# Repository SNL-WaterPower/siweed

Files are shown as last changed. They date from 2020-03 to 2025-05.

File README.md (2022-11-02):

<!-- TABLE OF CONTENTS -->
## Table of Contents

* [About the Project](#about-the-project)
* [Getting Started](#getting-started)
  * [Prerequisites](#prerequisites)
  * [Installation](#installation)
  *	[Running the GUI](#running-the-gui)
* [System Layout](#System-layout)
* [System Specifications](#System-Specifications)
* [Roadmap](#roadmap)

<!-- ABOUT THE PROJECT -->
## About The Project

The Sandia Interactive Wave Energy Education Display (SIWEED) is a small portable wave tank to be used for outreach and engagement on wave energy converters (WECs) and, in particular, WEC control.
Check out these videos to get a better idea of what SIWEED's all about:

 - [SIWEED video](https://youtu.be/PcOHZWLTsHc)
 - [SIWEED live demonstration](https://digitalops.sandia.gov/Mediasite/Play/bbe17add12244893bdbcaecbce89f8881d)

If you're interested in building your own SIWEED, check out the [Getting Started](#getting-started) section of this README.
(We're working on a paper for [*HardwareX*](https://www.hardware-x.com/) that will hopefully provide an even better guide along with some data analysis from using the system.)
If you're an educator or student in need of teaching materials/activities, checkout out the [Educational Materials document](https://github.com/SNL-WaterPower/siweed/blob/master/educational_material.md).

<!-- GETTING STARTED -->
## Getting Started

### Prerequisites
- SIWEED requires 
	- [Arduino IDE 1.8.13](https://www.arduino.cc/en/main/software) or higher for programming Arduinos
		- Libraries are included in the repo. Many are modified, so you need to use the versions in the repo.
		- Arduino SAM boards package
	- [Processing IDE 3.5.4](https://processing.org/download/) for programming the GUI
		- Libraries are included in the repo. Many are modified, so you need to use the versions in the repo.
	- [OSSI Interface](https://www.oceansensorsystems.com/products.htm) for configuring Wave Probes, if equipped.

### Installation

1. Download the latest version of [Arduino IDE](https://www.arduino.cc/en/main/software) 
2. Download version 3.5.4 of [Processing IDE](https://processing.org/download/)
2.5. If using wave probes, download latest version of [OSSI Interface](https://www.oceansensorsystems.com/products.htm)
3. Download the [Master SIWEED Repository](https://github.com/SNL-WaterPower/siweed/tree/master)
4. Change the Sketchbook Location for the Arduino IDE to \siweed\Arduino
```
Open Arduino IDE
Change the location of your sketchbook folder to ~\siweed\Arduino at File > Preferences > Sketchbook location to 
Ex: C:\Users\user\Documents\GitHub\siweed\Arduino
```
5. Change Arduino IDE board to "Arduino Due Programming Port"
```
This can be found at Tools > Board > Arduino ARM(32 - bits) Boards > Arduino Due Programming Port

If you do not see the Arduino ARM(32 - bits) Boards, you need to install the SAM boards package by going to tools > board > boards manager, searching SAM, 
and installing the SAM package.
```
6. Upload the sketches to the Arduinos
```
With the Arduinos connected, select a port in tools > port, be sure to choose a port with an arduino plugged in. Go to file > sketchbook, and open WaveMaker_Controller.
Upload the sketch. 

Switch the port to the other arduino, and open WEC_Controller. Upload the sketch. That is all for the arduinos, you can close the IDE if you wish.
```
7. Open the Processing IDE Change Sketchbook Location to \siweed\Processing
```
Open Processing IDE
Change the location of your sketchbook folder to ~\siweed\Processing at File > Preferences > Sketchbook location to 
Ex: C:\Users\user\Documents\GitHub\siweed\Processing
```
<!-- Running the GUI -->
### Running the GUI
1. Open processing.exe 
2. File > Open > siweedGUI.pde (Ex: C:\Users\user\Documents\GitHub\siweed\Processing\siWeedGUI\siweedGUI.pde)
3. (optional)Edit modifiers. These are booleans at the top of the code that will do things like enable basic mode, debugging, or data logging.
4. If using wave probes: edit the port names in the modifiers to match the ports of your probes. The port names can be found in the device manager, or using the OSSI Interface program. Also within the OSSI Interface program, the tempurature output of any probes needs to be turned off, and the baud rate should be set to 30hz.
5. Click "Run"
6. The GUI will open, allow some time for it to load.

<!-- System layout -->
## System layout
SIWEED uses a PC to control two Arduino Dues: (1) to run the wavemaker and (2) to run the WEC.
A detailed illustration of the system layout is shown in the diagram below.

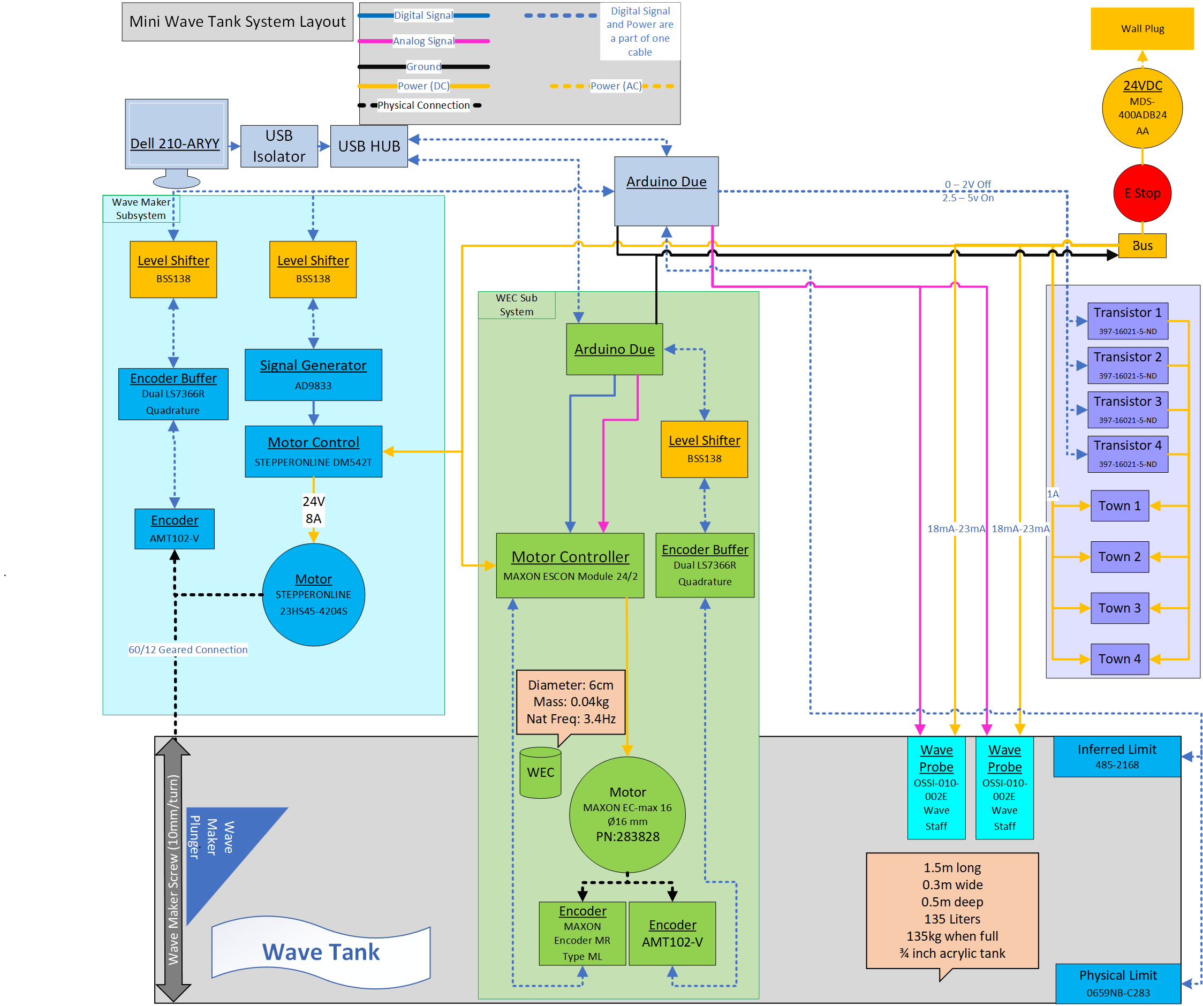
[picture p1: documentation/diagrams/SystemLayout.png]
system layout

<!-- System Specifications -->
## System specifications
 - Tank
 	- 3/4 inch acrylic tank
 	- Inner dimension: 1.5m x 0.3m x 0.5m (filled to ~0.3m deep)
 	- Mass of water: 135 kg (~300lbs)
 	- Mass of dry tank: ?
 	- Volume: 135 L (~36 gal)
 - WEC: 
 	- Diameter: 12 cm
   	- Mass: 0.04 kg list item		!!needs updating
   	- Natural frequency: ~3.4 Hz list item	!!needs updating
 - System update rates:
 	- Processing (GUI): 30 Hz
 	- Arduinos:
 		- Wave maker
 			- General: 100 Hz
 			- Serial communication: 30 Hz
 		- WEC
 			- General: 100 Hz
 			- Serial communication: 30 Hz
	-Wave Probes: 30Hz

<!-- ROADMAP -->
## Roadmap

See the [open issues](https://github.com/SNL-WaterPower/siweed/issues) for a list of proposed features (and known issues).

## Copyright and license
Copyright 2021 National Technology & Engineering Solutions of Sandia, LLC (NTESS).
Under the terms of Contract DE-NA0003525 with NTESS, the U.S. Government retains certain rights in this software.
The software is distributed under a [GNU General Public License](COPYING).

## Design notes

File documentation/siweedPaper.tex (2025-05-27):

%  LaTeX support: latex@mdpi.com 
%  For support, please attach all files needed for compiling as well as the log file, and specify your operating system, LaTeX version, and LaTeX editor.

%=================================================================
\documentclass[hardware,article,submit,pdftex,moreauthors]{Definitions/mdpi} 

%--------------------
% Class Options:
%--------------------
%----------
% journal
%----------
% Choose between the following MDPI journals:
% acoustics, actuators, addictions, admsci, adolescents, aerobiology, aerospace, agriculture, agriengineering, agrochemicals, agronomy, ai, air, algorithms, allergies, alloys, analytica, analytics, anatomia, animals, antibiotics, antibodies, antioxidants, applbiosci, appliedchem, appliedmath, applmech, applmicrobiol, applnano, applsci, aquacj, architecture, arm, arthropoda, arts, asc, asi, astronomy, atmosphere, atoms, audiolres, automation, axioms, bacteria, batteries, bdcc, behavsci, beverages, biochem,
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

% Contact information of the corresponding author
\corres{Correspondence: rcoe@sandia.gov}

% Current address and/or shared authorship
% \firstnote{Current address: Affiliation.}  % Current address should not be the same as any items in the Affiliation section.
% \secondnote{These authors contributed equally to this work.}
% The commands \thirdnote{} till \eighthnote{} are available for further notes

%\simplesumm{} % Simple summary

%\conference{} % An extended version of a conference paper

% Abstract (Do not insert blank lines, i.e.,~\\) 
\abstract{
Wave energy converters are a nascent energy generation technology that harnesses the power in ocean waves.
To assist in communicating both fundamental and complex concepts of wave energy, a small-scale portable wave tank and wave energy converter have been developed.
The system has been designed using commercial off-the-shelf components, and all design hardware and software are openly available for replication.
This project builds on prior research conducted at Sandia National Laboratories, particularly in the areas of WEC device design and control systems.
By showcasing the principles of causal feedback control and innovative device design, SIWEED not only serves as a practical demonstration tool but also enhances the educational experience for users.
This paper presents the detailed system design of this tool.
Furthermore, via testing and analysis, we demonstrate the basic functionality of the system.
}

% Keywords
\keyword{wave energy; educational; outreach} 

% The fields PACS, MSC, and JEL may be left empty or commented out if not applicable
%\PACS{J0101}
%\MSC{}
%\JEL{}

%%%%%%%%%%%%%%%%%%%%%%%%%%%%%%%%%%%%%%%%%%
% Only for the journal Diversity
%\LSID{\url{http://}}

%%%%%%%%%%%%%%%%%%%%%%%%%%%%%%%%%%%%%%%%%%
% Only for the journal Applied Sciences
%\featuredapplication{Authors are encouraged to provide a concise description of the specific application or a potential application of the work. This section is not mandatory.}
%%%%%%%%%%%%%%%%%%%%%%%%%%%%%%%%%%%%%%%%%%

%%%%%%%%%%%%%%%%%%%%%%%%%%%%%%%%%%%%%%%%%%
% Only for the journal Data
%\dataset{DOI number or link to the deposited data set if the data set is published separately. If the data set shall be published as a supplement to this paper, this field will be filled by the journal editors. In this case, please submit the data set as a supplement.}
%\datasetlicense{License under which the data set is made available (CC0, CC-BY, CC-BY-SA, CC-BY-NC, etc.)}

%%%%%%%%%%%%%%%%%%%%%%%%%%%%%%%%%%%%%%%%%%
% Only for the journal Toxins
%\keycontribution{The breakthroughs or highlights of the manuscript. Authors can write one or two sentences to describe the most important part of the paper.}

%%%%%%%%%%%%%%%%%%%%%%%%%%%%%%%%%%%%%%%%%%
% Only for the journal Encyclopedia
%\encyclopediadef{For entry manuscripts only: please provide a brief overview of the entry title instead of an abstract.}

%%%%%%%%%%%%%%%%%%%%%%%%%%%%%%%%%%%%%%%%%%
% Only for the journal Advances in Respiratory Medicine and Smart Cities
%\addhighlights{yes}
%\renewcommand{\addhighlights}{%

%\noindent This is an obligatory section in “Advances in Respiratory Medicine'' and ``Smart Cities”, whose goal is to increase the discoverability and readability of the article via search engines and other scholars. Highlights should not be a copy of the abstract, but a simple text allowing the reader to quickly and simplified find out what the article is about and what can be cited from it. Each of these parts should be devoted up to 2~bullet points.\vspace{3pt}\\
%\textbf{What are the main findings?}
% \begin{itemize}[labelsep=2.5mm,topsep=-3pt]
% \item First bullet.
% \item Second bullet.
% \end{itemize}\vspace{3pt}
%\textbf{What is the implication of the main finding?}
% \begin{itemize}[labelsep=2.5mm,topsep=-3pt]
% \item First bullet.
% \item Second bullet.
% \end{itemize}
%}

%%%%%%%%%%%%%%%%%%%%%%%%%%%%%%%%%%%%%%%%%%
\begin{document}

%%%%%%%%%%%%%%%%%%%%%%%%%%%%%%%%%%%%%%%%%%
\section{Introduction}
Wave energy converters (WECs) have the potential to deliver renewable energy to the grid or other autonomous power demands~\cite{Hagerman:2011aa,Clement2002,FALCAO2010899}.
Research and development in this field have produced some notable improvements in WEC performance, but~the technology is still in a developmental phase and has not achieved broad adoption.
The Sandia Interactive Wave Energy Education Display (SIWEED; a video showing the system in operation is available online: %MDPI: 1. Footnotes are not supported in our journal. We have therefore included this paragraph in the main text. Please confirm. 2. Please add the access date for ALL URLs (Format: Date Month Year). e.g., (accessed on 1 January 2020). It should be before the accepted date. The following highlights are the same. %RGC: ok
 \url{https://youtu.be/PcOHZWLTsHc?si=CzyYw3yEPqnsiVeV}, access date: 23 May 2025) is a small-scale wave tank and WEC that is designed to be portable and serve in the outreach and dissemination of wave energy research.
The development of this system was inspired by previous research at Sandia National Laboratories in the areas of WEC device and control design and testing.
Specifically, the~SIWEED demonstrates the causal feedback control and device design principles described by \citet{Bacelli2020} and \citet{Coe:2021aa}.

A wide variety of similar educational wave tanks and tow tanks have been built, but~few have been documented.
\citet{unger2006creating} reworked a tow tank at MIT to enable remote operation via the internet.
A tank with a similar scale ($\sim$2\,m) and focus was developed in~\cite{Trust2015}, but it was~oriented at demonstrating the effectiveness of coastal flood controls.
There seems to have been two major iterations, one electrically driven by a paddle-like wave maker, and~one plunger type driven mechanically by hand. 
That same team has created multiple similar hydraulic flume tanks for demonstration purposes.
An educational wave tank is currently on display at the National Museum of Scotland, but~the waves do not interact with any bodies on the surface~\cite{Ivan2016}.
A wave tank with a similar educational mission focused around wave energy was developed by Maynooth University \cite{Maynooth}.
In some cases, ``virtual wave tanks'' have been developed for teaching purposes~\cite{Ryu:2003aa}.
Additionally, there are some examples of the educational activities of WECs that do not involve physical wave tanks~\cite{Huynh:2016aa,Satriawan:2022aa,Satriawan:2024aa}.

Relative to these other works, the~SIWEED project was focused on the following key contributions:

\begin{itemize}
  \item \textbf{Open-source and documented design:} %MDPI: Please confirm if the bold formatting is necessary; if not, please remove it. The following highlights are the same. % RGC: prefer to keep bold formatting
 To our knowledge, the~SIWEED is the first educational wave tank and WEC system to be fully documented with an open-source design and software package.
  This will enable interested researchers and students to efficiently develop replicates and variations of the SIWEED design for their own~purposes.
  \item \textbf{Portability:} To allow for transport to conferences and outreach events, the~SIWEED has been specifically designed for easy transportation.
  \item \textbf{WEC control:} In addition to demonstrating the physics of ocean waves, the~SIWEED allows users to interact with a WEC control system to better understand the principles of reactive feedback control to maximize power absorption for the waves.
  \item \textbf{Student-led design:} The SIWEED project has been a student-led design project involving undergraduate engineering students.
  \item \textbf{Curriculum:} The SIWEED repository includes a curriculum for students K--12 based on the Next Generation Science Standards~\cite{NextGenScience2021}. 
  The repository contains a presentation and a document intended to be given to the teacher beforehand.
  The presentation explains water power and Sandia National Labs' role within the field,~then goes into more detail about wave energy converters and how the SIWEED system works.
  The teacher resources document contains general information about the project and~a multitude of resources surrounding wave energy education, including videos, worksheets, vocabulary words, general topics, and~Next Generation Science standards for each grade level.
  By facilitating educational outreach, the~SIWEED can help engage students in this field and inspire them to pursue careers in this field.
\end{itemize}

SIWEED is a novel expansion of similar small-scale educational wave tanks, as~the wave maker is driven by a ball screw and~the user is able to control both the waves and the WEC device.
The parameters of the wave are also fully controllable with a number of operational modes (see Table~\ref{tab:wave_maker_controls}).
The sea state mode outputs a JONSWAP spectrum~\cite{Hasselmann1973} to imitate a natural wave environment with random waves (note that pseudo-random phasing is used).
Initially, the~primary intended audience for SIWEED was college students and above, but~there now exists a curriculum in the design files for lower age groups and~the GUI can be toggled to run a simplified~version.

\begin{table}[H]
  \caption{Wave maker function modes and control~parameters.} 
%MDPI: Please confirm the alignment change. RGC: confirmed
%MDPI: Please note: 1. Figures and Tables should be cited after where they are first mentioned, we have adjusted all. 2. The size and position of figures/tables will be adjusted appropriately to avoid blank space and to ensure the clarity and readability of the image during the final steps. RGC: OK

  \label{tab:wave_maker_controls}
  
  \begin{tabularx}{\textwidth}{LL}
  \toprule
  \textbf{Control Mode}      & \textbf{Input Parameters}        \\
  \midrule
  Jog                        & Position, $z$ {[}mm{]}                \\
  \midrule
  \multirow{2}{*}{Function}  & Amplitude, $A$ {[}mm{]}               \\
                             & Frequency, $f$ {[}Hz{]}               \\
  \midrule
  \multirow{3}{*}{Sea state} & Significant wave height, $H_s$ {[}mm{]} \\
                             & Peak frequency, $f_p$ {[}Hz{]}          \\
                             & Peakedness, $\gamma$ {[} {]}               \\       
  \bottomrule
  \end{tabularx}
\end{table}
\unskip

\section{Design} 
% Describe the hardware, highlighting the customization rather than the steps of the procedure. Highlight how it differs/which advantage it offers over pre-existing methods. For~example, how could this hardware: be compared to other hardware in terms of cost or ease of use, be used in the development of further designs in a particular area, and~so on. Add 3-5 bulleted points to broadly explain to other researchers how the hardware could be potentially useful to them, for~either standard or novel laboratory tasks, inside or outside of the original user community.
The SIWEED was composed of a 1.5\,m $\times{}$ 0.3\,m $\times{}$ 0.5\,m acrylic tank, filled to roughly 0.3\,m deep and housing a vertical plunger style wave maker (see, e.g.,~\cite{hyun1976simplified}), as well as~a single body WEC modeled on the WaveBot~\cite{Coe2016a}.
This tank size was chosen to satisfy the competing objectives of keeping the tank small enough to allow for transportation while making the tank large enough to improve repeatability and performance.
Attached to the tank was a scale model of an ocean side town, meant to represent a potential power load.
The town was equipped with four lighting zones, which allowed the simulated power output to be physically represented.
A CAD rendering of the system is shown in Figure~\ref{fig:CAD} and a photograph is shown in Figure~\ref{fig:siweed_photo_with_callouts}.
The system was centrally controlled by a Windows PC running a graphical user interface (GUI) developed using Processing (\url{https://processing.org}) and the controlP5 library (\url{http://www.sojamo.de/libraries/controlP5/}).
Separate hardware nodes were then managed by two~Arduinos.

\begin{figure}[H]
  
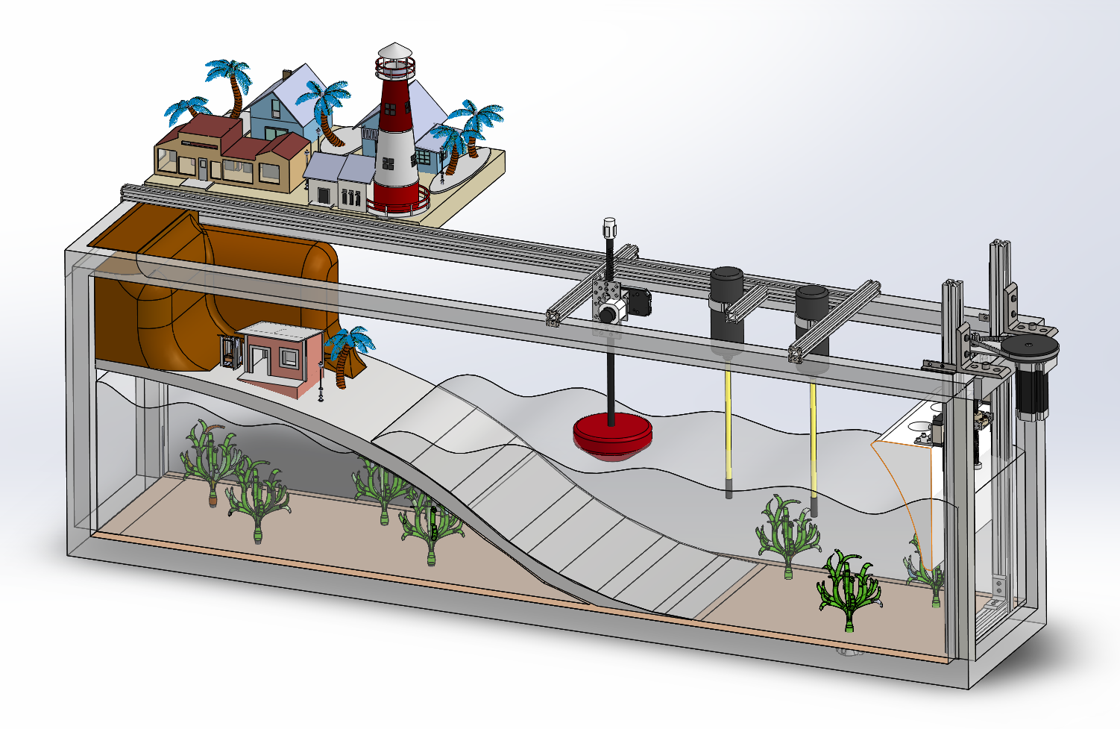
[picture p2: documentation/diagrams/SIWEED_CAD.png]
  
  \caption{SIWEED CAD assembly~rendering.}
  \label{fig:CAD}
\end{figure}
\unskip

\begin{figure}[H]
  
  
  \caption{Photograph of SIWEED system showing key system~elements.}
  \label{fig:siweed_photo_with_callouts}
\end{figure}
\unskip

\subsection{Hardware}
A high-level system diagram for the SIWEED is shown in Figure~\ref{fig:siweed_layout}.
Two Arduino Due micro controllers were used to control and acquire signals from the WEC and wave maker, communicating with the GUI through USB serial.
The Windows laptop acted as the core of the system, with~the two Arduino Dues attached through a USB. 
Each Arduino was then attached to the various devices it communicates with.
It is worth noting that the Arduino Due model was selected for its higher clock speeds, but~since it operated at 3.3\,V, multiple-level shifters were used to enable communication between the Arduino Dues and the components that used 5\,V logic (see detailed electrical diagrams in the Supplementary~Materials).

\begin{figure}[H]
    
  \caption{Basic SIWEED system layout diagram (see the Supplementary Materials for more detailed electrical diagrams).}
  \label{fig:siweed_layout}
\end{figure}

The Windows laptop ran the Processing application that acted as the GUI, data logger, and~serial communication manager.
The Arduinos received their commands from Processing over the USB serial and~performed individual control loops based on control states dictated by the GUI.
One Due controlled the movement of the wave maker plunger, while the other controlled the torque feedback of the WEC and lights in the model town.
Each sent data back to the Processing GUI for data logging and plotting purposes.
The Arduino Dues each had a number of components they communicated with through various protocols (PWM, SPI, Analog).
These performed tasks like encoder buffering, motor control, and~signal generation.
The connections can be seen in the detailed electrical diagrams provided in the Supplementary~Materials.

\subsection{Graphical User~Interface}
The SIWEED GUI is intended to be used with a touchscreen interface, but~it is also fully functional with a mouse/track pad.
A screen shot of the GUI is shown in Figure~\ref{fig:siweed_guiScreenShot}.
It is divided into three sections, with the left instructional side, ``Mission Control'', and~``System~Status''.

\begin{figure}[H]
  \centering
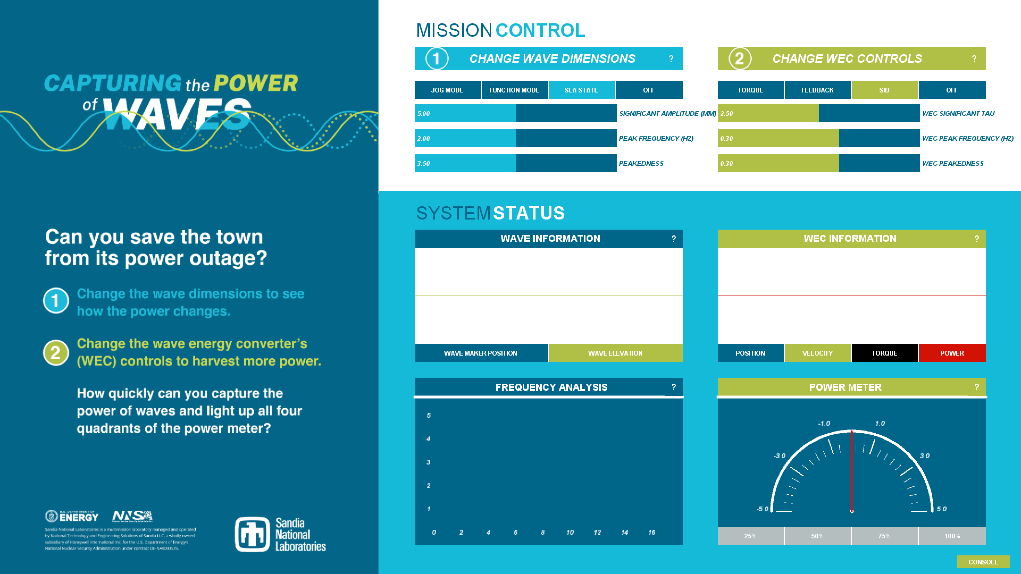
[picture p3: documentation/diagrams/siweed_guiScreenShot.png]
  
  \caption{Graphical user interface (GUI) screenshot.}
   %MDPI: Please change the hyphen (-) into a minus sign (−) in the figure, e.g., “-1” should be “−1”. Same for below Figures 5-7.
   % RGC: we cannot make this change, this is a bitmap, not a vector graphic and the graphics were generated from the Processing library, so decision about characters used in plots were made by Processing
  \label{fig:siweed_guiScreenShot}
\end{figure}

The left side of the ``Mission Control'' section of the GUI pertains to the control of the wave maker, which allows the user to switch between operational modes (``jog'', ``function'', ``sea state'', and ``off'') and set the relevant parameters.
If, for~example, the~system is in ``sea state'' mode, the~user can set the significant wave height ($H_s$), peak frequency ($f_p$), and~peakedness factor ($\gamma$) for a JONSWAP wave spectrum.
The ``function'' mode commands a simple sine wave, and~so the parameters are amplitude and frequency. 
The ``jog'' mode simply commands a static position for the plunger to go to, so the only input parameter is that command position.
There are only as many input sliders displayed as there are inputs to the active control mode. 
For example, if~the selected mode was ``jog'', only one slider would be present in that section of the GUI for the user to interact~with.

The right side of the ``Mission Control'' section of the GUI contains controls for the WEC, which can be set into ``torque'' mode, in which the user directly sets a commanded torque; ``feedback'' mode, where proportional and integral feedback factors can be set by the user; ``SID'' mode for~system identification, allowing for open-loop multi-sine signals to be set by the user; and ``off.''
The ``SID'' mode works with the same inputs and JONSWAP control method as the ``Sea State'' mode for the wave maker, but it~commands torque instead of position.
Where the purpose of the JONSWAP in the wave maker controls is to replicate a natural wave state, as~a torque controller for the WEC, its purpose is only to provide a wide variety of torque inputs. 
This is useful when characterizing the hardware using recorded data in post-analysis (see, e.g.,~\cite{Bacelli2017a}).

The ``System Status'' section shows two plots, one for the WEC and one for the wave maker, with~each allowing the user to choose what data are plotted. 
There are multiple options for the data included in each of these plots, with~the ability to plot any combination of variables simultaneously.
Each data stream is plotted in a different color, allowing the user to differentiate the numerous variables on each plot.
The available variables in the wave maker plot (left side) are ``Wave Maker Position'' (as measured by the encoder) and ``Wave Elevation'' (as measured from one of the submerged wave probes).
The WEC plot variables are ``Position'' (measured from an encoder), ``Velocity'' (differentiated from position), ``Torque'' (derived from a torque constant and motor current), and~``Power'' (as derived below).
Below the plots are a discrete Fourier transform of the generated waves (measured from the encoder) and~a radial meter that displays the hypothetical generated power of the WEC.
That hypothetically generated power meter is driven by the same variable as the ``Power'' variable in the WEC information plot above the meter, given by
\begin{equation}
  P = -\tau \cdot v .
\end{equation}
%
Here, %RGC: no, this should not be indented as a new paragraph
$P$ is the calculated output power, $\tau$ is the torque commanded by the WEC motor controller, and~$v$ is the~velocity.

\section{Build~Instructions}

\subsection{General}
A functionally similar version of this wave tank can be reconstructed using the following guidance: a~high-level system layout diagram in Figure~\ref{fig:siweed_layout} (see detailed electrical diagrams in the Supplementary Materials), the~bill of materials in Table~\ref{tab:bom}, and~the CAD model shown in Figure~\ref{fig:CAD}, which is also included in the design files.
The bill of materials in Table~\ref{tab:bom} includes the essential electronics for the functionality of the device, along with much of the decorative hardware included for the purpose of enhancing the presentation of the wave tank.
Note that mounting hardware is not included in the bill of materials, as~this is not considered functionally specific.
Any suitable alternative that allows the functional components to be securely mounted will~suffice.

Many parts included in the bill of materials can be substituted with functionally similar ones, such as the laptop, transistors, power supply, or~the tank itself.
The specifications of any substitutions must at least meet the capabilities of the original components in the bill of materials.
Software-specific hardware, such as the Arduinos or encoder buffers, should not be~substituted. 

\subsection{Safety}
It is important to consider safety during construction and operation: electrical isolation and grounding, as~well as guarding pinch points, are essential for safe usage.
In the interest of electrical safety, the~user interface of the device (the laptop) is electrically isolated with a simple USB isolator, and~all individual components share a common ground with the power supply where possible.
An emergency stop switch is installed between the power supply and power bus, enabling the device to be shut off at any time should an unexpected and/or dangerous condition occur.
This switch should be made accessible and visible at all times during operation and testing.
The upward-facing drive belt of the wave maker serves as a pinching hazard, and~so it is recommended to construct a barrier for use during normal operation.
This can be 3D printed using the CAD model in the design~files.

\subsection{Hardware}
The hardware of SIWEED consists of the wave maker support structure, the~mini WEC support structure, the~acrylic tank, the~beach, and~the decorative town. 
A similar tank can be sourced as an off-the-shelf part, with~its size selected to suit specific needs---portability and wave stability in this case. 
The beach is made by adhesively attaching a thin acrylic panel over pipes suspended at descending heights by threaded rods, as~shown in Figure~\ref{fig:siweed_photo_with_callouts}.
The decorative texture of the beach is made by mixing sand with two parts epoxy.
The rest of the decorative elements are assembled as per individual included instructions and~arranged strategically on top of a wooden platform embedded with decorative LEDs. 
These LEDs are used to indicate the level of simulated output power generation (i.e., all the buildings illuminate during optimal operation).

The WEC and wave maker support structures are built such that they tightly grip the tank, with~small rubber pads enhancing their stability and preventing scratches.
It is particularly important that the wave maker is securely attached, as~it undergoes significant force during operation.
The wave probes are mounted onto the WEC support structure such that they are level with the surface of the water.
The WEC itself consists of a small foam buoy attached to a carbon fiber tube with a geared rack affixed to it, adjacent to a pinion gear that is both driven by the WEC motor and drives the WEC encoder.
There are a few large washers fixed on top of the buoy to increase its mass, the~number of which can be tuned through trial and error to the size of the tank and waves within~it.

The wave maker consists of a stepper motor driving a belted ball screw.
The stepper motor mount is used to adjust the belt tension.
Both the screw pitch and the pulley ratio of the belt drive can be set as global variables at the beginning of the Arduino source code.
The same goes for the rack and pinion sizes for the WEC.
The ball screw drives a 3D printed spade/plunger to create waves, which is painted to achieve a waterproof surface.
Two infrared limit switches are mounted such that each of their beams is broken when the position of the wavemaker is near its corresponding operational limit.
This is used as a safeguard and~as a point of reference during startup calibration.
More specific details regarding the exact hardware configuration can be found from the CAD model shown in Figures~\ref{fig:CAD} and \ref{fig:siweed_photo_with_callouts}.

\subsection{Electronics}
Figure~\ref{fig:siweed_layout} shows a detailed and accurate configuration of the SIWEED electronics.
It is useful to conceptualize the system in two halves, namely the WEC and wave maker.
Each is controlled by an Arduino Due which communicates with the user-facing laptop through an optically isolated USB cable in~order to prevent ground looping.
Both Arduinos are connected through level shifters to encoder buffers and motor controllers.
Additionally, the~wave maker Arduino is connected to a signal generator via a level shifter and to four high-amperage transistors to control the decorative lights.
All of these electronics, save for the motors and encoders themselves, are mounted inside an enclosure that sits near the SIWEED.
For each of the halves of the system, a~detachable electrical connector is used for ease of transportation and storage.
To prevent cross-talk, the~higher amperage stepper motor circuit has its own connector, physically separated from the rest of the~circuitry.

It is critical for accurate operation that the wave probes are grounded to the wave maker support structure submerged in the water and~that they maintain some distance from the nearest metal grounding point.
The precise distance is dependent on which wave probes are used and~is specified in their~documentation.

%\DTLloaddb{data}{BOM_no_decorations.csv}
%
%\begin{landscape}
%\begingroup
%\footnotesize
%\renewcommand{\dtldisplaystarttab}{\\\toprule}%
%\renewcommand\dtldisplayafterhead{\hline}%
%\renewcommand\dtldisplaystartrow{\hline}%
%\renewcommand{\dtldisplayendtab}{\\\bottomrule}%
%
%\DTLdisplaylongdb[caption=Bill of materials (note: decorations for town not included)., contcaption=Bill of materials (continued)., label=tab:bom]{data}
%\end{landscape}
%\endgroup

\startlandscape
\begin{table}[H]
\footnotesize
\caption{Bill of materials (note: decorations for town not included).}
%MDPI: 1. We moved the table code from csv file to tex. Please double-check if they are correct. 2. To avoild blank space, we moved Table 2 here. Please confirm.
% RGC: Confirmed.
\label{tab:bom}
\begin{tabularx}{\textwidth}{llLrrrl}
\toprule
\textbf{Group} & \textbf{Designator} & \textbf{Component} %MDPI: The companies/manufacturers of chemicals & reagents, devices, instruments, commercial cell lines/samples/materials should be indicated together with their city (states abbreviation is required for USA and Canada) and country in their first appearance. Please review the full text carefully and add the necessary information. Example: Analyzer (Applied Biosystems, Waltham, MA, USA). RGC: confirmed
 & \textbf{Number} & \textbf{Cost per Unit {[}USD{]}} %English Editor: Please check that intended meaning has been retained. RGC: confirmed
 & \textbf{Total Cost {[}USD{]}} & \textbf{Source} \\
\midrule
Electronics & USB isolator  & ADUM4160 100MA USB ISOLATOR BRD & 1 & 34.95 & 34.95 & Digikey \\
Electronics & Arduino Due & Arduino Due & 2 & 37.4  & 74.8  & Digikey \\
Electronics & Level Shifter & BSS138  & 3 & 3.49  & 10.47 & Adafruit  \\
Electronics & Encoder Buffer  & Single LS7366R Quadrature Encoder Buffer  & 2 & 28.65 & 57.3  & SuperDroid Robots \\
Electronics & Encoder & AMT102-V  & 2 & 23.86 & 47.72 & Digikey \\
Electronics & WEC Motor Controller  & ESCON Module 24/2, 4-Q servo controller for DC/EC motors, 2/6 A, 10--24 VDC & 1 & 89.39 & 89.39 & Maxon \\
Electronics & WEC Motor Controller MotherBoard  & ESCON Module 24/2 Motherboard & 1 & 87  & 87  & Maxon \\
Electronics & WEC Motor & Maxon EC-max 16, 283828 & 1 & 190.45  & 190.45  & Maxon \\
Electronics & Wavemaker Motor Controller  & StepperOnline DM542T  & 1 & 19.9  & 19.9  & StepperOnline \\
Electronics & Wavemaker Motor & StepperOnline 23HS45-4204S  & 1 & 33.92 & 33.92 & StepperOnline \\
Electronics & Power Supply  & MDS-400ADB24AA  & 1 & 164.19  & 164.19  & Digikey \\
Electronics & E-stop  & EAO 84-5040.0040  & 1 & 53.95 & 53.95 & Digikey \\
Electronics & Inferred Limit  & 485-2168  & 1 & 5.95  & 5.95  & Digikey \\
Electronics & Wave Probe  & OSSI-010-002E Wave Staff  & 2 & 1075  & 2150  & OSSI  \\
Electronics & Project Enclosure & BOX ABS/PC GRY 19.68''L X 15.74''W  & 1 & 122.65  & 122.65  & Digikey \\
Electronics & Signal Generator  & AD9833 Function Generator   & 1 & 8.95  & 8.95  & ProtoSupplies \\
Electronics & Transistor  & MOSFET N-CH 30V 120A TO220  & 5 & 1.12  & 5.6 & Digikey \\
Electronics & Town Transistor & STMicroelectronics STP160N3LL & 1 & 1.85  & 1.85  & Digikey \\
Electronics & Town LED Expansion Hub  & Just-Plug JP5702  & 1 & 16.99 & 16.99 & Amazon  \\
Electronics & Town LED Lights and Hub Kit & Just-Plug JP5700  & 1 & 20.99 & 20.99 & Amazon  \\
Other & Touchscreen Laptop  & Dell 120-ARYY & 1 & 2200  & 2200  & Dell  \\
Other & 3/4 inch Acrylic Tank (1.5~m $\times$ 0.3~m $\times$ 0.5~m) &   & 1 & 1460  & 1460  & Custom  \\
\bottomrule
\end{tabularx}
\end{table}

\finishlandscape

\subsection{Software~Setup}
On the~laptop:
\begin{enumerate}
\item Download the latest version of Arduino IDE and Processing IDE. %MDPI: Please state the version number of the software. If it is not applicable, the related website or proof should be provided. Please review the full text and make sure each software is mentioned in main text and has a version number or website. % RGC: we already state "latest version"
\item Download the master SIWEED repository.
\item Change the Sketchbook location for the Arduino IDE to \texttt{\textbackslash siweed\textbackslash Arduino}.
\item Change the Sketchbook location for the Processing IDE to \texttt{\textbackslash siweed\textbackslash Processing}.
\item Change the Arduino IDE board to ``Arduino Due Programming Port''.
\item Upload the sketches to the Arduinos.
\item A more detailed version of these instructions can be found in the README file of the repository.
\end{enumerate}

\section{Operating~Instructions}
%Provide detailed instructions for the safe and proper operation of the hardware. 
%> Step-by-step operational instructions for operating the hardware. 
%> Use visual instructions as necessary. 
%> Highlight potential safety hazards.

After performing the setup described in the build instructions, the~project can be operated as~follows:
\begin{enumerate}
\item Power on the wave tank, ensuring any kill switches are closed and~any pinch points are clear.
\item Open processing.exe.
\item File $>$ Open $>$ \texttt{siweedGUI.pde} 
%(Ex: C\textbackslash Users\textbackslash user\textbackslash Documents\textbackslash GitHub\textbackslash siweed\textbackslash Processing\textbackslash 
%\newline siWeedGUI\textbackslash siweedGUI.pde) 
\item (optional) Edit modifiers. These are Booleans at the top of the code that will perform tasks like enabling basic mode, debugging, or~data logging.
\item Click ``Run''.
\item The GUI will open, allowing some time for it to load.
\item In the console, which will either be in the GUI, made visible by pressing the console button in the bottom right corner, or~in the Processing console, depending on your Boolean modifiers, unit tests should be visible that can be used to verify that everything is functioning properly. 
Note that the color of the console button in the GUI is representative of the serial checksum status.
When the received checksum matches the calculated checksum (functioning nominally), the~button will be a green/yellow.
Otherwise it will be gray, indicating one of the Arduinos' checksum statuses does not match, meaning~the system is out of sync.
This will result in the state of the GUI not accurately representing the state of the physical system.
\end{enumerate}

\section{Validation and~Characterization}
%Demonstrate the operation of the hardware and characterize its performance over relevant critical metrics
%> Demonstrate the use of the hardware for a relevant use case. 
%> If possible, characterize performance of the hardware over operational parameters. 
%> Create a bulleted list that describes the capabilities (and limitations) of the hardware. For example consider descriptions of load, operation time, spin speed, coefficient of variation, accuracy, precision and etc. 

A series of analyses were conducted on the hardware and software to confirm the proper functionality of the SIWEED.
These tests ensured that individual components, as well as~the systems they rely on, behaved as expected.
What is not included here is a series of software unit tests that run at the start of every execution of the GUI.
These test specific software functions, as well as the integrity of some of the hardware and serial communications. 
The results of these tests can be found on a per execution basis in the GUI console.
During nominal operation, all unit tests have proven to~pass.

\subsection{Torque Constant Verification}\label{tConstSec}
Due to the desire to keep costs and complexity in check and the small scale of the system, the~SIWEED does not include a direct measurement of the motor torque or force applied to the WEC.
However, we may estimate motor torque and force applied to the WEC from the motor current, which is readily available.
The factory torque constant was verified by logging the position and current of the free-floating WEC while commanding a slow sinusoidal current.
The position displacement time series was converted to a time series of the applied physical torque based on the hydrostatic force due to submerging/lifting the~WEC:
%
\begin{equation}
\begin{aligned}
\tau_{hs} 
&= \sigma F_{hs} \\
&= \sigma \rho g A_{wp} \Delta z
\end{aligned}
\label{eq:hydrostatic_restoring}
\end{equation}
%
Here, $\tau_{hs}$ is torque due to the hydrostatic restoring force, which is the product of the radius of the pinion gear ($\sigma$) and the hydrostatic restoring force ($F_{hs}$).
The hydrostatic restoring force can be modeled as a linear spring effect due to some displacement $\Delta z$, where the stiffness is given by the product of the water plane ($A_{wp}$), density of the water ($\rho$), and~gravity ($g$).
%Torque = pinon radius (M)*  [9810(N/m^3)*pos(m)*pi*radius(m)^2]
It is important to note that the torque calculated from \eqref{eq:hydrostatic_restoring} does not include friction~effects.

Plotting this torque data against the recorded commanded current values gives  \mbox{Figure~\ref{fig:TorqueConstant}.}
The solid red curve in Figure~\ref{fig:TorqueConstant} represents the best linear fit of the entire data set.
However, the~data points at the highest and lowest currents are affected more significantly by static friction; therefore, omitting them from the data set improves the torque constant estimation, as~shown in the dashed purple curve in Figure~\ref{fig:TorqueConstant}.
This provides an estimated torque constant of approximately 7.52\,mNm/A, which is within 4\% of the factory-stated torque constant of 7.8\,mNm/A.

\begin{figure}[H]
  \centering
  
  \caption{Torque (estimated based on hydrostatics) vs. commanded current. Linear trends are fit to estimate/verify motor torque~constant.} % RGC: this figure is the standard output from MATLAB, so I will not be changing it per your suggestion of "hyphen (-) into a minus sign (−)"
  \label{fig:TorqueConstant}
\end{figure}
\unskip

\subsection{Friction Estimation}\label{friction}
As with any mechanical drive train, the~SIWEED WEC's drive train exhibits some finite level of friction.
To more fully understand how motor torque (estimated from motor current as per Section~\ref{tConstSec}) relates to the force applied to the WEC hull, we must estimate the friction present in the WEC's drive train.
Here, we assume that the friction in the WEC's drive train is due primarily to Coulomb~friction.

Since the applied torque in Section~\ref{tConstSec} is being estimated from displacement and the frequency is low (which means that inertial and viscous effects are small), the~friction shows up as a ``constant'' offset from the ideal torque constant and doesn't affect the slope.
This allows the friction to be seen as half the offset between the data points as the wave maker moves up and down.
Plotting the difference between the torque predicted by the linear torque constant with the current and the torque predicted based on hydrostatics gives Figure~\ref{fig:TorqueError}.
The data with lower motor currents ($I < 3$\,A; shown in red in Figure~\ref{fig:TorqueError}) will have lower accelerations and provide better estimates.
The average offset shows that the static friction is about 0.45\,mNm in this operational~envelope.

\begin{figure}[H]
  \centering
  
  \caption{Motor torque error compared with commanded motor~current.} % RGC: this figure is the standard output from MATLAB, so I will not be changing it per your suggestion of "hyphen (-) into a minus sign (−)"
  \label{fig:TorqueError}
\end{figure}
\unskip

\subsection{Wave Probes}	\label{waveprobes}
The readings from the wave probes can be verified by physically attaching the wave probes to the wave maker, which has a very precise encoder that allows for an accurate measurement of changes in displacement.
Moving the wave maker with the wave probe attached and comparing the displacement data from both of them was used to make sure the wave probe was providing accurate~readings.

It was found that having two wave probes quite close together, roughly 1\,ft apart, was problematic.
Changing the depth of one probe seemed to also adjust the reading of the nearby stationary probe.
It is believed this was caused by capacitive coupling between the two wave probes.
Known work-arounds are only using one probe or~powering the second probe off during~operation.

\subsection{WEC Feedback~Control}
The proportional derivative\,(PD) controller functions using the following formula:
%
\begin{equation}  \label{pdctrleq}
  \tau = k_p \cdot p + -k_d \cdot v
\end{equation}
%
Here, $\tau$ is the calculated torque, $k_p$ is the user-defined proportional gain, $p$ is the position in meters, $k_d$ is the user-defined derivative gain, and~$v$ is the velocity in~meters per second, calculated by the change in position over the last 10 ms.
The torque applied by the motor is thus the combined effect of a spring and damper, with~the proportional gain $k_p$ adjusting the strength of the spring and~the derivative gain $k_d$ adjusting the strength of the damper.
Unlike a typical physical spring, this ``spring'' can both push the device towards the center (a stabilizing effect) or~push it away (a destabilizing effect) depending on the sign of the gain.
A positive $k_p$ will act as a destabilizing force, whereas a negative $k_p$ will center the WEC to the waterline, similarly to a physical~spring.

The calculation of \eqref{pdctrleq} is performed on the Arduino Due micro-controller responsible for controlling the WEC, which commands an output torque through PWM to the WEC motor controller.
The position and velocity are determined with an encoder, while the $k_p$ and $k_d$ inputs are set by the user in the GUI, which the Arduino receives through the USB serial.
By logging the inputs and output of the control system through a range of user inputs, its functionality/performance can be verified.
% Control loop response times to be less than 33\,ms, as the data logging control loop runs at 30\,Hz and shows a delay of one sample or less.

Figure~\ref{fig:TorqueCommanded} shows the performance of the controller during typical operation.
These data were collected during a test in which the feedback controller was used to command WEC torque.
The commanded torque was calculated as per \eqref{pdctrleq}, while the measured torque was taken from an analog output on the WEC motor controller that measures current, then multiplying it by the known torque constant (see Section~\ref{tConstSec}).
This comparison illustrates how the PD control algorithm and motor controller react to our given inputs.
As the linearity of the plot shows, the~measured output torque closely matches the expected~torque.
% The standard deviation of the torque during user testing was $3.82 \times 10^{-4}$\,Nm.

\begin{figure}[H]
  \centering
  
  \caption{Comparison %MDPI: Please use scientific notations in the figure, e.g., “8 × 10³”, not “8E3”. % RGC: Updated
 of measured and commanded motor torque with a linear regression and 95\% prediction interval ($2\sigma$); mean absolute error (MAE): $1.25\times{10}^{-4}$.}
  \label{fig:TorqueCommanded}
\end{figure}

To protect the system, a~torque saturation constraint was applied within the WEC controller---this can be adjusted by what is referred to as the ``Thermal Time Constant''.
When commanded to apply a torque over what the controller deems as safe, the~motor controller will apply this torque for only some time before saturating at the maximum nominal torque.
This was observed in targeted testing, occurring around $3.5\times 10^{-3}$\,Nm, but~not during any user tests, as~the commanded torque was never above that threshold.
If it were to become an issue, the range of possible $k_p$ and $k_d$ commands and torque jog commands could be limited within the GUI to avoid any saturation~triggers.

\section{Discussion and~Conclusions}
The SIWEED project was developed to communicate important aspects of WEC design, performance, and~control while adhering to the open source philosophy.
This paper provides the resources necessary to understand and even reproduce the SIWEED while demonstrating the basic functionality of the system through basic testing and analysis.
This paper can be used as a resource along with the GitHub site (see Data Availability Statement), which tracks detailed design files, source code, etc.
This information should enable users of the SIWEED and developers of other similar systems to better understand the fundamental concepts of wave~energy.

This project aims to demonstrate the feasibility of harnessing wave energy as a sustainable and renewable resource while actively involving the public in the learning process.
This SIWEED is a simple, accessible, and~reproducible tool for outreach and engagement.
As an open source project, the~SIWEED encourages collaboration and contributions from the scientific community, fostering innovation and improvements in the modeling, control, and~design of WECs.
Through its educational outreach efforts, the~SIWEED can actively engage students in this field and encourage them to explore career opportunities within it.
To-date, the~SIWEED has been employed in multiple demonstrations that have involved over 500 elementary school students in total.
In addition, the~SIWEED was invited to participate in ``American Possibilities: A White House Demo Day'', attended by many influential governmental officials.
These types of outreach activities are precisely the kind that were envisioned when the SIWEED was originally~conceptualized.

Work to date on the system has focused on its basic functionality and other activities that directly supported our goal of enabling educational outreach activities.
However, there are many potential areas for future work with the SIWEED system.
These future work areas would not only help to improve the functionality of the SIWEED system but~also provide excellent project-based learning opportunities for students.
Using the system as is, different combinations of wave amplitudes and frequencies could be studied to assess the system's ability to generate these waves and maintain good absorption via a beach.
Filters could be designed for the system's analog signals (e.g., motor current and wave height).
Although we have operated the system for a substantial number of demonstrations, more systematic long-term operational tests to assess the system's reliability could also be conducted.
Beyond these initiatives to better characterize the system as currently built, improvements to the SIWEED system's wave probes' signal and their signal process, transitioning the GUI from Processing to a more broadly used framework and~experiments involving changes to the WEC hull shape, are of~interest.

\vspace{6pt}

\supplementary{The following supporting information can be downloaded at:  \linksupplementary{s1}.

%MDPI: Please check if any short description about Supplementary Materials should be added.
\vspace{12pt}
{\footnotesize
\setlength{\cellWidtha}{\columnwidth/3-2\tabcolsep--0.3in}
\setlength{\cellWidthb}{\columnwidth/3-2\tabcolsep-0.9in}
\setlength{\cellWidthc}{\columnwidth/3-2\tabcolsep--0.6in}
\noindent
\scalebox{1}[1]{\begin{tabularx}{\columnwidth}{>{\PreserveBackslash\raggedright}m{\cellWidtha}>{\PreserveBackslash\raggedright}m{\cellWidthb}>{\PreserveBackslash\raggedright}m{\cellWidthc}}
\toprule

\textbf{\boldmath{File Name}} & \textbf{\boldmath{File Type}} & \textbf{\boldmath{Description}}\\
\cmidrule{1-3}
Arduino/libraries 				& Directory & Standard Arduino~libraries\\
Arduino/WaveMaker\_Controller 	& Directory & Arduino source for wave~maker\\
Arduino/WEC\_Controller 		& Directory & Arduino source for~WEC\\
CODE\_OF\_CONDUCT.md 			& Markdown & Repository code of~conduct\\
contributing.md 				& Markdown & Repository contributing~guide\\
COPYING 						& ASCII & Copyright\\
documentation 					& Directory & Journal paper; electrical~diagrams\\
educational\_material.md 		& Markdown & Teacher/student material and~guide\\
matlabExamples 					& Directory & Simple MATLAB analysis~examples\\
miniWaveModel.slx 				& Simulink & Simple Simulink model for~prototyping\\
Processing 						& Directory & Graphic user interface~code\\
README.md 						& Markdown & Basic information about the~project\\
\bottomrule
\end{tabularx}}
}
}
\vspace{6pt}

%%%%%%%%%%%%%%%%%%%%%%%%%%%%%%%%%%%%%%%%%%
\authorcontributions{Conceptualization, R.G.C. and~G.B.; methodology, R.G.C., G.B., S.J.S., A.G.M., and D.D.F.; investigation, N.R., D.H., A.G.M., K.D., and A.F.; writing, N.R., A.G.M., and R.G.C.; project administration, R.G.C.; funding acquisition, R.G.C. All authors have read and agreed to the published version of the~manuscript.}

\funding{This project was supported by %MDPI: Please check the accuracy of funding data (especially funding number) and any other information carefully. Any errors may affect your future funding. % RGC: confirmed
 the US Department of Energy's Water Power Technologies~Office.}

% \institutionalreview{\hl{~~~}} 
%MDPI: {In this section, you should add the Institutional Review Board Statement and approval number, if relevant to your study. You might choose to exclude this statement if the study did not require ethical approval. Please note that the Editorial Office might ask you for further information. Please add “The study was conducted in accordance with the Declaration of Helsinki, and approved by the Institutional Review Board (or Ethics Committee) of NAME OF INSTITUTE (protocol code XXX and date of approval).” for studies involving humans. OR “The animal study protocol was approved by the Institutional Review Board (or Ethics Committee) of NAME OF INSTITUTE (protocol code XXX and date of approval).” for studies involving animals. OR “Ethical review and approval were waived for this study due to REASON (please provide a detailed justification).” OR “Not applicable” for studies not involving humans or animals.}

% \informedconsent{\hl{~~~}} 
%MDPI: Any research article describing a study involving humans should contain this statement. Please add ``Informed consent was obtained from all subjects involved in the study.'' OR ``Patient consent was waived due to REASON (please provide a detailed justification).'' OR ``Not applicable'' for studies not involving humans. You might also choose to exclude this statement if the study did not involve humans. Written informed consent for publication must be obtained from participating patients who can be identified (including by the patients themselves). Please state ``Written informed consent has been obtained from the patient(s) to publish this paper'' if applicable.

\dataavailability{This project has been documented through a GitHub repository: \url{https://doi.org/10.5281/zenodo.7502669}.} 

\acknowledgments{Francisco Colorbio, John Quinlan, and~Sean Pluemer worked on an earlier version of the SIWEED project on which this current version was based.
Sandia National Laboratories is a multi-mission laboratory managed and operated by National Technology and Engineering Solutions of Sandia, LLC., a~wholly owned subsidiary of Honeywell International, Inc., for~the U.S. Department of Energy's National Nuclear Security Administration under contract DE-NA0003525.
This paper describes objective technical results and analysis.
Any subjective views or opinions that might be expressed in the paper do not necessarily represent the views of the U.S. Department of Energy or the United States~Government.
}

\conflictsofinterest{The authors declare no conflicts of~interest.} 

%%%%%%%%%%%%%%%%%%%%%%%%%%%%%%%%%%%%%%%%%%
%% Optional

%% Only for journal Encyclopedia
%\entrylink{The Link to this entry published on the encyclopedia platform.}

\abbreviations{Abbreviations}{
The following abbreviations are used in this manuscript:\\

\noindent 
\begin{tabular}{@{}ll}
SIWEED & Sandia Interactive Wave Energy Education Display\\
WEC & wave energy converter\\
GUI & graphic user interface\\
JONSWAP & Joint North Sea Wave Project\\
CAD & computer-aided design\\
PWM & pulse width modulation\\
SPI & serial peripheral interface\\
SID & system identification\\
IDE & integrated development environment\\
USB & universal serial bus\\
PD & proportional derivative\\
RMS & root mean square\\
LED & light-emitting diode
\end{tabular}
}

% %%%%%%%%%%%%%%%%%%%%%%%%%%%%%%%%%%%%%%%%%%
% %% Optional
% \appendixtitles{no} % Leave argument "no" if all appendix headings stay EMPTY (then no dot is printed after "Appendix A"). If the appendix sections contain a heading then change the argument to "yes".
% \appendixstart
% \appendix
% \section[\appendixname~\thesection]{Bill of materials\label{sec:detailed_design_documents}}
% A detailed bill of materials is provided in Table~\ref{tab:bom}.

% \begin{landscape}
% \begin{figure}[tb]
% 	\centering
% 	\includegraphics[height=0.95\textwidth, width=\linewidth]{diagrams/SIWEED_ElecDrawings_and_UpdatedBOM/PDFs/siweed_electronics.pdf}
% 	\caption{Overall electronics schematic.}
% 	\label{fig:siweed_electronics}
% \end{figure}
% \end{landscape}

% \begin{landscape}
% \begin{figure}[tb]
% 	\centering
% 	\includegraphics[height=0.95\textwidth, width=\linewidth]{diagrams/SIWEED_ElecDrawings_and_UpdatedBOM/PDFs/siweed_electronics_wec_only.pdf}
% 	\caption{WEC electronics schematic.}
% 	\label{fig:siweed_electronics_wec_only}
% \end{figure}
% \end{landscape}

% \begin{landscape}
% \begin{figure}[tb]
% 	\centering
% 	\includegraphics[height=0.95\textwidth, width=\linewidth]{diagrams/SIWEED_ElecDrawings_and_UpdatedBOM/PDFs/siweed_electronics_wavemaker_only.pdf}
% 	\caption{Wave maker electronics schematic.}
% 	\label{fig:siweed_electronics_wavemaker_only}
% \end{figure}
% \end{landscape}

% \begin{landscape}
% \begin{figure}[tb]
% 	\centering
% 	\includegraphics[height=0.95\textwidth, width=\linewidth]{diagrams/SIWEED_ElecDrawings_and_UpdatedBOM/PDFs/siweed_electronics_aux_subsystems.pdf}
% 	\caption{Wave maker electronics schematic.}
% 	\label{fig:siweed_electronics_aux_subsystems}
% \end{figure}
% \end{landscape}

% \subsection[\appendixname~\thesubsection]{}
% The appendix is an optional section that can contain details and data supplemental to the main text---for example, explanations of experimental details that would disrupt the flow of the main text but nonetheless remain crucial to understanding and reproducing the research shown; figures of replicates for experiments of which representative data are shown in the main text can be added here if brief, or as Supplementary Data. Mathematical proofs of results not central to the paper can be added as an appendix.

% \begin{table}[H] 
% \caption{This is a table caption.\label{tab5}}
% \newcolumntype{C}{>{\centering\arraybackslash}X}
% \begin{tabularx}{\textwidth}{CCC}
% \toprule
% \textbf{Title 1}	& \textbf{Title 2}	& \textbf{Title 3}\\
% \midrule
% Entry 1		& Data			& Data\\
% Entry 2		& Data			& Data\\
% \bottomrule
% \end{tabularx}
% \end{table}

% \section[\appendixname~\thesection]{}
% All appendix sections must be cited in the main text. In the appendices, Figures, Tables, etc. should be labeled, starting with ``A''---e.g., Figure A1, Figure A2, etc.

%%%%%%%%%%%%%%%%%%%%%%%%%%%%%%%%%%%%%%%%%%
\begin{adjustwidth}{-\extralength}{0cm}
%\printendnotes[custom] % Un-comment to print a list of endnotes

\reftitle{References}

\bibliography{siweedPaper}

\PublishersNote{}
\end{adjustwidth}
\end{document}

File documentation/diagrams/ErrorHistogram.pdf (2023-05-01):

-8 | -6 | -4 | -2 | 0 | 2 | 4 | 6 | 8
Torque Error(N-m) | #10⁻⁴

0

200

400

600

800

1000

1200

Occurences

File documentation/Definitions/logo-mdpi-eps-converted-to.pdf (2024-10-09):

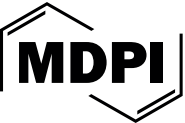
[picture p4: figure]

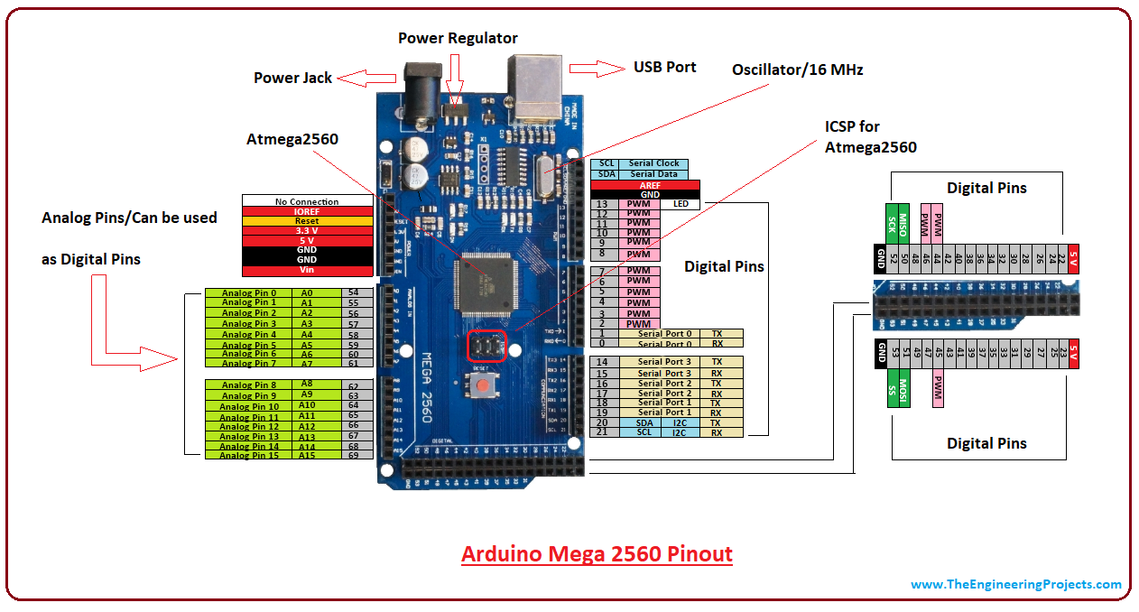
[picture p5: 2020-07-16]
documentation/diagrams/mega pin layout.png

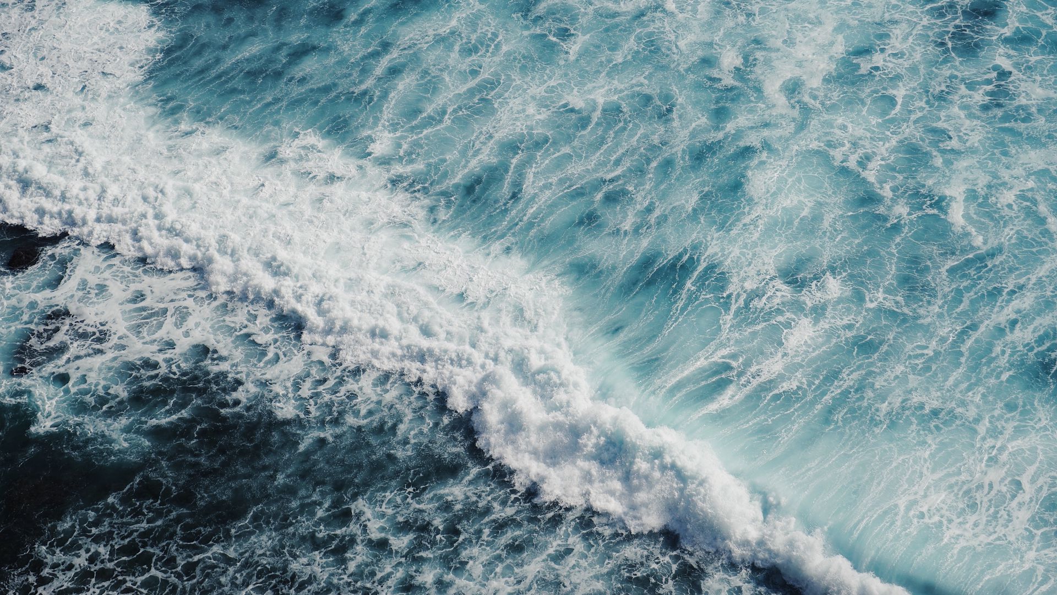
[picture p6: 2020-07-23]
Processing/siWeedGUI/ocean.jpg

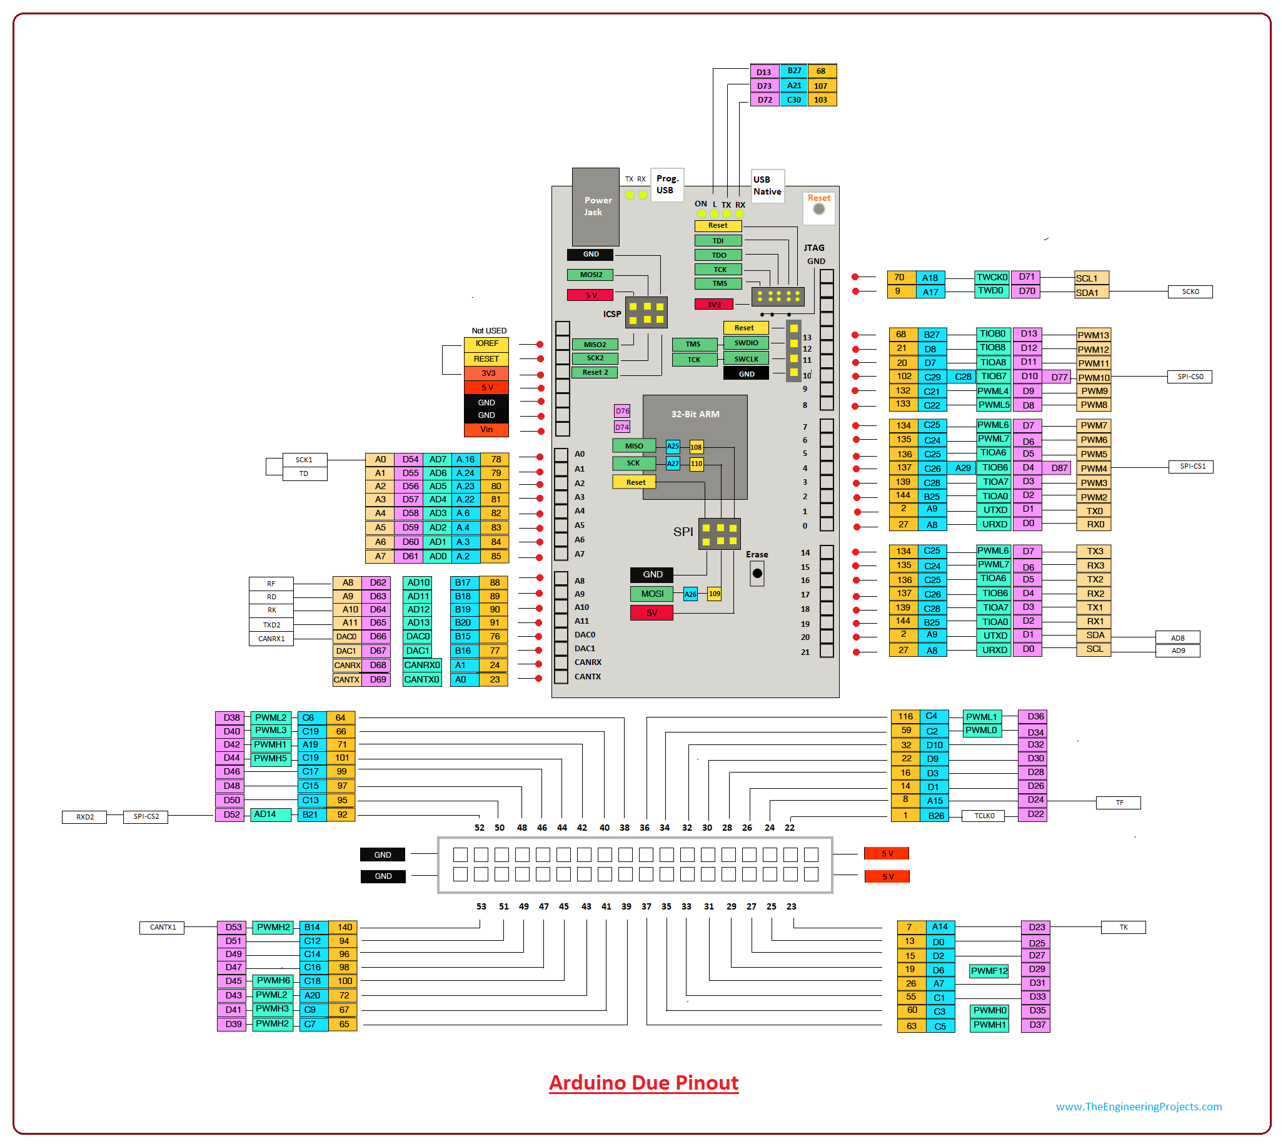
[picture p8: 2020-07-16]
documentation/diagrams/DUE pin layout.png

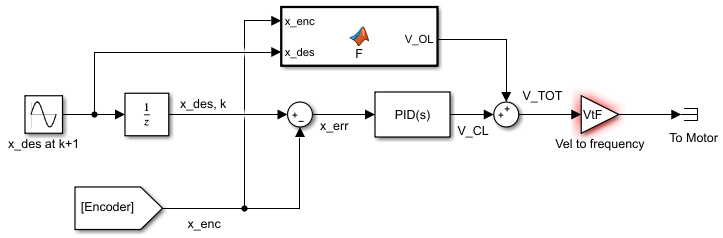
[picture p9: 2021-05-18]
documentation/diagrams/Control Algorithm for PID Controller.png

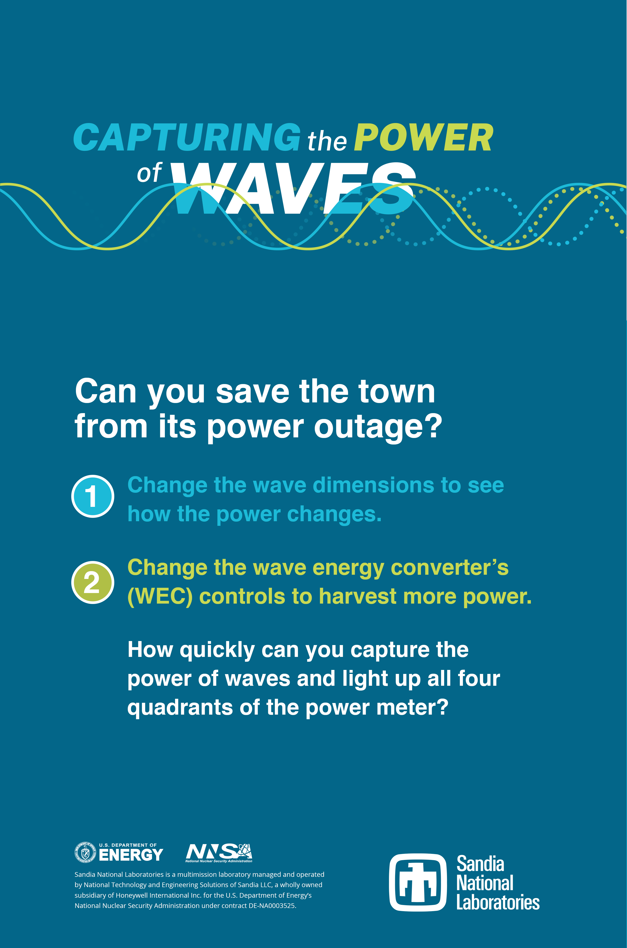
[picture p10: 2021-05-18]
Processing/siWeedGUI/LHS.png

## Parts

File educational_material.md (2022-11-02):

# Introduction
The Sandia Interactive Wave Energy Education Display (SIWEED) gives users a unique hands-on experience with wave energy.
This interactive display comprises a small wave tank (about the size of fish tank), a wave maker, a small wave energy converter, and a small model town.

As students change the waves amplitude and frequency operating a graphic user interface, they observe how the energy generated by the wave energy converter (WEC) changes.
The level of power generated is illustrated by the miniature town, which lights up as the generated power changes.
This experience gives users a rare, up close opportunity to interact with marine hydro kinetic energy, and its possible applications to the blue economy.

There are a variety of science topics that relate to the SIWEED display.
Regardless the grade level students can learn about wave energy in conjunction with grade appropriate science standards.
The SIWEED display offers students a unique opportunity to see the practical applications of the sciences, learn about renewable energy, and engage hands on.
The SIWEED display can be used to show basic science topics, like energy and waves, as well as introduce and start a discussion around climate change, renewable energy, and human impact.

Below is a list of teaching resources, relevant topics, and science standards.
There are also premade slides giving an overview of wave energy and the wave tank, tailored to Elementary School, Middle School, and High School Students.

# Online resources

## Videos 

 - [SIWEED video, Sandia National Labs](https://youtu.be/PcOHZWLTsHc)
 - [SIWEED live demonstration, Sandia National Labs](https://digitalops.sandia.gov/Mediasite/Play/bbe17add12244893bdbcaecbce89f8881d)
 - [Energy 101: Marine and Hydrokinetic Energy Video, US Department of Energy](https://www.youtube.com/watch?v=LXsuU_ZC56E): Great ~2-minute video giving an overview of waterpower. Appropriate for all grade levels.
 - [Advances in WEC Dynamics and Controls, Sandia National Labs](https://www.youtube.com/watch?v=c4npWk_-Pjk): Overview of the controls research being done at Sandia 

## General information

 - [Marine and Hydrokinetic Glossary, Department of Energy](https://www.energy.gov/eere/water/marine-and-hydrokinetic-technology-glossary): High level overview of the different types of devices 
 - [Marine Energy Fact Sheet, Department of Energy](https://www.energy.gov/sites/default/files/2021-05/EERE-water-MarineEnergy-Factsheet-FY21.pdf)
 - [Water Power Overview, National Oceanic and Atmospheric Administration](https://celebrating200years.noaa.gov/magazine/wave_energy/welcome.html)
 - [Overview of the Marine Energy Industry, National Hydropower Association](https://www.hydro.org/waterpower/marine-energy/): Good overview of relevant economic facts regarding Marine Hydro Kinetic Energy
 - [Advantages of Marine Energy ,Department of Energy](https://www.energy.gov/eere/water/advantages-marine-energy)
 - [Women of Water Power, Department of Energy](https://www.energy.gov/eere/water/photos/women-water-power)
 - [Why is Marine Energy the Wave of the Future, Climate Reality Project](https://www.climaterealityproject.org/blog/why-marine-energy-wave-future): Good overview of the advantages of MHK as well as some of the environmental concerns 
 - [Wave Energy and Wave Changes with Depth, Univeristy of Hawaii](https://manoa.hawaii.edu/exploringourfluidearth/physical/waves/wave-energy-and-wave-changes-depth)

## Lessons and worksheets

 - [PRIMRE Educator Resources](https://openei.org/wiki/PRIMRE/STEM/Resources/Educator_Resources): Online database of lesson plans related to Ocean Energy 
 - [Oak Ridge Institute for Science and Education, The Power of Waves Lesson Plan](https://orise.orau.gov/resources/k12/documents/lesson-plans/the-power-of-waves-final-version.pdf) (grades 6-8)
 - [Oregon State University, Wave Power and Generators Lesson Plan](https://smile.oregonstate.edu/lesson/wave-power-and-generators) (grades 6-8 and 9-12)
 - [Department of Energy, Ocean Power Lesson Plan and Activities](https://www.energy.gov/sites/default/files/2014/06/f16/ocean_power.pdf) (grades 5-8)

## Next Gen Science Standards

 - Elementary School 
	 - [K.Forces and Interactions: Pushes and Pulls](https://www.nextgenscience.org/topic-arrangement/kforces-and-interactions-pushes-and-pulls)
	 - [3.Forces and Interactions](https://www.nextgenscience.org/topic-arrangement/3forces-and-interactions)
	 - [4.Energy](https://www.nextgenscience.org/topic-arrangement/4energy)
	 - [4.Waves](https://www.nextgenscience.org/topic-arrangement/4waves)
 - Middle School 
	 - [MS.Forces and Interactions](https://www.nextgenscience.org/topic-arrangement/msforces-and-interactions)
	 - [MS.Energy](https://www.nextgenscience.org/topic-arrangement/msenergy)
 - High School 
	 - [HS.Forces and Interactions](https://www.nextgenscience.org/topic-arrangement/hsforces-and-interactions)
	 - [HS.Energy](https://www.nextgenscience.org/topic-arrangement/hsenergy)
	 - [HS.Waves and Electromagnetic Radiation](https://www.nextgenscience.org/topic-arrangement/hswaves-and-electromagnetic-radiation)
	 - [HS.Human Sustainability](https://www.nextgenscience.org/topic-arrangement/hshuman-sustainability)

# SIWEED lessons and worksheets

## Damping
Wave Energy Converters harvest the energy of waves.
The amount of energy generated by a wave energy converter is not just dependent on the size of the waves, it also depends on how the wave energy converter responds to the waves.
To increase the amount of power generated we use something called dampening.

**Before we get going on the WEC we are going to run a small experiment with just our hands.**

 - For this experiment you are going to press and rub your hands together and record your observations below. 
 - You will run this experiment three times: 
	 1. Once with your hands pressed together as lightly as possible
	 1. Once with medium pressure
	 1. Once while pressing your hands together as hard as you can
 - Take a break between each trial to ensure your hands can cool down. 

| |How much heat did your hands produce| How fast could you rub your hands together|
|-|-|-|
|Pressing hands together lightly| | |
|Pressing hands together moderately| | |
|Pressing hands together hard| | |

**Which trial created the most heat?**

**Complete the sentence:**
As we press our hands together harder, we create ___________ (**more / less**) heat but the speed at which we can rub our hands together __________(**increases / decreases**). 

The heat from our hands is like the power produced by the WEC.
The pressure we apply is equivalent to the damping we apply to the WEC. 

**Based on your observations above fill out your predictions for the WECs behavior.**

| |How much power will the WEC produce?|How fast will the WEC move up and down?|
|-|-|-|
|Low damping| | |
|Moderate damping| | |
|High damping| | |

**Now run an experiment! While keeping the waves consistent change the damping of the WEC and see how the speed and power of the WEC change.**

| |How much power did the WEC produce?|How fast did the WEC move up and down?|
|-|-|-|
|Low damping| | |
|Moderate damping| | |
|High damping| | |

**What was the ideal damping to create the most power?**

**Do these results surprise you? Explain your answer**

## How does the power in ocean waves compare to what we use in our homes

The power in 1 meter of wavefront from an ocean wave can be computed by the following formula:

$$J = \frac{1}{64 \pi}$$ \rho g^2 H_{m0}^2 T_e$$

Here, $\rho$ is the [density of the water](https://en.wikipedia.org/wiki/Seawater#Density) (about 1025 kg/m$^3$ for seawater), $g$ is the [acceleration due to gravity](https://en.wikipedia.org/wiki/Gravitational_acceleration) (9.81 m/s$^2$), $H_{m0}$ is the [significant wave height](https://en.wikipedia.org/wiki/Significant_wave_height) and $T_e$ is the energy period.

A handy trick to find the power in units of kW/m is to use the following equation with $H_{m0}$ in meters and $T_e$ in seconds:

$$J \approx \frac{1}{2} H_{m0}^2 T_e$$

This means that a 1 m wave with an 8 second period would have approximately 4 kW in every meter along its crest.

**Let's compare this with some of the power loads SIWEED's the seaside town display**

|Structure | Daily Energy Use (kWh/day) | Average Power (kW)|
|-- | -- | --|
|Lighthouse lightbulb | 24 | 1.0|
|Lighthouse cottage | 20 | 0.833|
|House | 30 | 1.25|
|General Store | 14.3 | 0.5958|
|Fishing store (beach) | 14.3 | 0.5958|
|Storage building | 3.84 (10 16-watt tube bulbs) | 0.16|
|Shed | 0.96 (4 100-watt bulbs) | 0.04|
|Lamp Posts (6) | 8.64 | 0.36|
|**Total** | **116.04** | **4.835**|

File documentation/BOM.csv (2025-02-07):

Group | Designator | Component | Number | Cost per unit | Total Cost
Electronics | USB isolator | ADUM4160 100MA USB ISOLATOR BRD | 1 | 34.95 | 34.95
Electronics | Arduino Due | Arduino Due | 2 | 37.4 | 74.8
Electronics | Level Shifter | BSS138 | 3 | 3.49 | 10.47
Electronics | Encoder Buffer | Single LS7366R Quadrature Encoder Buffer | 2 | 28.65 | 57.3
Electronics | Encoder | AMT102-V | 2 | 23.86 | 47.72
Electronics | WEC Motor Controller | ESCON Module 24/2, 4-Q servo controller for DC/EC motors, 2/6 A, 10-24 VDC | 1 | 89.39 | 89.39
Electronics | WEC Motor Controller MotherBoard | ESCON Module 24/2 Motherboard | 1 | 87 | 87
Electronics | WEC Motor | Maxon EC-max 16, 283828 | 1 | 190.45 | 190.45
Electronics | Wavemaker Motor Controller | StepperOnline DM542T | 1 | 19.9 | 19.9
Electronics | Wavemaker Motor | StepperOnline 23HS45-4204S | 1 | 33.92 | 33.92
Electronics | Power Supply | MDS-400ADB24AA | 1 | 164.19 | 164.19
Electronics | E-stop | EAO 84-5040.0040 | 1 | 53.95 | 53.95
Electronics | Inferred Limit | 485-2168 | 1 | 5.95 | 5.95
Electronics | Wave Probe | OSSI-010-002E Wave Staff | 2 | 1075 | 2150
Electronics | Project Enclosure | BOX ABS/PC GRY 19.68"L X 15.74"W | 1 | 122.65 | 122.65
Electronics | Signal Generator | AD9833 Function Generator | 1 | 8.95 | 8.95
Electronics | Transistor | MOSFET N-CH 30V 120A TO220 | 5 | 1.12 | 5.6
Electronics | Town transistor | STMicroelectronics STP160N3LL | 1 | 1.85 | 1.85
Electronics | Town LED Expansion Hub | Just-Plug JP5702 | 1 | 16.99 | 16.99
Electronics | Town LED Lights and Hub Kit | Just-Plug JP5700 | 1 | 20.99 | 20.99
Decorations | Lighthouse | https://factorydirecthobbies.com | 2 | 50.38 | 100.76
Decorations | General Store Set | https://www.modeltrainstuff.com | 2 | 119.99 | 239.98
Decorations | House (1 story) | https://www.modeltrainstuff.com | 2 | 21.99 | 43.98
Decorations | Fishing Shack | https://barmillsmodels.com | 2 | 22.95 | 45.9
Decorations | Shed | https://www.mapleleaftrains.com | 2 | 20.48 | 40.96
Decorations | Street Lights | https://factorydirecthobbies.com | 2 | 16.99 | 33.98
Decorations | Seaweed (13 pack) | https://www.modeltrainstuff.com | 2 | 12.99 | 25.98
Decorations | Grass Tufts (withered yellow) | https://www.modeltrainstuff.com | 3 | 12.99 | 38.97
Decorations | Grass Tufts (green) | https://barmillsmodels.com | 3 | 12.99 | 38.97
Decorations | Sand (38 lb) | https://www.mapleleaftrains.com | 2 | 49.99 | 99.98
Decorations | Sandpaper (48 pack) | https://factorydirecthobbies.com | 2 | 12.99 | 25.98
Decorations | Grass Shaker | https://www.modeltrainstuff.com | 2 | 16.99 | 33.98
Decorations | Palm trees | https://www.modeltrainstuff.com | 2 | 11.99 | 23.98
Decorations | Gravel | https://barmillsmodels.com | 2 | 2.49 | 4.98
Decorations | Cliff Rocks | https://www.mapleleaftrains.com | 2 | 16.98 | 33.96
Decorations | Double Sided Tape | https://factorydirecthobbies.com | 4 | 15.99 | 63.96
Decorations | Angle Brace | https://www.modeltrainstuff.com | 5 | 1.78 | 8.9
Decorations | Angle Brace Screws | https://www.modeltrainstuff.com | 6 | 1.28 | 7.68
Decorations | Styrofoam Sheets | https://barmillsmodels.com | 2 | 14.99 | 29.98
Decorations | Foam | https://www.mapleleaftrains.com | 2 | 6.99 | 13.98
Other | Touchscreen laptop | Dell 120-ARYY | 1 | 2200 | 2200
Other | 3/4 inch acrylic tank (1.5m x 0.3m x 0.5m) |  | 1 | 1460 | 1460

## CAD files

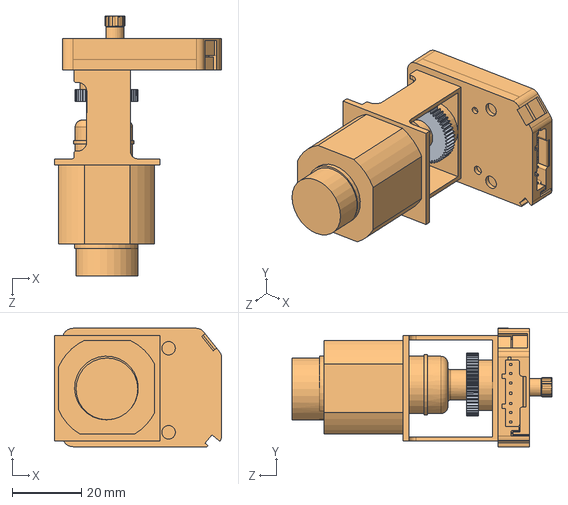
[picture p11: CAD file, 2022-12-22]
documentation/SOLIDWORKS Town/Buoy (all prts)/complete motor.SLDASM
48.2 x 34.2 x 75.0 mm
gear
Motor

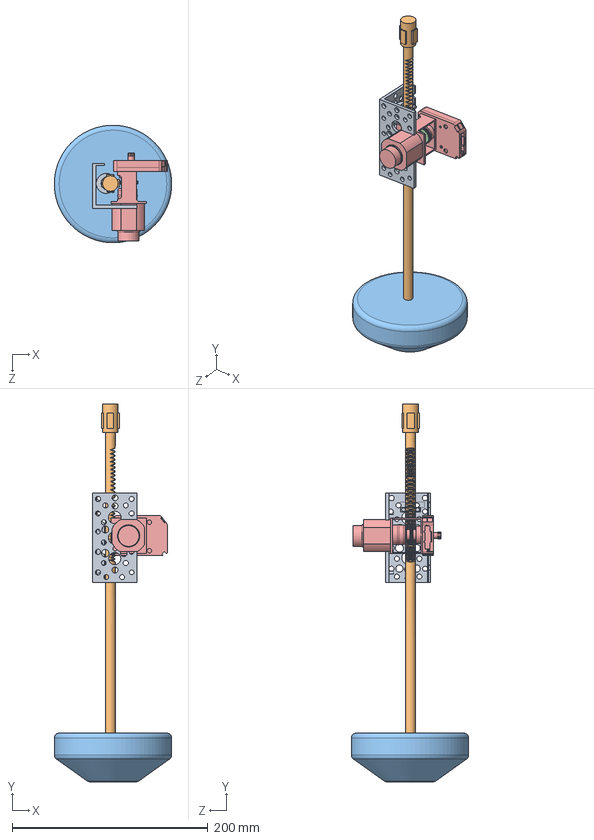
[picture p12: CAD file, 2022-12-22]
documentation/SOLIDWORKS Town/Buoy (all prts)/Buoy Part.SLDASM
120.0 x 386.3 x 119.9 mm
bracket
whole buoy prt
Final buoy
gear
Motor

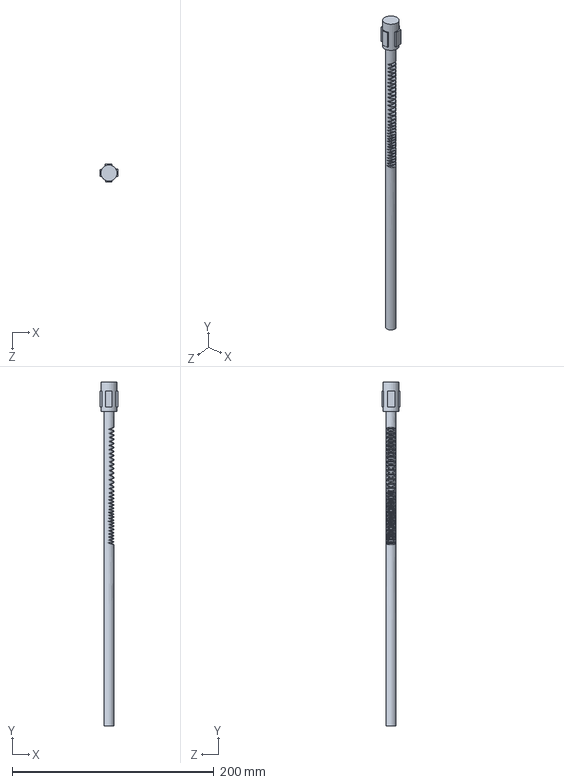
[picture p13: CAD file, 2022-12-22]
documentation/SOLIDWORKS Town/Buoy (all prts)/whole buoy prt.SLDPRT
18.2 x 341.0 x 17.9 mm

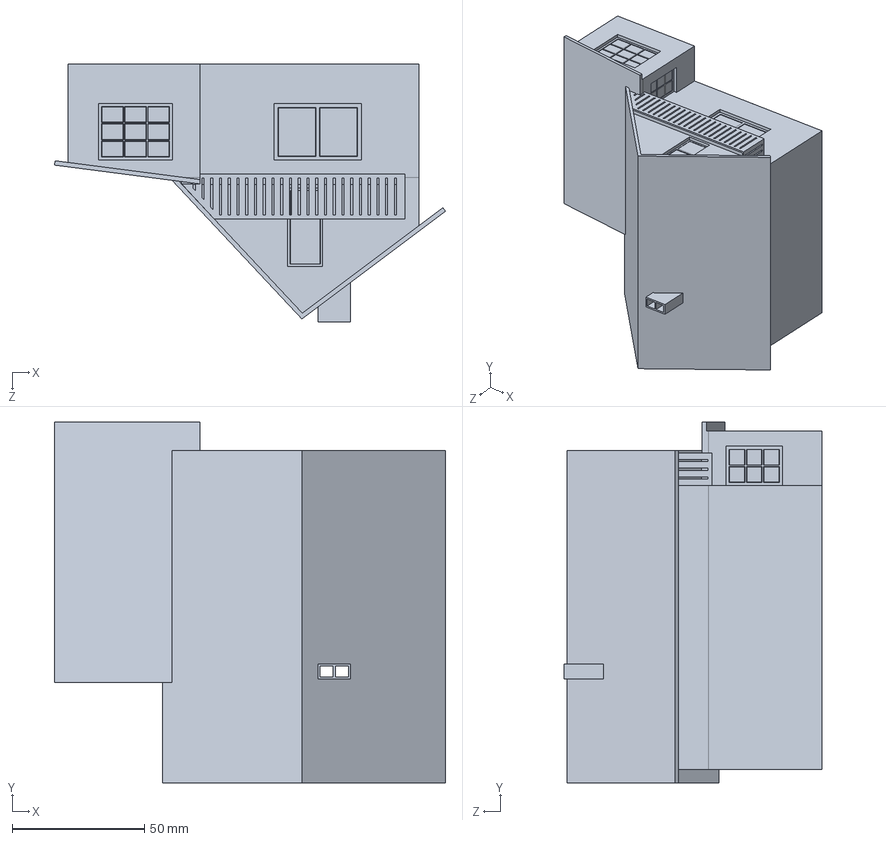
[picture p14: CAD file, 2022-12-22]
documentation/SOLIDWORKS Town/Buildings/Countryside house.SLDPRT
147.6 x 136.1 x 97.4 mm

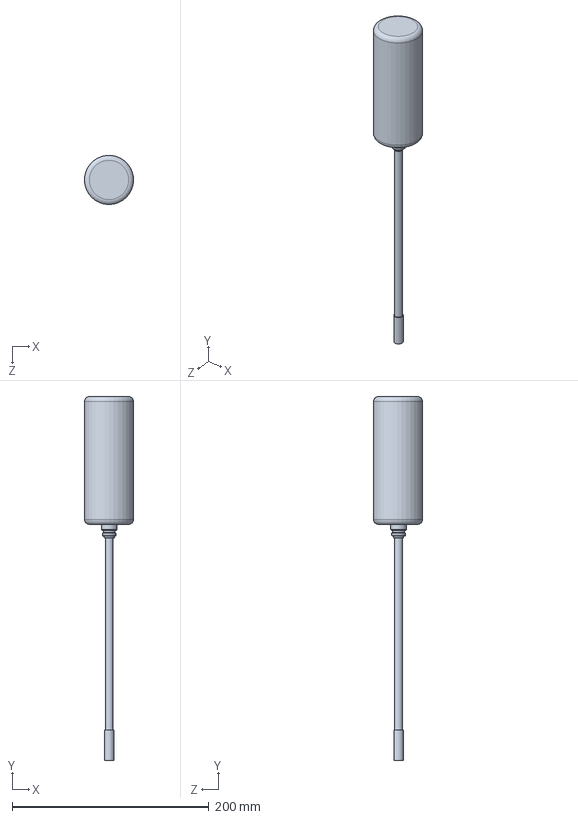
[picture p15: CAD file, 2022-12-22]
documentation/SOLIDWORKS Town/Extra Tank Parts/wave measure.SLDPRT
49.9 x 370.0 x 49.9 mm

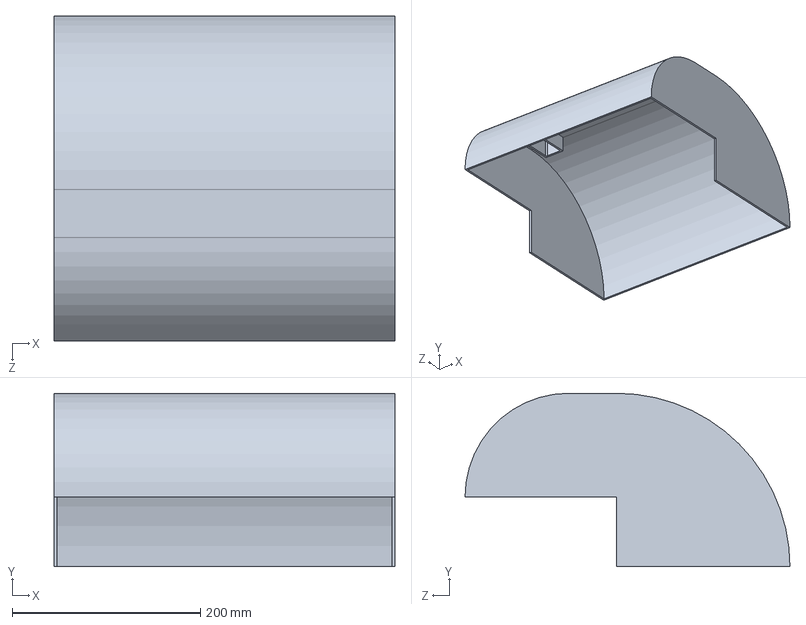
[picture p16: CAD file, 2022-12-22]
documentation/SOLIDWORKS Town/Hardware Hat.SLDPRT
362.0 x 184.2 x 345.0 mm

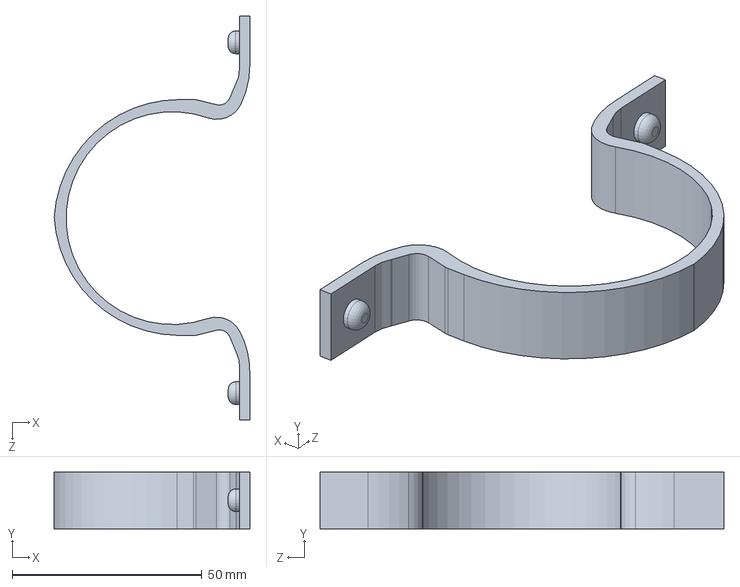
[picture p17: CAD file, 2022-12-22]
documentation/SOLIDWORKS Town/Wave Maker (all parts)/wave brace.SLDPRT
51.5 x 15.0 x 106.3 mm

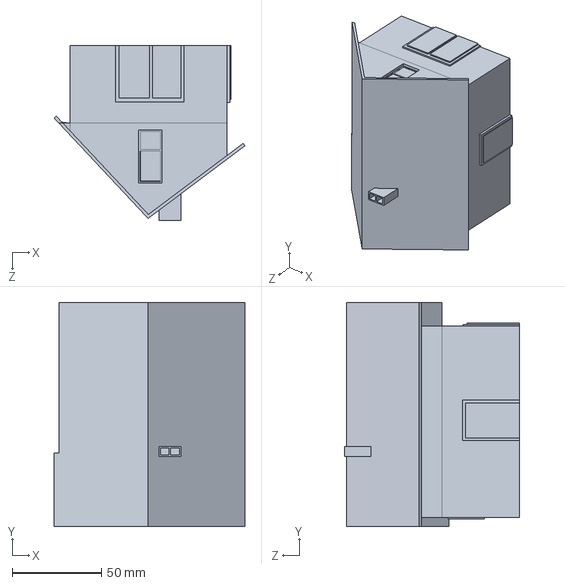
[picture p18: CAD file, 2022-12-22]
documentation/SOLIDWORKS Town/Buildings/blue house 2 - Copy.SLDPRT
106.9 x 125.4 x 97.9 mm

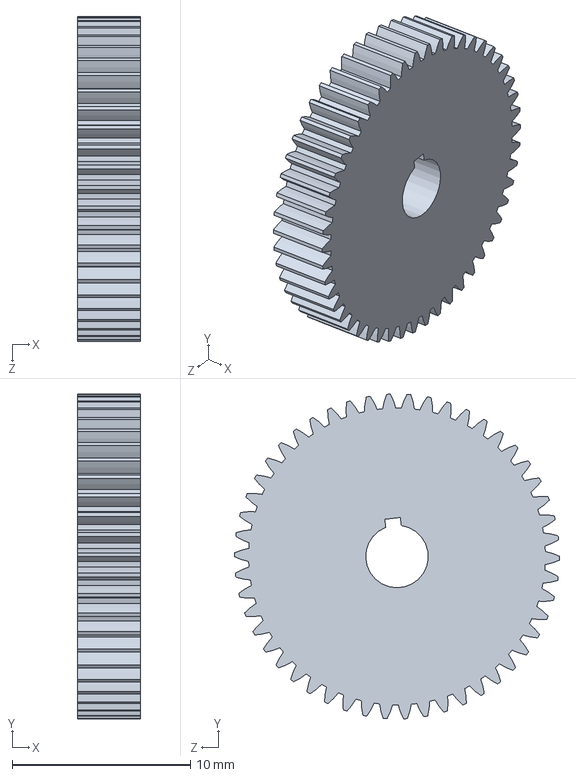
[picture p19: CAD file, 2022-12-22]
documentation/SOLIDWORKS Town/Buoy (all prts)/gear.SLDPRT
3.51 x 18.2 x 18.2 mm

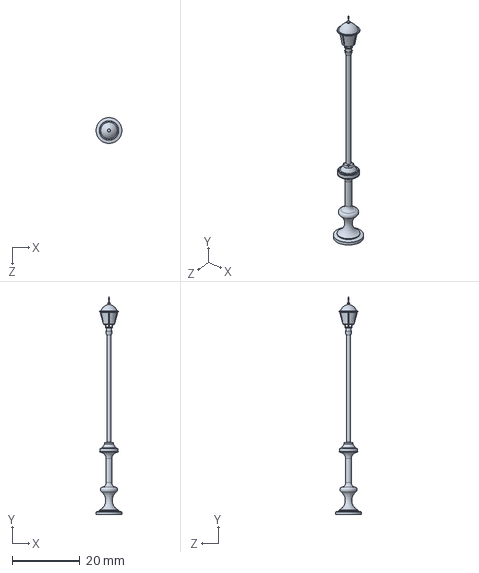
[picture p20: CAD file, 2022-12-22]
documentation/SOLIDWORKS Town/Extra Tank Parts/Street light.SLDPRT
7.68 x 64.2 x 7.68 mm

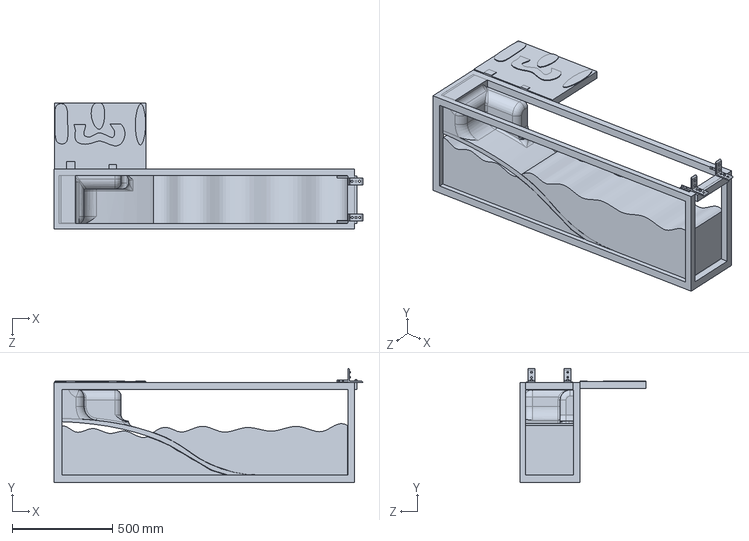
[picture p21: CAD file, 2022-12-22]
documentation/SOLIDWORKS Town/Town Base.SLDPRT
1542.4 x 570.0 x 630.3 mm

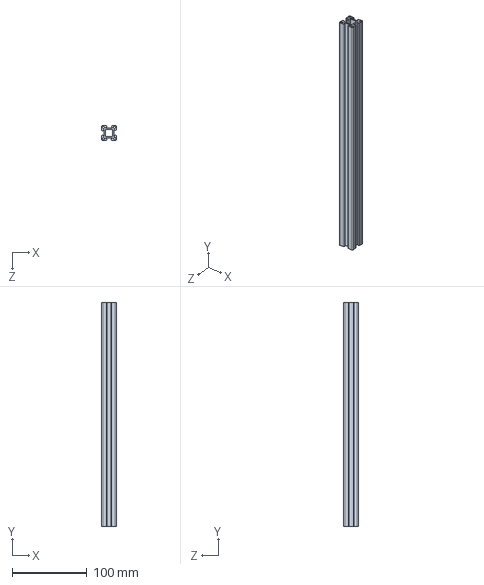
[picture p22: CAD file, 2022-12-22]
documentation/SOLIDWORKS Town/Wave Maker (all parts)/short Top Rods - .SLDPRT
20.1 x 300.0 x 20.1 mm

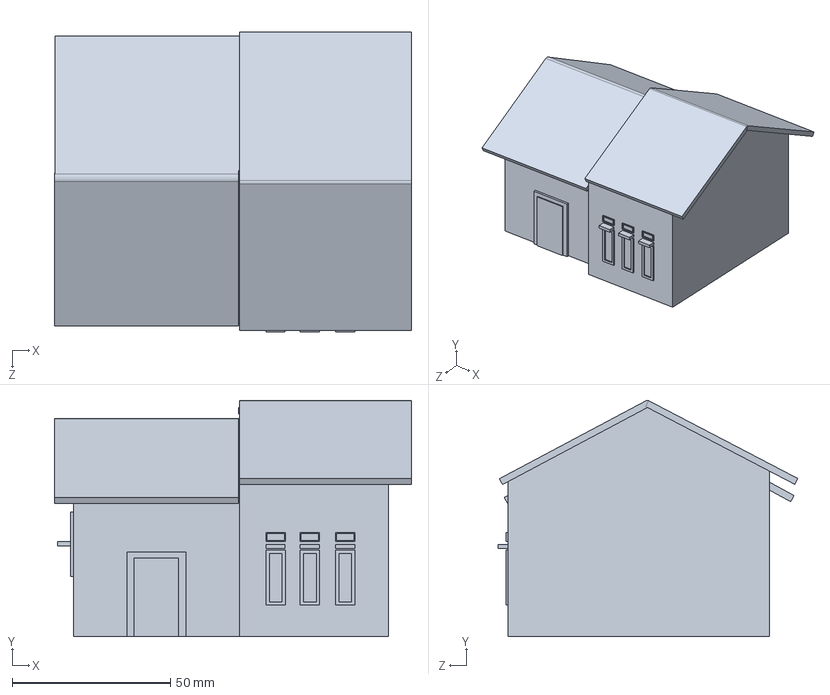
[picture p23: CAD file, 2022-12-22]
documentation/SOLIDWORKS Town/Buildings/LH house.SLDPRT
113.0 x 74.7 x 94.8 mm

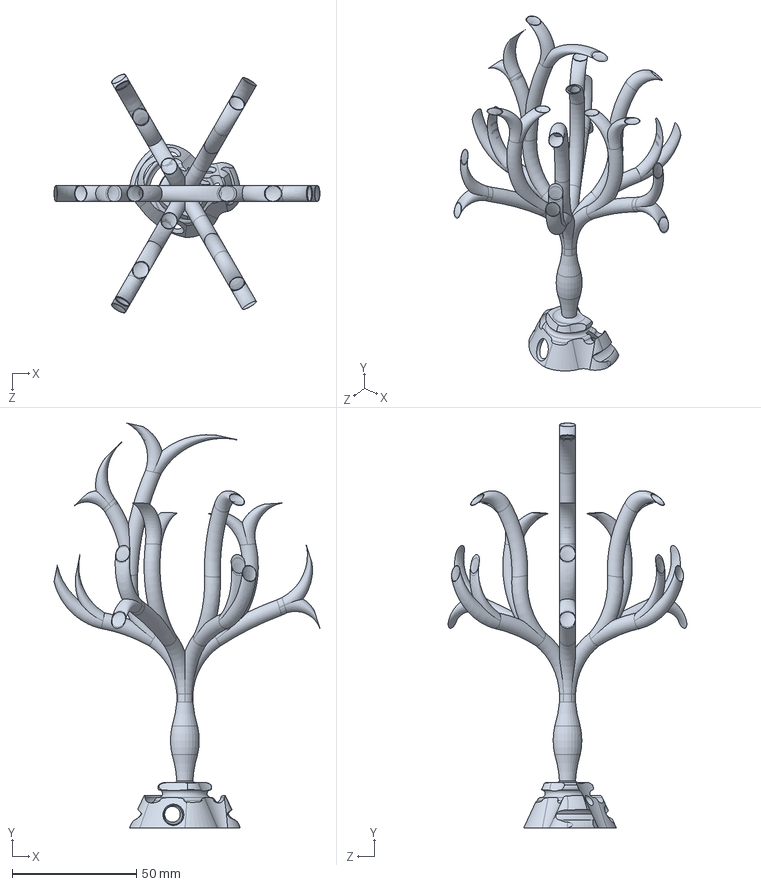
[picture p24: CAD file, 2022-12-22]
documentation/SOLIDWORKS Town/Extra Tank Parts/tubular-seaweed-kcasal.SLDPRT
107.2 x 163.3 x 96.3 mm

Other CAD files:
documentation/SOLIDWORKS Town/Wave Maker (all parts)/FinalWaveMaker.SLDPRT
documentation/SOLIDWORKS Town/Buoy (all prts)/Final buoy.SLDPRT
documentation/SOLIDWORKS Town/Buildings/Beginner House.SLDPRT
documentation/SOLIDWORKS Town/Buoy (all prts)/buoy.SLDPRT
documentation/SOLIDWORKS Town/Buildings/House.SLDPRT
documentation/SOLIDWORKS Town/Buildings/beach shack.SLDPRT
documentation/SOLIDWORKS Town/Buildings/light house.SLDPRT
documentation/SOLIDWORKS Town/Buoy (all prts)/Encoder.SLDPRT
documentation/SOLIDWORKS Town/Buoy (all prts)/Motor.SLDPRT
documentation/SOLIDWORKS Town/Buoy (all prts)/bracket.SLDPRT
documentation/SOLIDWORKS Town/Buoy (all prts)/old buoy - Copy.SLDPRT
documentation/SOLIDWORKS Town/Hardware Hat.STL
documentation/SOLIDWORKS Town/Wave Maker (all parts)/Horiz Rod.SLDPRT
documentation/SOLIDWORKS Town/Wave Maker (all parts)/Long screw.SLDPRT
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

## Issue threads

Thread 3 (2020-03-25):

Noise in Wave Probe Signal

nickross4444, 2020-03-25:
Can be reduced by configuring the Wave Probe to not use RS232 communications. Can also be improved with a filter in processing.

ryancoe, 2021-11-15:
@nickross4444 - did you complete this?

nickross4444, 2021-11-15:
We decided to switch from the analog read out to the digital one. The prototyped code was tested, but it has not been tested with the full system yet. Likely will be this Thursday.

nickross4444, 2021-11-24:
Tested. Required a moving average, but now looks good.

ryancoe, 2021-11-24:
@nickross4444 Could you post a plot of the improved signal?

nickross4444, 2021-11-26:
This is from #107
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
The yellow line is the improved signal. The moving average is one I threw together in java that averages the last 10 samples. The number of samples is variable.

ryancoe, 2021-11-28:
Ok, looks like we can deal with #107 separately.

10 samples at what sample rate?

nickross4444, 2021-11-28:
The wave probes have been configured to output at 30hz

Closed 2021-11-24.

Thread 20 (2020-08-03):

Random Phase generation

nickross4444, 2020-08-03:
The phase in the arduino Jonswap library is assigned with a defined seed for random number generation(123). This produces different results on the Due and on the Mega, likely because the different chip architecture(ARM vs Atmel).

nickross4444, 2021-05-18:
Since we are running two Due's this is not longer a concern.

Closed 2021-05-18.

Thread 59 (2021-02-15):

WEC motor torque constant

nickross4444, 2021-02-15:
- [x] Get model number from the motor
- [x] Add model # to diagram(#27)
- [x] Use maxon documented torque constant in arduino code
- [x] Verify torque constant with water tests

nickross4444, 2021-05-19:
We've determined the test should be redone with a few changes:

- larger buoy
- minimize static friction
- check for bowing in the rack
- measure resting point from the top and bottom
- try to find how much torque it takes to overcome the static friction at different positions(slowly ramp the command)

dforbush2, 2021-05-19:
Hi Nick

I agree on all points except the last. I actually think LARGER torque command steps will be needed, especially at the extremes of position to get decent motion. I think the ramps would be helpful in figuring out the size these torque steps need to be, but I prefer the series of static steps as a test procedure.

Here's a plot detailing the reasons as to why. Motor torque here is calculated from device motion as a change in the hydrostatic torque resulting from the displacement. Note the assymmetry and apparent hysteresis near larger displacements.

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

Best,
Dom

nickross4444, 2021-05-19:
@dforbush2  Thanks, noted

ryancoe, 2021-05-19:
Can you make a plot of motor torque vs. current (`plot(cur,tau)`)?

dforbush2, 2021-05-19:
Yes. It shows a decent but sort of rough trend, but the suggested Kt = 0.022, is quite far from the nominal. Maybe a units or missing a gear ratio?

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

ryancoe, 2021-05-20:
Thanks @dforbush2! I agree there is probably a gear ratio, looks like this has not been addressed in #27? Maybe @nickross4444 can look at this tomorrow?

nickross4444, 2021-05-25:
@gbacelli and I ended up doing the test with a sinusoid instead of steps, giving us these plots:
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
With a kt of 1.2085. The factory constant is 0.0078. I'm not sure what's going on here, maybe an incorrect unit conversion. This is the table I used:
[Torque Steps calculated.xlsx](https://github.com/SNL-WaterPower/siweed/files/6542686/Torque.Steps.calculated.xlsx)
On the bright side the static friction does look a lot better with the new larger buoy.

ryancoe, 2021-05-26:
Can someone post a photo of the WEC motor assembly?

nickross4444, 2021-05-26:
This is the test with the larger buoy:
[Torque constant test 5-21-21.zip](https://github.com/SNL-WaterPower/siweed/files/6549773/Torque.constant.test.5-21-21.zip)

ryancoe, 2021-06-02:
@nickross4444  - Can you plot up these latest results in the same style that @dforbush2 used?

nickross4444, 2021-06-02:
@ryancoe [The most recent graphs](https://github.com/SNL-WaterPower/siweed/issues/59#issuecomment-848311526) are those results.

ryancoe, 2021-06-02:
Right, duh. Sorry.

stespenc83, 2021-06-02:
> 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

This graph looks correct for the motor/gear combination. The torque is ~0.02Nm at 0.6A. The gear ratio for the 110321 gear that we purchased in this motor gear combo is ~4.4 (57/13). Combining this info together I get 7.6 mNm/A, which is very close to the 7.8 mNm/A on the motor data sheet.

> 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

I don't know what changed for this plot other than using a sinusoid instead of steps for the input, but the data is not even close to agreeing with the earlier data. Torque is more than an order of magnitude larger.

stespenc83, 2021-06-02:
> [Torque Steps calculated.xlsx](https://github.com/SNL-WaterPower/siweed/files/6542686/Torque.Steps.calculated.xlsx)

This formula in that Excel file could be the culprit for that latter plot being off.
Column E uses `=C2*PI()*(0.8^2)` to compute displaced volume in cubic meters. I don't think this buoy is 80cm in diameter.

stespenc83, 2021-06-03:
> > I also verified that the motor assembly is too short to include a gear set, the thinnest compatible planetary gearset I could find was still 15mm long, and the motor assembly is several mm shorter than its maximum length as specified on the dimensioned drawings.

I checked the motor dimensions as well. I measured the motor length to be 24mm, which is the data sheet value for the motor without an attached gear head. So unless the gear was removed between the first dataset shown here and now, the dataset, which I called good, is indeed off by a significant factor.

stespenc83, 2021-06-03:
> I don't think this buoy is 80cm in radius.

I should have measured the buoy while I was out at the RVR, but using a diameter of 5 inches, I get 7.6mNm/A as the torque constant for the second dataset. That diameter seems plausible, and the torque constant is very close to the datasheet value for the gearless motor. I'd say that using the wrong diameter is currently the biggest source of error.

nickross4444, 2021-06-03:
That's my mistake, the radius should have been 0.08. Here are the adjusted figures:
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
The torque constant now comes out to 0.0121
Here is the updated table with the corrected value:
[Torque Steps calculated.xlsx](https://github.com/SNL-WaterPower/siweed/files/6588448/Torque.Steps.calculated.xlsx)

@stespenc83 Thank you for taking a look at this. The primary difference between the first and second sets of test data was the size of the buoy. Though with other various changes that were made, I think we should focus mainly on the second set with the larger buoy.

ryancoe, 2021-06-04:
- [ ] Use calipers to measure buoy diameter
- [ ] Increase thermal time constant
- [ ] Increase max motor speed to 20,000
- [ ] Run tests with ~5s period and 20s period, confirm same results

nickross4444, 2021-06-17:
New tests done with the suggested changes and these files:
[new Tau tests.zip](https://github.com/SNL-WaterPower/siweed/files/6666438/new.Tau.tests.zip)

We measured buoy diameter at 120mm, and increased the thermal time constant from 0.9 to 1.2s. The max speed is about 13,000rpm, but at no point did we cross 500rpm

First test, 20s sine wave:
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
Torque constant: 0.0065 Nm/A

Second test, larger 20s sine wave:
Here you can see the thermal constant acting, so results may be less accurate.
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
Torque constant: 0.0069 Nm/A

 Third test, 5s sine wave:
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
Torque constant: 0.0069 Nm/A

We also verified the length matches the 283828 motor without a gearbox, which has a stated torque constant of 0.0078 Nm/A

We are finally in the right range, but a little less. This is to be partially expected due to friction. @gbacelli and @ryancoe is this ~14% error acceptable?

ryancoe, 2021-06-17:
Yes, this looks right!

stespenc83, 2021-06-17:
I think this is looking very good. There are still a few improvements that could be made.

The linear fits are being biased by the leverage points at the ends of the curves. This is the main way that friction is lowering the measured torque constant. If you were to remove any points past ~0.3A magnitude, the linear fits would have a higher slope. I did this, and got:

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
6.53 mNm/A ==> 7.57 mNm/A

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
6.90 mNm/A ==> 7.41 mNm/A

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
6.92 mNm/A ==> 7.57 mNm/A

Regarding my comment about friction: Since torque is being estimated from displacement and the frequency is low (inertial and viscous effects are small), the friction shows up as a "constant" offset from the ideal torque constant and doesn't affect the slope.

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
So here I show the difference between the actual and predicted torque (torque error) based on the two fits. With the original fit, there is a clear trend in the middle of the data with an upward slope. With the fit that removes the leverage points, the error is more flat (more easily seen on the bottom section). The average offsets are similar in magnitude (0.44 and 0.46 mNm) on either side of zero error, as expected. So the friction is ~0.45mNm.

With the new measured torque constant averaging 7.52 mNm/A, we're measuring within 4% of the datasheet value. Which I'd say is quite good. You can probably close this issue.

nickross4444, 2021-06-17:
@stespenc83, very nice, thank you, I will use 7.52 mNm/A as our constant.

ryancoe, 2021-06-25:
@nickross4444 - Please incorporate this material in the HardwareX paper. We should discuss/present

- Equation for torque constant
- How we infer the torque applied based on the vertical displacement of the WEC and hydrostatics (with equations)
- Work added by @stespenc83 to deal with the friction/hysteresis (with plots)

Closed 2021-07-21.

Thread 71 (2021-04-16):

Command verification

nickross4444, 2021-04-16:
Outgoing commands from the GUI(pressing buttons) are occasionally not received by the arduino's requiring a second press. It's infrequent enough that I think it can be classified as an optimization. I think taking the command verification methods from unit testing and applying them to the serial functions would fix the issue.

nickross4444, 2021-05-18:
With Dues running both systems, this no longer seems necessary.

Closed 2021-05-18.

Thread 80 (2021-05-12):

FFT activity

nickross4444, 2021-05-12:
When switching modes, the behavior of the FFT is not obvious to the user. This can be improved by making it draw grey when inactive, or the buffer resetting entirely on mode switches

Closed 2021-05-18.

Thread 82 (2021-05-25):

CSV data

nickross4444, 2021-05-25:
We've decided to leave csv logs in this github issue for storage. Attached are the first two sets.
[test logs.zip](https://github.com/SNL-WaterPower/siweed/files/6542033/test.logs.zip)

ryancoe, 2021-05-26:
@nickross4444 - this works well. I would suggest a minor tweak: post the data the pertains to a specific discussion (e.g., post the data for calculating the torque constant in #59).

Closed 2021-06-17.

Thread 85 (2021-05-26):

Update bill of materials and add to paper

ryancoe, 2021-05-26:
https://github.com/SNL-WaterPower/siweed/blob/919908d0400da31c2c2407996ca2bd9713debb87/documentation/siweedPaper.tex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

nickross4444, 2021-06-15:
It will need to be converted to a PDF and uploaded before uploading the paper, but the content is finished in a spreadsheet.

ryancoe, 2021-06-15:
May be helpful: https://ctan.org/tex-archive/support/excel2latex?lang=en

ryancoe, 2021-06-22:
@nickross4444 - per our discussion today, please break out the BOM so that we have totals for:

1. All parts except computer and tank
2. Computer and tank
3. 1+2

Please also add a sentence to the paper along the lines of _Note that a SIWEED system can be assembled with any tank on hand (e.g., a fish tank) and any MS Windows PC running; as these components can contribute significantly to system cost, the BOM shown in Table XX lists the tank and computer separately from the remainder of the components._

nickross4444, 2021-07-22:
- [ ] Add beach decorations to BOM, in a separate section.

nickross4444, 2021-08-04:
- [ ] Add V2 order to BOM
- [ ] Format nicely.

nickross4444, 2021-10-05:
@Anwi505, could you update the links in the BOM to model numbers?

ryancoe, 2022-11-07:
@nickross4444 - I've updated the [`BOM.csv`](https://github.com/SNL-WaterPower/siweed/blob/master/documentation/BOM.csv) with [c1e42da](https://github.com/SNL-WaterPower/siweed/commit/c1e42da1eddf0b0589be438d6f492c54434de541). Can you check that the "V2 order" has been incorporated per [your checkbox above](https://github.com/SNL-WaterPower/siweed/issues/85#issuecomment-892846999); after that we may want to make a separate issue about putting a link in the paper, as there will be a tricky order of operations things there (new branch, release, add link to BOM, make Zenodo tag).

Closed 2022-12-22.

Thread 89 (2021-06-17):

Basic mode for GUI

ryancoe, 2021-06-17:
From #88, we would like to consider adding a switch to the GUI which will change the layout of the GUI. The idea would be to reduce the number of user inputs from ~12 down to ~2 (e.g., wave height and wave period) so that an elementary school student would feel comfortable.

_(this is a long-term goal)_

nickross4444, 2021-06-17:
Finished earlier today

ryancoe, 2021-06-17:
fastest completion of an issue _ever_

nickross4444, 2021-06-17:
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

ryancoe, 2021-06-18:
very nice!

Closed 2021-06-17.

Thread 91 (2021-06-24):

use Project board to organize v2 work

ryancoe, 2021-06-24:
@nickross4444 - Please use the Project Board (https://github.com/SNL-WaterPower/siweed/projects/2) to organize issues that need to be completed for v2.

nickross4444, 2021-06-24:
Do we want to add a date milestone for this?

ryancoe, 2021-06-24:
Let's get the issues grouped first, then we can think about dates.

Closed 2022-11-02.

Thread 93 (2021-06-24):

Tank improvements

nickross4444, 2021-06-24:
Tank issues we'd like to address with Kevin:

- [ ] Shrouding IR sensor, currently done with a straw.
- [ ] Siphon or valve to empty tank
- [ ] Metal hardware rusting, maybe new beach altogether.
- [ ] Decal is not visible enough

ryancoe, 2021-11-15:
@nickross4444 @DeepFriedDerp - please mark if any of these are complete?

nickross4444, 2021-11-17:
Right only the siphon is done, and the IR shroud and rusting hardware are relatively high priority relative to the rest. @ryancoe ,is Kevin the right person to talk to for those two?

ryancoe, 2021-11-17:
Yes, Kevin is our guy for this. @DeepFriedDerp - Can you reach out and CC me?

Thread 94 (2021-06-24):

Wiring and Electronics organization

nickross4444, 2021-06-24:
Tasks we need to complete for V2
- [x] Order materials
- [x] Shroud external cables
- [x] Route through 2 connectors
- [x] Route connectors internally through a wiring bus
- [x] DIN rail or back-plate mount everything

Closed 2021-11-24.

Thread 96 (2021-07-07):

Doubt about the wave propagation mechanism of the Sandia Interactive Wave Energy Education Display (SIWEED) project

karenbrazil, 2021-07-07:
Good morning,
I'm Karen Soares, a student at the Federal University of Santa Catarina in Brazil, a Naval Engineering student and a member of the University's Laboratory of Acoustics and Vibrations.
We are currently working on a project to build a mini test tank for interaction with students during classes and researching the subject, I found the Sandia Interactive Wave Energy Education Display (SIWEED) project . And so i would like to know, if possible and relevant to you, what system did you use to cause the waves in the tank, ie, how did you perform this up and down movement, was a piston engine used? Could you provide me with this information or even the design of this system?

Thanks

ryancoe, 2021-07-07:
@karenbrazil - Thanks very much for your interest. We are working on a paper to give a more complete description of the system. In the meantime, you can reference the [system diagram](https://github.com/SNL-WaterPower/siweed/blob/d3d93abbe821c4af9602978c34950a012f8b12cc/documentation/diagrams/systemLayoutPNG.png) to see that we're using a stepper motor and ball-screw drive.

ryancoe, 2021-09-20:
@karenbrazil - I'll close this issue for now unless there's something more you need clarification on?

Closed 2021-09-20.

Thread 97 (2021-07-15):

Curriculum

nickross4444, 2021-07-15:
I could not find a simple way to make the curriculum documents diff trackable, so I've left them [here](https://github.com/SNL-WaterPower/siweed/tree/master/Curriculum) in docx and pptx form for now. If we really want to at some point, we can remake the documents in Latex. For now here is what needs to get done:

- [ ] Add to vocab list. @anwi505

ryancoe, 2021-07-16:
this works fine for now

ryancoe, 2021-07-20:
@Anwi505 - can you include some discussion about the scenarios in which a wave energy converter might be used? For example:

- Natural disaster
- Expensive alternatives (some  island communities rely diesel power)
- Others?

ryancoe, 2022-11-02:
With b7ec56930f4981199ebfbde88a69fa2f489e14ef, I moved this material into a single markdown document ([`educational_material.md`](https://github.com/SNL-WaterPower/siweed/blob/master/educational_material.md)) and distilled it a bit. Closing for now, although it would be great if this can be extended in the future.

Closed 2022-11-02.

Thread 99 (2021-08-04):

Design Files in Paper, Zenodo

nickross4444, 2021-08-04:
These are the instructions for design files in the paper:

The complete design files must be either uploaded to an approved online repository, uploaded at the
time of submission on the online Elsevier submission interface as supplementary materials [CAD
files, videos,. . . ], or included in the body of the manuscript [e.g. figures]. The two approved online
repositories are Mendeley Data and the Open Science Framework [OSF instructions]. Mendeley
data: https://data.mendeley.com/ Open Science Framework: https://osf.io/ Open Science Frame-
work HardwareX instructions: https://osf.io/wgk7q/wiki/home/

- CAD files. Authors are encouraged to use free and open source software packages for creating
the files. For CAD files, OpenSCAD, FreeCAD, or Blender are encouraged, but if not available
source files from proprietary CAD packages such as Autocad or Solidworks and other drawing
packages are acceptable. OpenSCAD:
- 3D printing. Supplementary files that facilitate the digital replication of the devices are en-
couraged. For example, STL files for 3-D printing components. We recommend uploading
CAD files to the NIH 3D Print Exchange as Custom Labware and providing a link to the
location. NIH 3D Print Exchange: http://3dprint.nih.gov/
- Electronics. PCB layouts and other electronics design files can be uploaded to the Open
Hardware Repository or other repositories. Open Hardware Repository: http://www.ohwr.org/
- Software and firmware. All software files used in the design and operation of the hardware
should be included in the repository. Provide a description of software and firmware and use
extensive comments in the code.

My thought is we include the following files:
-Arduino sketches
-Processing sketches
-Tank CAD model. @Anwi505 is going to try adding the Plunger and WEC hardware to the current model. We might also be able to upload pictures as design files, but I'm not sure about that.
-Plunger CAD model (maybe included in tank CAD model)
-MiniWEC buoy dimensions or CAD(maybe included in tank CAD model)
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

I found these dimensions for an old buoy, but I'm not sure what the new values would be. @ryancoe, do you have any guidance for this? (new values, and would a diagram like above be better or a CAD model?)

On another note the guidance states that "All designs must be submitted under an open hardware license." I believe we've done this for the sketches, but I don't think we have for any of the CAD models. @ryancoe, how should I move forward with this, and what do I list in the paper when it asks to fill in the license?

Current CAD model:
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

ryancoe, 2021-08-09:
A couple of thoughts/responses:

- Repository for uploading: this will be our Github repository, it already contains many of the required items (e.g., Arduino source, Processing source, etc.)
- CAD files
  - Plunger: just sent an email to @nickross4444 with an old archive that I think contains this
  - WEC: Please measure, but a I believe the current WEC has a major diameter of 16 cm:
[miniWaveTank.xlsx](https://github.com/SNL-WaterPower/siweed/files/6955253/miniWaveTank.xlsx), @nickross4444, can you work with @Anwi505 to get a CAD model made?
- License: we are already using a [GPL license](https://github.com/SNL-WaterPower/siweed/blob/master/COPYING) that I think will satisfy this requirement

Did I cover everything?

nickross4444, 2021-08-17:
@ryancoe

ryancoe, 2021-08-18:
Thanks for digging into this @nickross4444. Please take a look at this page about integrating Zenodo w. Github. I haven't done this before, but others in our group have (maybe @ssolson?). If I understand it correctly, this will create a [DOI](https://en.wikipedia.org/wiki/Digital_object_identifier
) pointing to specific commit in our repo.

https://guides.github.com/activities/citable-code/

nickross4444, 2021-09-23:
Mostly finished in 663d029da2039ec0f449b3e0388ad48e68e9e34b. Decided to reference "online repository" instead of linking to each file, as other HardwareX papers have done. Now just waiting for the CAD model.

As a note, the course of action for finalizing the link to the repo in the paper will be as follows:

- when files are ready, create a new branch and delete the paper and other unnecessary files from that branch.
- Create a release out of that clean branch and upload the release to Zenodo.
- Link to the Zenodo repo in the paper in Master.

ryancoe, 2021-11-15:
@nickross4444 - please give status update here

nickross4444, 2021-11-17:
Once issues #3, #85, #102 are complete, we can create the new branch that will get uploaded to Zenodo and finalize the paper from there.

ryancoe, 2022-11-02:
Minor detail, but I think the key step with Zenodo is to tag a release (https://docs.github.com/en/repositories/archiving-a-github-repository/referencing-and-citing-content), not make a specific branch. Are you looking at something different?

nickross4444, 2022-11-04:
As detailed [here](https://github.com/SNL-WaterPower/siweed/issues/99#issuecomment-926076653), we'll need to create a release branch first, not only for gitflow but also to get rid of the paper itself and any other redundant documents from the release.

nickross4444, 2022-12-23:
@ryancoe I've created the branch for the release and the release, but in order to get it on zenodo with git integration, whoever owns the repo needs to log into zenodo through their github account. I think you should be able to do it in a couple minutes, but I am unable to.

ryancoe, 2023-01-04:
Ok, I think I did it: https://zenodo.org/record/7502670. Please close this issue if you agree.

nickross4444, 2023-01-24:
@ryancoe I think it's missing the CAD files and the educational material. Besides that good to go.

ryancoe, 2023-02-14:
This had me scratching my head for a bit, but the files _**are**_ actually there. The Zenodo website preview does not include all files.

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

When I download the `.zip` file from Zenodo, I do indeed see the CAD files.

<details>
  <summary>File listing</summary>

```
total 64
drwxrwxr-x@ 5 rcoe  SANDIA\Domain Users   160B Dec 22 16:40 Arduino
-rw-rw-r--@ 1 rcoe  SANDIA\Domain Users   3.1K Dec 22 16:40 CODE_OF_CONDUCT.md
-rw-rw-r--@ 1 rcoe  SANDIA\Domain Users    34K Dec 22 16:40 COPYING
drwxrwxr-x@ 4 rcoe  SANDIA\Domain Users   128B Dec 22 16:40 Processing
-rw-rw-r--@ 1 rcoe  SANDIA\Domain Users   5.6K Dec 22 16:40 README.md
-rw-rw-r--@ 1 rcoe  SANDIA\Domain Users   1.5K Dec 22 16:40 contributing.md
drwxrwxr-x@ 6 rcoe  SANDIA\Domain Users   192B Dec 22 16:40 documentation
-rw-rw-r--@ 1 rcoe  SANDIA\Domain Users   8.5K Dec 22 16:40 educational_material.md

./Arduino:
total 0
drwxrwxr-x@ 5 rcoe  SANDIA\Domain Users   160B Dec 22 16:40 WEC_Controller
drwxrwxr-x@ 5 rcoe  SANDIA\Domain Users   160B Dec 22 16:40 WaveMaker_Controller
drwxrwxr-x@ 7 rcoe  SANDIA\Domain Users   224B Dec 22 16:40 libraries

./Arduino/WEC_Controller:
total 20
-rw-rw-r--@ 1 rcoe  SANDIA\Domain Users   3.5K Dec 22 16:40 Interrupts.ino
-rw-rw-r--@ 1 rcoe  SANDIA\Domain Users   2.2K Dec 22 16:40 Serial.ino
-rw-rw-r--@ 1 rcoe  SANDIA\Domain Users   8.0K Dec 22 16:40 WEC_Controller.ino

./Arduino/WaveMaker_Controller:
total 20
-rw-rw-r--@ 1 rcoe  SANDIA\Domain Users   4.8K Dec 22 16:40 Interrupts.ino
-rw-rw-r--@ 1 rcoe  SANDIA\Domain Users   2.3K Dec 22 16:40 Serial.ino
-rw-rw-r--@ 1 rcoe  SANDIA\Domain Users   7.8K Dec 22 16:40 WaveMaker_Controller.ino

./Arduino/libraries:
total 4
drwxrwxr-x@ 12 rcoe  SANDIA\Domain Users   384B Dec 22 16:40 DueTimer
drwxrwxr-x@  5 rcoe  SANDIA\Domain Users   160B Dec 22 16:40 Jonswap
drwxrwxr-x@ 13 rcoe  SANDIA\Domain Users   416B Dec 22 16:40 MD_AD9833
drwxrwxr-x@ 10 rcoe  SANDIA\Domain Users   320B Dec 22 16:40 SuperDroidEncoderBuffer
-rw-rw-r--@  1 rcoe  SANDIA\Domain Users    87B Dec 22 16:40 readme.txt

./Arduino/libraries/DueTimer:
total 40
-rw-rw-r--@ 1 rcoe  SANDIA\Domain Users   7.0K Dec 22 16:40 DueTimer.cpp
-rw-rw-r--@ 1 rcoe  SANDIA\Domain Users   2.5K Dec 22 16:40 DueTimer.h
-rw-rw-r--@ 1 rcoe  SANDIA\Domain Users   1.1K Dec 22 16:40 LICENSE.txt
-rw-rw-r--@ 1 rcoe  SANDIA\Domain Users   3.5K Dec 22 16:40 README.md
-rw-rw-r--@ 1 rcoe  SANDIA\Domain Users   5.2K Dec 22 16:40 TimerCounter.md
drwxrwxr-x@ 5 rcoe  SANDIA\Domain Users   160B Dec 22 16:40 examples
-rw-rw-r--@ 1 rcoe  SANDIA\Domain Users   324B Dec 22 16:40 keywords.txt
-rw-rw-r--@ 1 rcoe  SANDIA\Domain Users   294B Dec 22 16:40 library.json
-rw-rw-r--@ 1 rcoe  SANDIA\Domain Users   391B Dec 22 16:40 library.properties

./Arduino/libraries/DueTimer/examples:
total 0
drwxrwxr-x@ 3 rcoe  SANDIA\Domain Users    96B Dec 22 16:40 AvaliableTimer
drwxrwxr-x@ 3 rcoe  SANDIA\Domain Users    96B Dec 22 16:40 MultipleTimers
drwxrwxr-x@ 3 rcoe  SANDIA\Domain Users    96B Dec 22 16:40 SimpleTimer

./Arduino/libraries/DueTimer/examples/AvaliableTimer:
total 4
-rw-rw-r--@ 1 rcoe  SANDIA\Domain Users   1.5K Dec 22 16:40 AvaliableTimer.pde

./Arduino/libraries/DueTimer/examples/MultipleTimers:
total 4
-rw-rw-r--@ 1 rcoe  SANDIA\Domain Users   523B Dec 22 16:40 MultipleTimers.pde

./Arduino/libraries/DueTimer/examples/SimpleTimer:
total 4
-rw-rw-r--@ 1 rcoe  SANDIA\Domain Users   342B Dec 22 16:40 SimpleTimer.pde

./Arduino/libraries/Jonswap:
total 8
drwxrwxr-x@ 3 rcoe  SANDIA\Domain Users    96B Dec 22 16:40 examples
-rw-rw-r--@ 1 rcoe  SANDIA\Domain Users   3.3K Dec 22 16:40 miniWaveTankJonswap.cpp
-rw-rw-r--@ 1 rcoe  SANDIA\Domain Users   931B Dec 22 16:40 miniWaveTankJonswap.h

./Arduino/libraries/Jonswap/examples:
total 0
drwxrwxr-x@ 3 rcoe  SANDIA\Domain Users    96B Dec 22 16:40 jonswap_example

./Arduino/libraries/Jonswap/examples/jonswap_example:
total 4
-rw-rw-r--@ 1 rcoe  SANDIA\Domain Users   1.2K Dec 22 16:40 jonswap_example.ino

./Arduino/libraries/MD_AD9833:
total 160
-rw-rw-r--@  1 rcoe  SANDIA\Domain Users   111K Dec 22 16:40 Doxyfile.dox
-rw-rw-r--@  1 rcoe  SANDIA\Domain Users   765B Dec 22 16:40 ISSUE_TEMPLATE.md
-rw-rw-r--@  1 rcoe  SANDIA\Domain Users    26K Dec 22 16:40 LICENSE
-rw-rw-r--@  1 rcoe  SANDIA\Domain Users   1.4K Dec 22 16:40 PULL_REQUEST.md
-rw-rw-r--@  1 rcoe  SANDIA\Domain Users   800B Dec 22 16:40 README.md
drwxrwxr-x@ 76 rcoe  SANDIA\Domain Users   2.4K Dec 22 16:40 docs
drwxrwxr-x@  5 rcoe  SANDIA\Domain Users   160B Dec 22 16:40 examples
-rw-rw-r--@  1 rcoe  SANDIA\Domain Users   866B Dec 22 16:40 keywords.txt
-rw-rw-r--@  1 rcoe  SANDIA\Domain Users   450B Dec 22 16:40 library.properties
drwxrwxr-x@  3 rcoe  SANDIA\Domain Users    96B Dec 22 16:40 media
drwxrwxr-x@  5 rcoe  SANDIA\Domain Users   160B Dec 22 16:40 src
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

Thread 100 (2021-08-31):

add second wave probe

ryancoe, 2021-08-31:

nickross4444, 2021-11-17:
The second wave probe is wired into the hardware and data is read into the log files, but it is not displayed in the GUI. This should work fine for characterization.

ryancoe, 2021-11-17:
Great!

Closed 2021-11-17.

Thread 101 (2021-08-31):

wave maker tuning

ryancoe, 2021-08-31:
After completing #3 and #100...

1. Run a test matrix of regular waves with a range of frequencies and amplitudes (e.g., f = [1, 1.5, 2, 2.5, 3, 3.5, 4]Hz, A = [5, 10, 20, 30, 40]mm)
2. Compare amplitude measured by wave probes against the desire amplitude
3. Present results here (we'll decide a course of action at that point)

We will present this work in Section 7 of the HardwareX paper.

ryancoe, 2022-11-02:
Note that we had originally conceptualized this issues a wave maker **_tuning_** activity. We will limit this issue to a first step of **_characterization_** and leave **_tuning_** to a separate issue.

nickross4444, 2023-02-18:
I'm not 100% sure this is worth tackling. Not only did we observe significant capacitive coupling when touching the probes, but the data looks really noisy inconsistent to me:
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
(position determined by encoder)
plotted with:
[wavemakercharacterize.txt](https://github.com/SNL-WaterPower/siweed/files/10772765/wavemakercharacterize.txt)

ryancoe, 2023-02-20:
You may be right @nickross4444. Could you upload a zip of the data for me to look at?

nickross4444, 2023-03-16:
Data used for the previous plots:
[P steps.csv](https://github.com/SNL-WaterPower/siweed/files/10995433/P.steps.csv)
[D steps.csv](https://github.com/SNL-WaterPower/siweed/files/10995435/D.steps.csv)

nickross4444, 2023-03-16:
Sorry about that, they should be correct now.

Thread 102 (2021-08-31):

verify and show demonstration of WEC feedback controller

ryancoe, 2021-08-31:
Compare the applied torque (or current) with the product of the controller gains, position, and velocity; check that

`tau = kp*pos + kd*vel `

@nickross4444 and Anwi collected data for this previously

The results will be included in Section 7 of the paper

ryancoe, 2021-09-23:
Time history plot with three axis:

1. position
2. velocity
3. torque

Explain in text that the torque follows `tau = kp*pos + kd*vel`

nickross4444, 2021-11-10:
These are the resulting plots: The error is calculated based on the reported amperage from the motor controller, and the expected amperage based on position and velocity read from the encoder. The high error in the high P range is not concerning, since the P gain may just be too high, but the rest is. I am currently looking at seeing if filtering the data properly clarifies the issue.
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

ryancoe, 2021-11-11:
@nickross4444 - Thanks for posting. Could you put the data and plotting code up in this issue as well?

nickross4444, 2021-11-17:
Most recent files:
[PDverification.zip](https://github.com/SNL-WaterPower/siweed/files/7550863/PDverification.zip)

ryancoe, 2021-11-18:
@dforbush2 @gbacelli - Could you take a look at this and advise @DeepFriedDerp @nickross4444 how to proceed?

dforbush2, 2021-11-24:
Last update I heard is that filtering did not solve the problem: I was wondering if the jump in current set-point at the gain switches was biasing the error plot high since the instantaneous error at that point would be high since there was no time for the electrical dynamics to catch up. That doesn't look to be the problem anymore. I will take a look in detail tomorrow, but generally poor torque tracking suggests that the internal torque control loop in the motor drive is not working well. Not sure if this is something you are tuning or if the parameters the drive is set up to use are just poor.

ryancoe, 2021-11-24:
May also be good to recall the findings from the motor torque constant efforts (#59)

https://github.com/SNL-WaterPower/siweed/issues/59#issuecomment-863504663

dforbush2, 2021-11-30:
Did a deeper dive today and some observations:
* % error dimensions as presented didn't quite line up right: its actually a lot worse than as displayed, but read on
* I wasn't clear about how to implement that filter (sorry @nickross4444), so there was some phase-shift introduced that actually made the error worse in some cases. I used filtfilt() instead, but this doesn't help much: there are only about 10 samples per period (see point of concern, below) so there isn't a lot of resolution to filter within.
*Some of the largest torque-error peaks occur right when the gain changes, amounting to an instantaneous change in command torque for which we would expect a large error, as suggested previously. But this does not explain all peaks or even the largest of them. A bigger reason is that some of the desired torque values are very close to zero. So when you take the percent error, even if you are off by a functionally tiny amount (i.e., within sensor noise), it shows up as a large percent error. I recommend using another statistical error measure: the "right" answer is up for debate.

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

Here is a plot of absolute error compared to an estimate of sensor noise, when the command torque is zero.
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

Note that the weaker, but still present, trend in absolute error near zero, is probably related to the issue @ryancoe noted because for the cases where Kp = 0 and Kd~=0, when the command torque is near zero (i.e., velocity = 0), due to static friction, the measured torque may not be. This explains why the error looks worse for these cases, as well: when Kp~=0 and Kd=0 the zeros of command torque do not align with the zeros of velocity.

As seen in the plot here, though, this doesn't totally account for it: there are also larger errors associated with velocity maxima when Kp gains are non-zero. These seem more related to a phase-lag issue in the controller, as the change in command will be especially large due to the high velocity in these cases. These errors correspond to the highest-amplitude torque commands in this data set.

All in all, I am not hugely alarmed by the torque tracking of the drive considering the high impact of friction on the measured torque value. But it can be improved: in particular there is a noticeable lag (~15 deg) in the larger amplitude torque commands. Do we have a way to adjust the internal torque tracking loop of the motor drive?

One point of concern:
*  Before the controller even moves off of zero gain, the logged time stamp interval basically doubles: does this imply that the control loops in question have had their sample times halved? In the pic, the bottom data tip is the last time the control gains are both zero.
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

dforbush2, 2021-12-02:
Notes from a discussion:
* the bottom plot is just the GUI time-stamp: this does not affect the torque control loop which runs at a very nearly constant rate (~100 Hz).
* the arduino read of sensor values are read synchronously: they are read at the same instant. Although the reported time stamps may not be the actual instant they were read, both the command torque and sensor torque will be from the same instant.

In short, both of my leading theories above are not the actual problem.

TO-DO @dforbush2 :
* parse the absolute error plot for points we can "explain" the error removing: points below noise floor, those occurring in the moments after a step change in gain setting, and those that are potentially out-of-range of the motor torque. Hopefully, any remaining trend will be more illuminating.

TO-DO @nickross4444
* on the hardware: try and get as consistent and fast a sample time in the logged values (slight prioritization of consistency over speed) and then perform the following tests:
1). Zero --> step change to positive torque --> zero, to reset --> step change to negative torque. Repeat, changing amplitudes each time. Try to get ~6 different amplitudes, the largest of which exceeds torque limit.
2). Zero --> step change to positive torque --> step change to negative torque --> zero. Repeat, changing amplitude of step size. Repeat again changing step order (i.e., negative to positive).
3). Zero --> ramp torque over ~15 s to a large, but below limit value --> zero. Repeat with oppositely signed torque.

Hopefully this will give us some more information! Leading hypothesis now based on data we have seen: the motor torque slew rate is too slow to provide good tracking for the larger amplitude oscillations. Whether that is a hardware limit or something that is a dynamic introduced by its controller remains to be seen.

nickross4444, 2021-12-03:
Here are the test results. I believe test 3 ended up exceeding the torque saturation limit, but this can at least help us characterize exactly where that is.
[Open loop data.zip](https://github.com/SNL-WaterPower/siweed/files/7646017/Open.loop.data.zip)

ryancoe, 2021-12-07:
Can we look at a plot of commanded torque vs. actual torque? Should look something like this. @stespenc83 did something similar in #59.

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

dforbush2, 2021-12-09:
Hi all,

[readTestData.txt](https://github.com/SNL-WaterPower/siweed/files/7681805/readTestData.txt)
Please see the attached script to run this processing. I wish I knew more of what to make of it...but there is some weirdness. I'll spare attaching a ton of figures to requesting that the attached script is run and plots made. Change the extension to *m and extract the files from earlier.

Some observations:
* The effect of static friction is evident in all of the step tests.
* The sustainable torque limit is 3.5e-3 N-m. The higher the torque over this limit, the lower the time it can be maintained.
* There's some assymmetry in the static friction. The alternating steps shows this most significantly at the largest steps.
* In the ramps, one can see that there is consistently about a 2 to 3 sample delay in torque measured matching torque command. This aligns with the sine wave tracking ability in the samples noted above.
* The diff(sample) is now much more consistent, at about 32.
* The tracking error doesn't seem to be a function of step size, but tends to increase with larger torque ramp rates.

To my eye: if we have the ability to adjust the internal torque tracking loop, these, in combination, suggest that we should increase the integral gain of this control loop.
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
ryancoe, 2021-12-21:
1. Plot with four axes: position, velocity, gains, torque (both commanded and actual)
2. Characterize noise by statistical analysis of zero-command torque data:
   - Plot a histogram
   - Find the mean (hopefully zero) and standard deviation
3. Autocorrelation to find delay (should be the same two samples that you've found), see, e.g., https://www.mathworks.com/help/signal/ug/cross-correlation-of-delayed-signal-in-noise.html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

nickross4444, 2022-11-05:
1. Finished in previous comments
2. It seems the mean of the noise is not zero:
Commanded torque is read through an analog output if I remember correctly. My best guess is there's a small DC offset in the generation or reading of the analog signal. This could potentially be calibrated for.
These are histograms of the commanded torque when the command should be 0(either by pwm commanding the duty cycle that corresponds to 0 torque, or by the enable pin being low[both data sets individually show similar results]):
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
The means are 2.3676e-05 and 2.0934e-05, and the standard deviations are 1.6564e-05, 1.7211e-05, respectively. Units are meters.

These were found with this  script:
[pdverification.txt](https://github.com/SNL-WaterPower/siweed/files/9942471/pdverification.txt)

3. The methods of cross correlation, finddelay(), and the method previously described in this issue all agree that the data set of steps and ramps has a 2-3 sample delay, and that the kp steps and kd steps data sets have no sample delay. I think it will be best to check the sample delay on the larger data set we will have access to next week, from the demo. I have a very loose theory that the delay was caused by a checksum issue that was fixed.

ryancoe, 2022-11-05:
>...The means are 2.3676e-05 and 2.0934e-05, and the standard deviations are 1.6564e-05, 1.7211e-05, respectively. Units are meters.

Shouldn't the units for the `x` axes of those histograms be `Nm` (we command `tau=0` and then look at the actual value of `tau`)? Once we get straight on that, let's find a way to put those numbers in context relative to some nominal torque value (i.e., 2e-5 is very small, but it really depends on what our typical torque levels are -- maybe compare to max torque or RMS torque from a typical test).

> ...I think it will be best to check the sample delay on the larger data set we will have access to next week, from the demo. I have a very loose theory that the delay was caused by a checksum issue that was fixed.

Sounds good

nickross4444, 2022-12-16:
You're totally right, the units should be Nm. Good news is my theory was right, newer data sets show no measurable delay, so our max loop delay is at most 1/sampling frequency = ~3ms(probably much better than that in most cases). Our typical torque levels are on the order of xe-4. Here is a similar histogram of an entire test, not just the zero commands:
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
Max torque in this case was almost 9e-4.
RMS torque was 3.1716e-04
This is a histogram of the same sample set, but filtered to only be zero commands:
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

ryancoe, 2023-01-04:
Looks great! Can you add this to the paper and then close the issue?

Closed 2023-03-20.

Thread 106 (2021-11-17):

Display 2nd wave probe in GUI

ryancoe, 2021-11-17:
With #100 complete, we can consider adding the 2nd wave probe's measurements to the GUI

nickross4444, 2021-11-19:
- [ ] Add moving average filters on both probe signals.

ryancoe, 2022-11-04:
we're not really sure if this adds value given the coupling issues (see #107)

Closed 2022-11-04.

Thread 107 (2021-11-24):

Wave Probe Drift

nickross4444, 2021-11-24:
As the wave amplitude rises past a certain point, the wave probe readings drift upwards:
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
Stopping the wave maker results in the wave probe reading coming back down to normal.

Reason is unknown, but one theory is that surface tension is keeping some water on the wave probe rod. This does not explain why the maximum height would rise

ryancoe, 2021-11-24:
Any chance this has to do with the moving average or some other processing you added related to #3?

nickross4444, 2021-11-24:
I don't think so, we saw the same thing before there was any processing at all.

dforbush2, 2021-11-29:
This sounds like a hardware issue or maybe some initial processing... not sure I will be much help there. One probably naive suggestion: is it possible this is related to some sort of buffer overflow? If it consistently happens at about the same time this could be the case, especially if the data type at this stage is still some kind of INT.

On the data processing side, you may be able to use a high-pass filter to get rid of the mean shift in close to real-time. Probably worth figuring out what is doing this though. It looks like it is an honest mean shift rather than a consistent trend (e.g., like a linear increase), so one quick and dirty work-around, provided this shift happens early enough in a run, would be to wait until the shift happens, detrend by the new mean, and then start whatever the test is.

nickross4444, 2021-12-03:
After some more experimentation today, this seems to be an issue on both wave probes, though they do behave slightly differently. They also may be too close together, as touching one staff changes the height value read by both staffs. As a patch for the drift issue, I've added a moving average in 10b9ed726069c0076537242dc35b8bd196e6c560 with a larger sample count that and subtracted it from the other moving average. This has the effect of keeping the data near the origin, though can definitely be optimized, and should maybe be fixed an entirely different way.

ryancoe, 2021-12-06:
Please engage with @gbacelli on two items:

1. Locations of probes causing electrical interference?
2. Design a bandpass filter instead of the ad-hoc moving averages

DeepFriedDerp, 2021-12-14:
Hi Everyone,

I have taken both the generic continuous low-pass and high-pass filters in the laplace domain and converted them into their discrete, time-domain forms. I then coded up a set of functions in matlab that will provide the framework for @nickross4444 to implement them in Java as a bandpass filter. Hopefully this will help with high frequency noise and the near-DC bias issues we are currently experiencing.

For the cross-talk between probes, I called the manufacturer and confirmed that the probes measure the time constant of an RC circuit formed by one "plate" (a conductive coating on the inside of the wave staff), the dielectric layer (the polymer or plastic material making up the outside surface of the wave staff), and the 2nd "plate" (the contact surface of the water and the outside surface of the wave staff).

This means that we have the following effective circuit formed by the two wave probes and a common ground in water:
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

Where: R1 thru R3 are the resistive paths between each wave probe and from each wave probe to ground, and V1 & V2 are the AC signals being used by the wave probe to determine the time constant of the RC circuit. As you can see here, a change in one capacitor's capacitance will effect the RC time constant of the whole circuit, and thus the reading of the other probe (i.e. a change in water level on probe one will effect the perceived water level on probe 2).

If the conductivity of the fluid is increased (by adding salt or some other ionic solute), then the values of R1 thru R3 are driven towards 0, and the effective circuit will resemble (though not completely look like) the following:
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
Which would help to reduce the coupling effect between the wave probes. Additionally, the manufacturer actually doesn't recommend this type of capacitive wave staff for freshwater, as any sort of biological growth or wetting agent in the water (we currently have algae or some sort of alien lifeform growing on every elastomer or plastic surface below the water line) will cause the water to cling to the wave probe surface when the water level drops, which can cause a bias and/or clipping of the troughs when a sinusoidal wave is measured.

The addition of salt would prevent a good amount of microbial growth (combined with the band-pass filtering) may help the biasing problems we are seeing and improve the cross-talk situation between the two wave probes. The only downside to this is that we'll need to source the salt, and we'll need to either paint or otherwise coat the metallic surfaces below the water line, or have Kevin rebuild some of the wetted hardware out of aluminum (including fasteners) to prevent corrosion, which will significantly accelerate once salt is added.

@ryancoe @gbacelli @dforbush2 Does this sound reasonable? Please feel free to point out any issues you see with this explanation or the proposed solutions (other than my grammar, I know its pretty terrible) :)

Thanks!

dforbush2, 2021-12-15:
If we ever intend to leave the system filled for any length of time I would stay away from salt. It will take more than aluminum fasteners to solve the corrosion problem, since any interface of dissimilar metals submerged in an electrolyte with corrode based purely on the differing voltage potentials. If we are just an hour or two at a time and we wash things down with freshwater after every use, this is probably fine.  And 80/20 painting is a lot of work.

But to this end of using a chemical solution to prevent microbial growth, why not a small amount of bleach instead? This will very gradually corrode the aluminum but if it is sufficiently diluted this is probably slow enough to not be a concern. Honestly not sure which is worse, bleach or salt, on aluminum at the concentrations we would need it to prevent growth but this is probably an answerable question.

By chance did you use the 'c2d' function when building these filters? If so you may be careful to check the phase response of the developed filters. The default method of this function doesn't always do a great job of preserving phase response. I think I have had better luck with the 'Tustin' option?

DeepFriedDerp, 2021-12-15:
@dforbush2

**On the corrosion concern:**
Nick and I share this concern, and I am familiar with galvanic corrosion and how quickly it can happen, even in slightly conductive water (its currently happening on all of the non-aluminum fasteners below the water line). The trade-off is that simply adding an antimicrobial like bleach does not solve the problem of the coupled wave probes, and bleach rapidly degrades in light to a mixture of salt and sodium chlorate (which is toxic, but only to organisms with hemoglobin, so it wouldn't inhibit microbial growth). Additionally, the manufacturer warned that many antimicrobial water additive can act as a wetting agent, which will cause the same problem as the microbes in the water.
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
nickross4444, 2022-03-15:
I defined the functions under the assumption this would give us what we needed: sin (2pi * hz/fs)

which looks like this:(for 0.05hz)
```
for (int i = 0; i < 300; i++)
    signal.add(sin(2PI * i * 0.05 /30));
```
Let me know if this doesn't look right.

My thoughts with the lines you are referring to:

1. On the first iteration all variables(wm1 wm2 xm1 xm2) are set to zero, since no history exists.
2. On the second iteration, kk is on the second index, and xm1 and wm1 should be set to the first index
3. On the third iteration(and others, but in our case there is no 4th), wm1 and xm1 are the second sample, and and xm2 and wm2 the first sample.

I changed the indexing to be done relative to the buffersize(3) instead of the incrementing index(kk), which is why it looks a little strange.

@dforbush2 thoughts on the sampling frequency?

nickross4444, 2022-03-15:
Yes, your description sounds correct, and is reflected in the java filter. I cut the iterations down to 3 as an optimization attempt since we need to run it in realtime. I realize now that since this is a second order filter, it's not so simple. From what I can now tell, each filtered sample is dependent on the 5 most recent samples, and so the inner loop could iterate 5 times over the most recent samples, and the 5th index of yOut could be taken as the output. With this adjustment things look a lot better:

NOTE:
the 4th x-axis was in the wrong place in the last example, sorry about that.

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

It now looks a bit better, but I'm not sure why in test 4, the DC offset is only partially corrected. I've pushed the changes to the code here: https://github.com/SNL-WaterPower/siweed/blob/19f9feb7315b4d1118a27eb6284a00a1ef7cf523/Processing/filter_test/filter_test.pde

@dforbush2 what do you think?

nickross4444, 2022-03-15:
Yes, your description sounds correct, and is reflected in the java filter. I cut the iterations down to 3 as an optimization attempt since we need to run it in realtime. I realize now that since this is a second order filter, it's not so simple. From what I can now tell, each filtered sample is dependent on the 5 most recent samples, and so the inner loop could iterate 5 times over the most recent samples, and the 5th index of yOut could be taken as the output.

This makes sense to me, however changing the buffer size to the full signal proves me wrong:
NOTE:
the 4th x-axis was in the wrong place in the last example, sorry about that.

Buffer size 500(full signal):
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
Buffer size 5:
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

With the full buffer, it works properly, which thoroughly confuses me. Additionally, it doesn't make sense for us to use the whole signal in realtime, so how much should we use?

@dforbush2 what do you think?

nickross4444, 2022-03-17:
We were able to find the issues, mainly that zeros were being introduced in more than just the beginning and yOut was being calculated too many times. We were able to get it working, and without any for loops, so it's a linear function now, which is great news for performance. Only change I think needs to be done now is recalculating the coefficients so that the upper cut off frequency is 3hz. More noise was still getting through than desired. I can probably handle this, but @dforbush2 I'll ask for help if I need it.

dforbush2, 2022-03-21:
Great job! The reason for the "For" loop in the MATLAB script was to simulate "sampling" the time-series to populate the buffers needed for the operations. In reality with data streaming in, one just needs to run the operations on the populated buffer, but getting that right is always the rub in translating these implementations.

I am happy to handle the recalculation of the cut off frequencies, but if you wanted to step through the Filter Design and Analysis tool work-flow in MATLAB (outlined above) it should be relatively straight forward. Alternatively, the order of the filter could be increased at present cut-off frequencies to attenuate the stop-bands more quickly (at the cost of more phase-shift on the ends of the pass-band).

nickross4444, 2022-03-21:
@dforbush2, would you mind taking care of those new coefficients, I've got a bit on my plate this week. I think for now we'll try sticking to the 2nd order filter, as @DeepFriedDerp and I hard coded a lot of the processing in.

Closed 2022-04-20.

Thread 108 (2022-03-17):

Mode switching bug

nickross4444, 2022-03-17:
User testing showed wavemaker checksum was out of sync in function mode, and happened multiple times. Checksum should correct this but isn't.

ryancoe, 2022-11-04:
this is intermittent, we don't know the cause yet

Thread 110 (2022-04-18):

Hall effect error

nickross4444, 2022-04-18:
Since lengthening cables, we occasionally get a hall sensor error on the miniWEC motor controller, which stops operation. Previously ensuring the connector is snugly set has helped, but the error has since become more common.

Things to try/check:

- Check grounding
- Try shielding wherever possible
- RF Shielding
- Turn off wave probes
- Test if motor is AC or DC powered

Potentially useful link: https://support.maxongroup.com/hc/en-us/articles/4407394928146-EPOS4-Hall-sensor-error-0x7388-

nickross4444, 2022-04-20:
Oscilloscope showed the H1 signal was not consistently coming through the 24 pin connector on the box, though disassembling the connector showed no fault. Issue seems to be that the connector was twisting the wire in a way that made it have spotty continuity. Reassembling the connector with care not to twist the wires too much seems to have fixed it.

Solution for this issue in the future: Unscrew the 24 pin connector and confirm that pin 3(connected to H3) has continuity. Be careful not to get the wires to twisted when reassembling.

Closed 2022-04-20.

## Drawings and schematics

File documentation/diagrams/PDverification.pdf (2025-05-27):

2

3

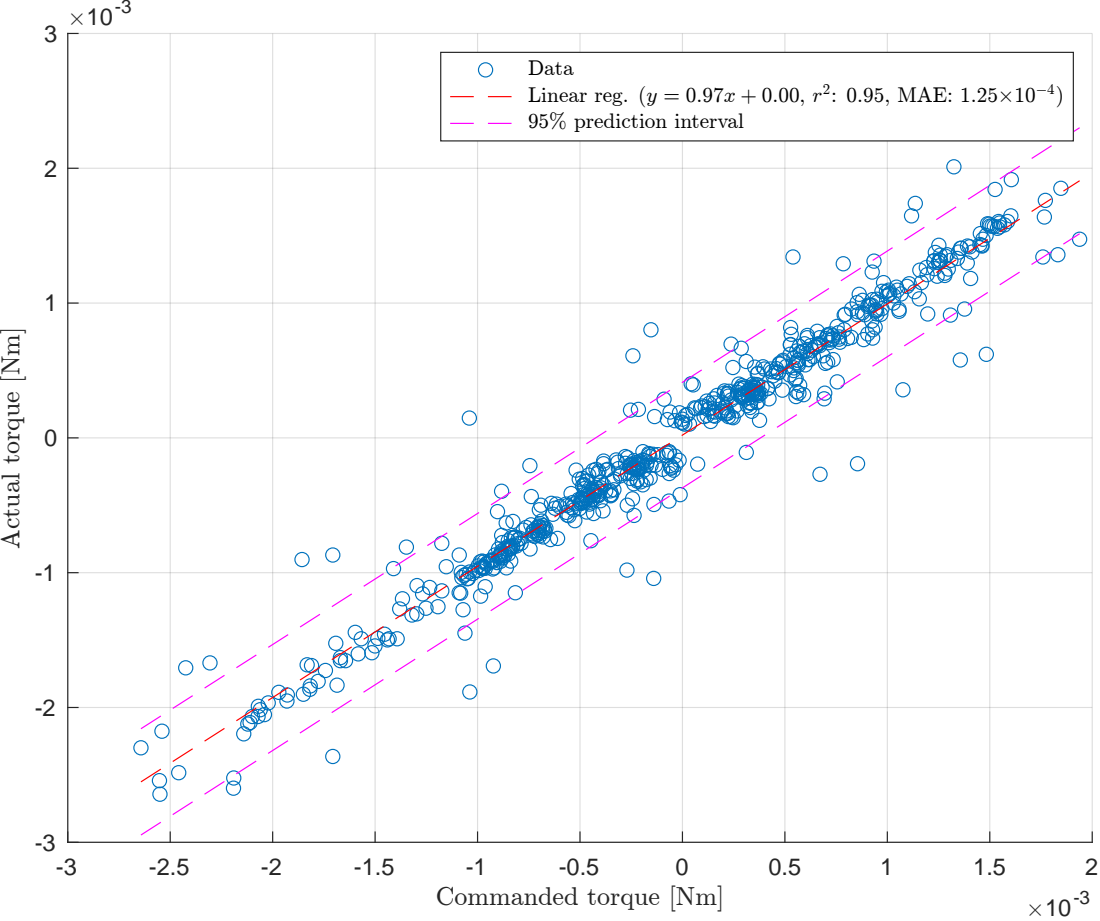
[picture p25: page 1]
Commanded torque [Nm]; Data Linear reg. (y = 0:97x + 0:00, r; MAE: 1.25#10!4); 95% prediction interval

Actual torque [Nm]

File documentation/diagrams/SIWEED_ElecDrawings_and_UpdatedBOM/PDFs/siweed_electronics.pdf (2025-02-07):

## ARDUINO DUE

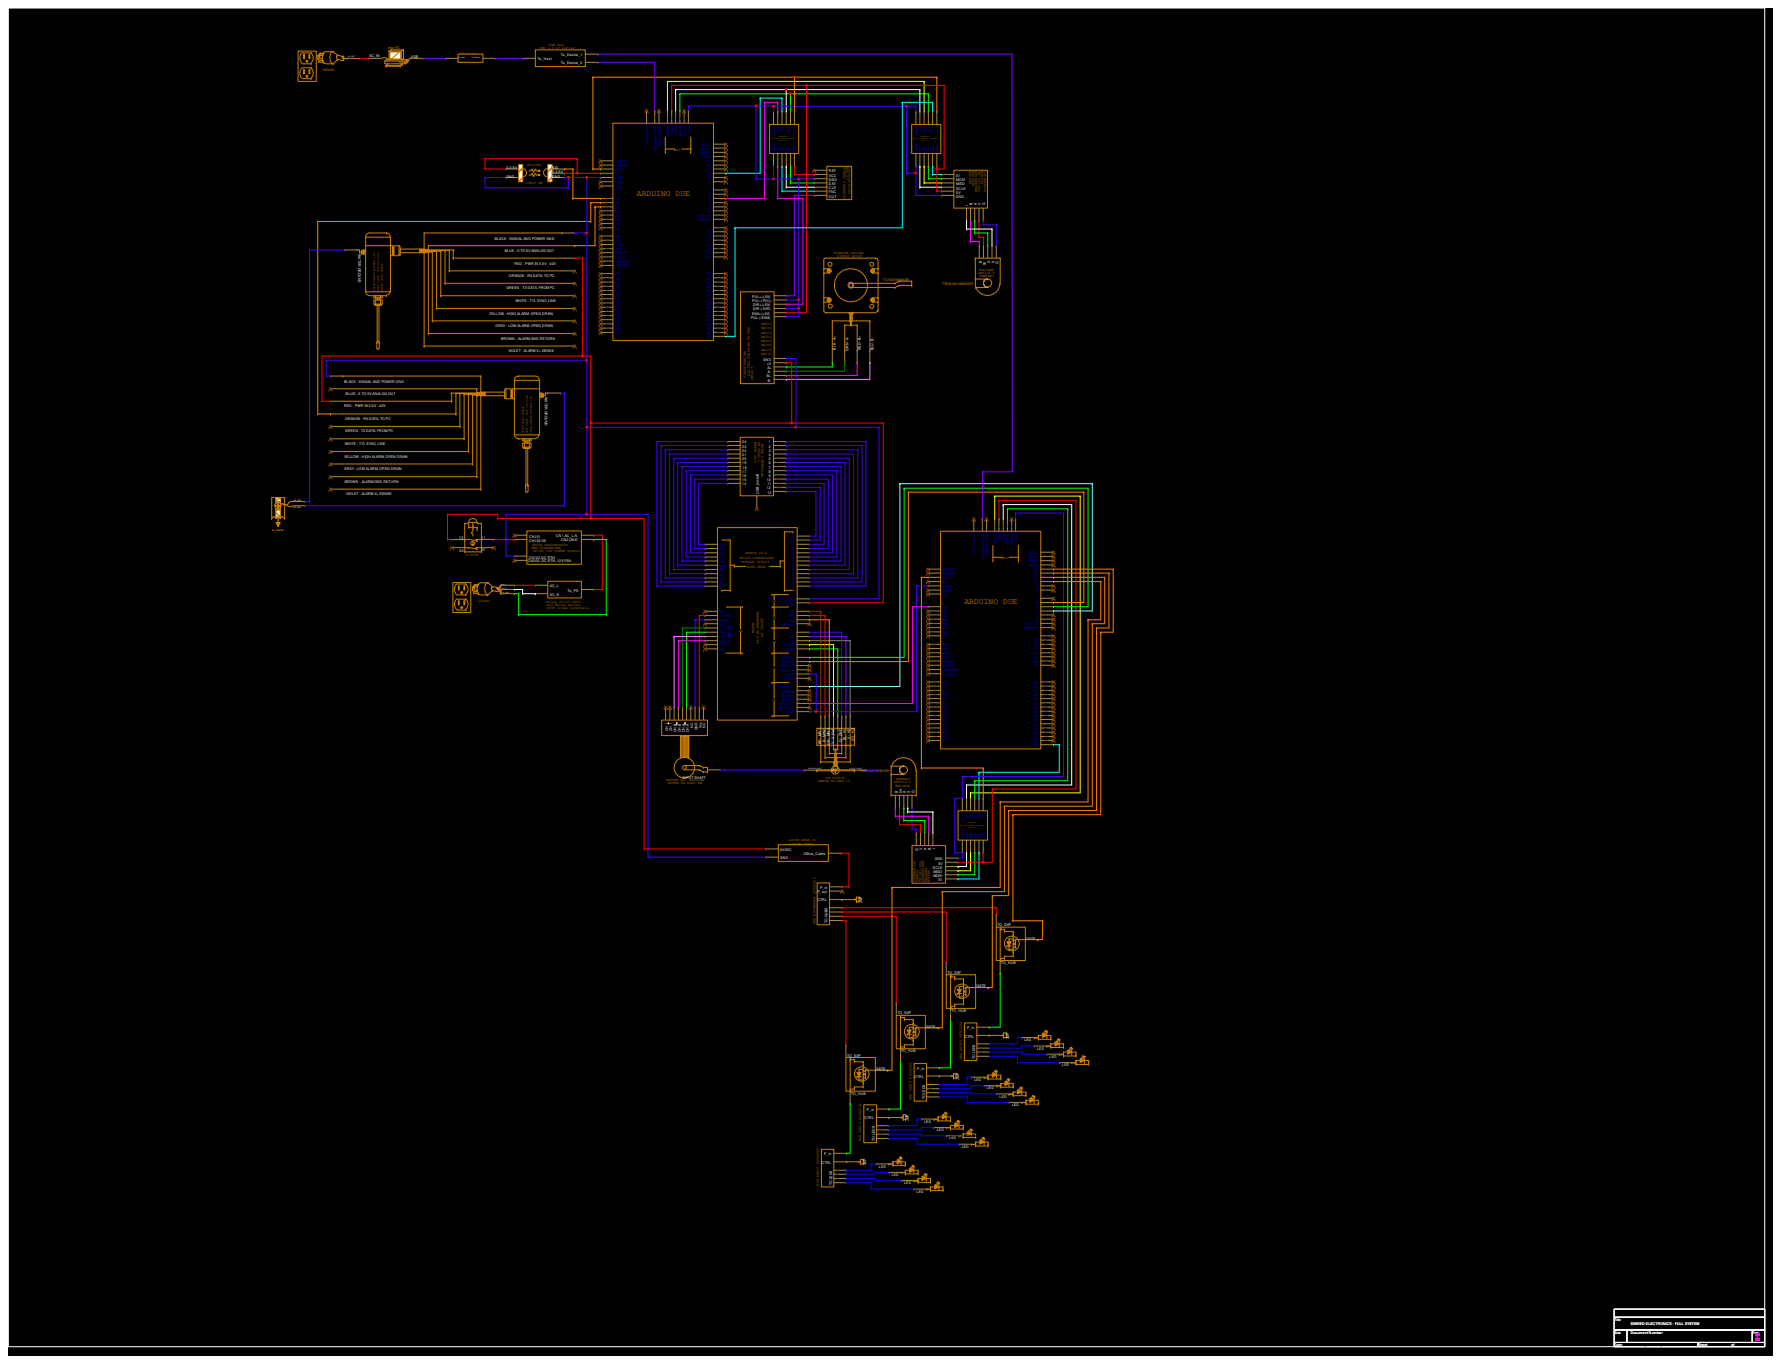
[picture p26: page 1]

HOST1 Host PC I1 USB 2.0 or better H1 USB Hub

3.3-5V | OPTICAL LIMIT SW

BLACK - SIGNAL AND POWER GND

OCEAN SENSOR SYSTEMS, INC.

BLUE - 0 TO 5V ANALOG OUT

GREEN - TX DATA, FROM PC

ORANGE - RX DATA, TO PC

WHITE - TTL SYNC LINE

YELLOW - HIGH ALARM, OPEN DRAIN

GRAY - LOW ALARM, OPEN DRAIN

BROWN - ALARM GND RETURN

DELTA ELECTRONICS
MDS-40OADB24AA
AC-DC 24V POWER SUPPLY
CN103,DC RTN
CN202, DC RTN, 12V FAN

SIWEED ELECTRONICS - FULL SYSTEM

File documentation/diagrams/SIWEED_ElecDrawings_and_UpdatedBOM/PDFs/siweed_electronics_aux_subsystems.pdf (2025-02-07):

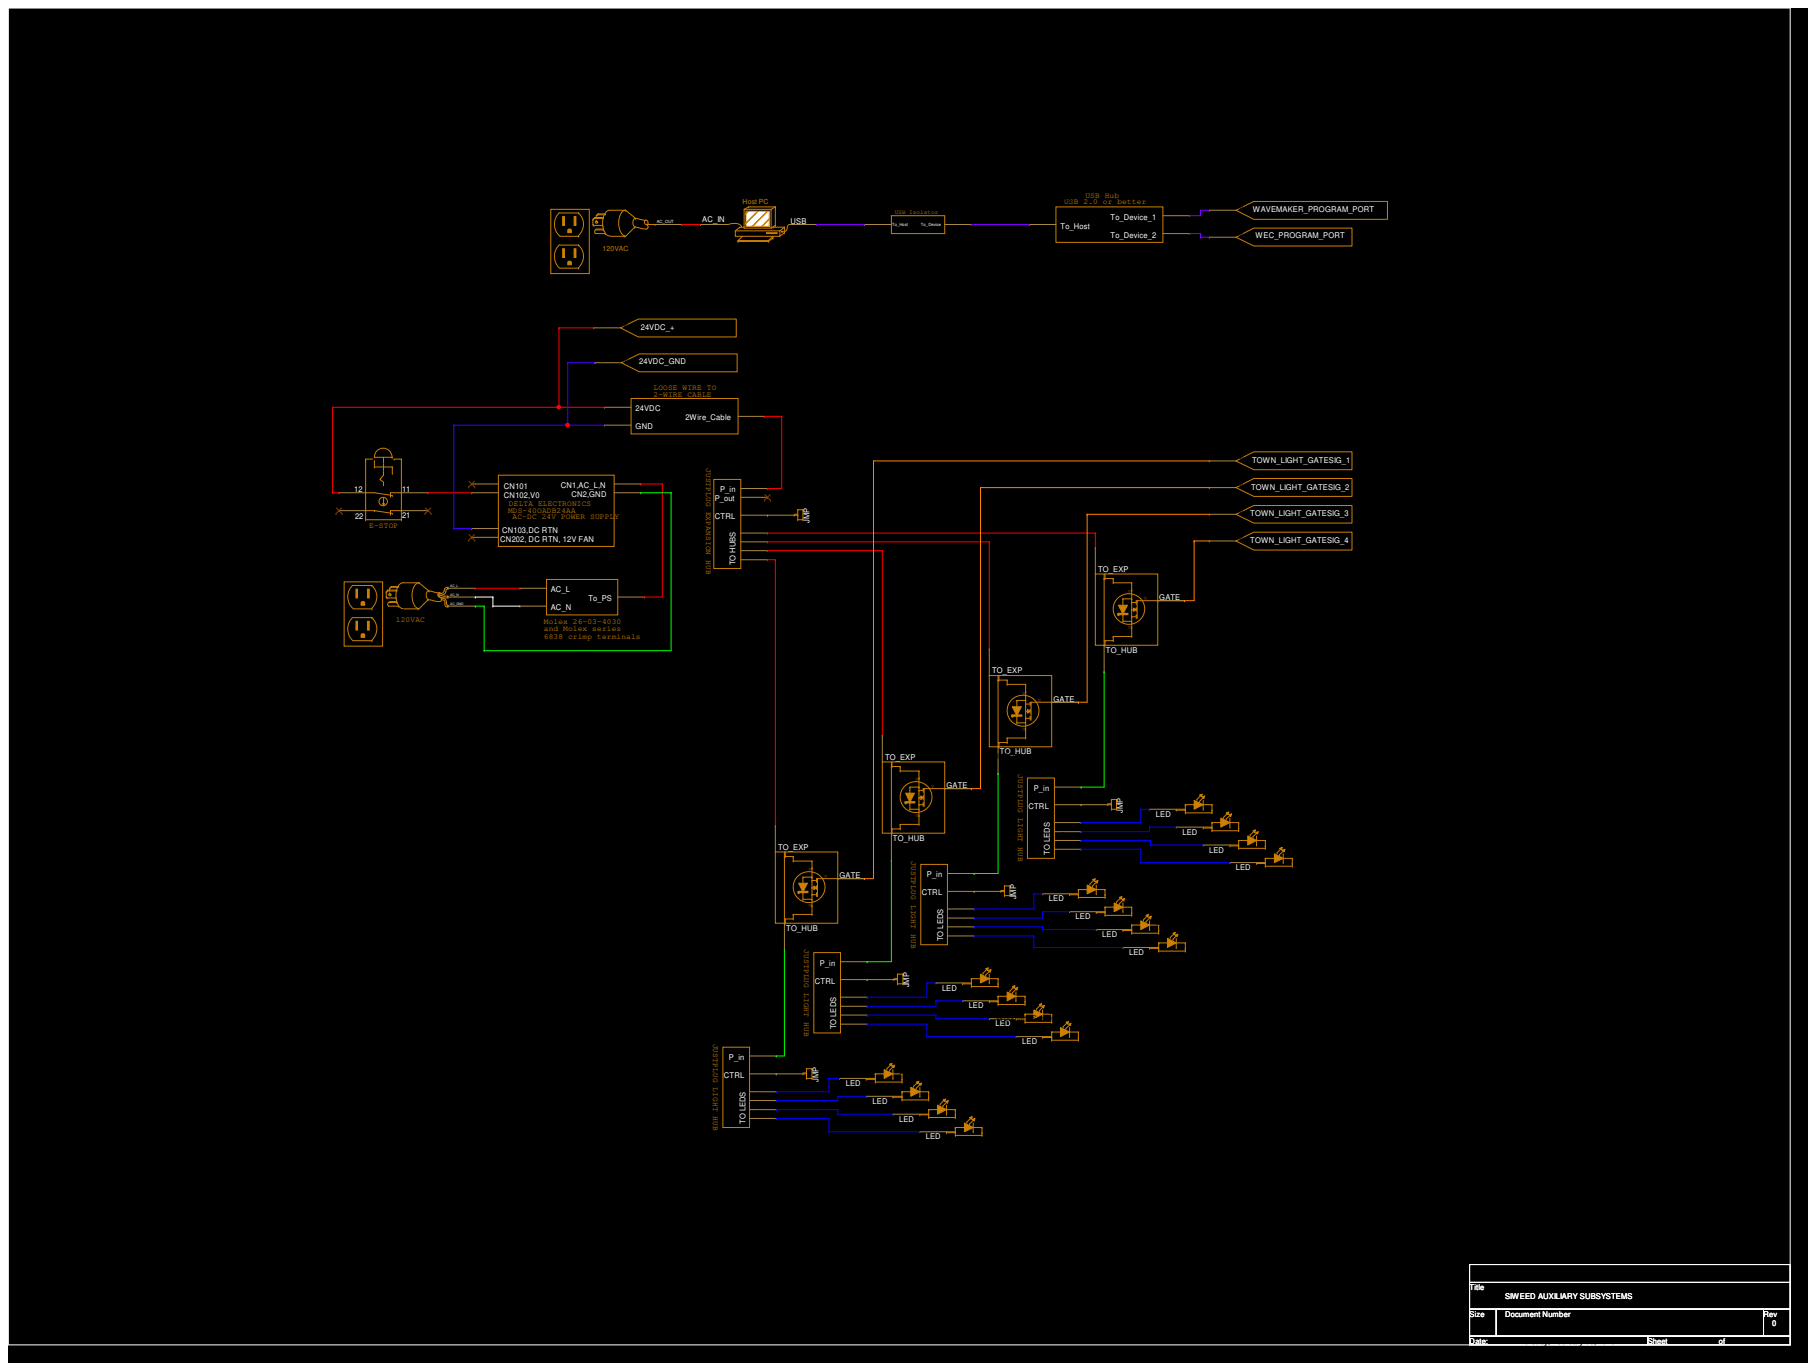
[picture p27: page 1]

USB Hub H1USB 2.0 or better

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

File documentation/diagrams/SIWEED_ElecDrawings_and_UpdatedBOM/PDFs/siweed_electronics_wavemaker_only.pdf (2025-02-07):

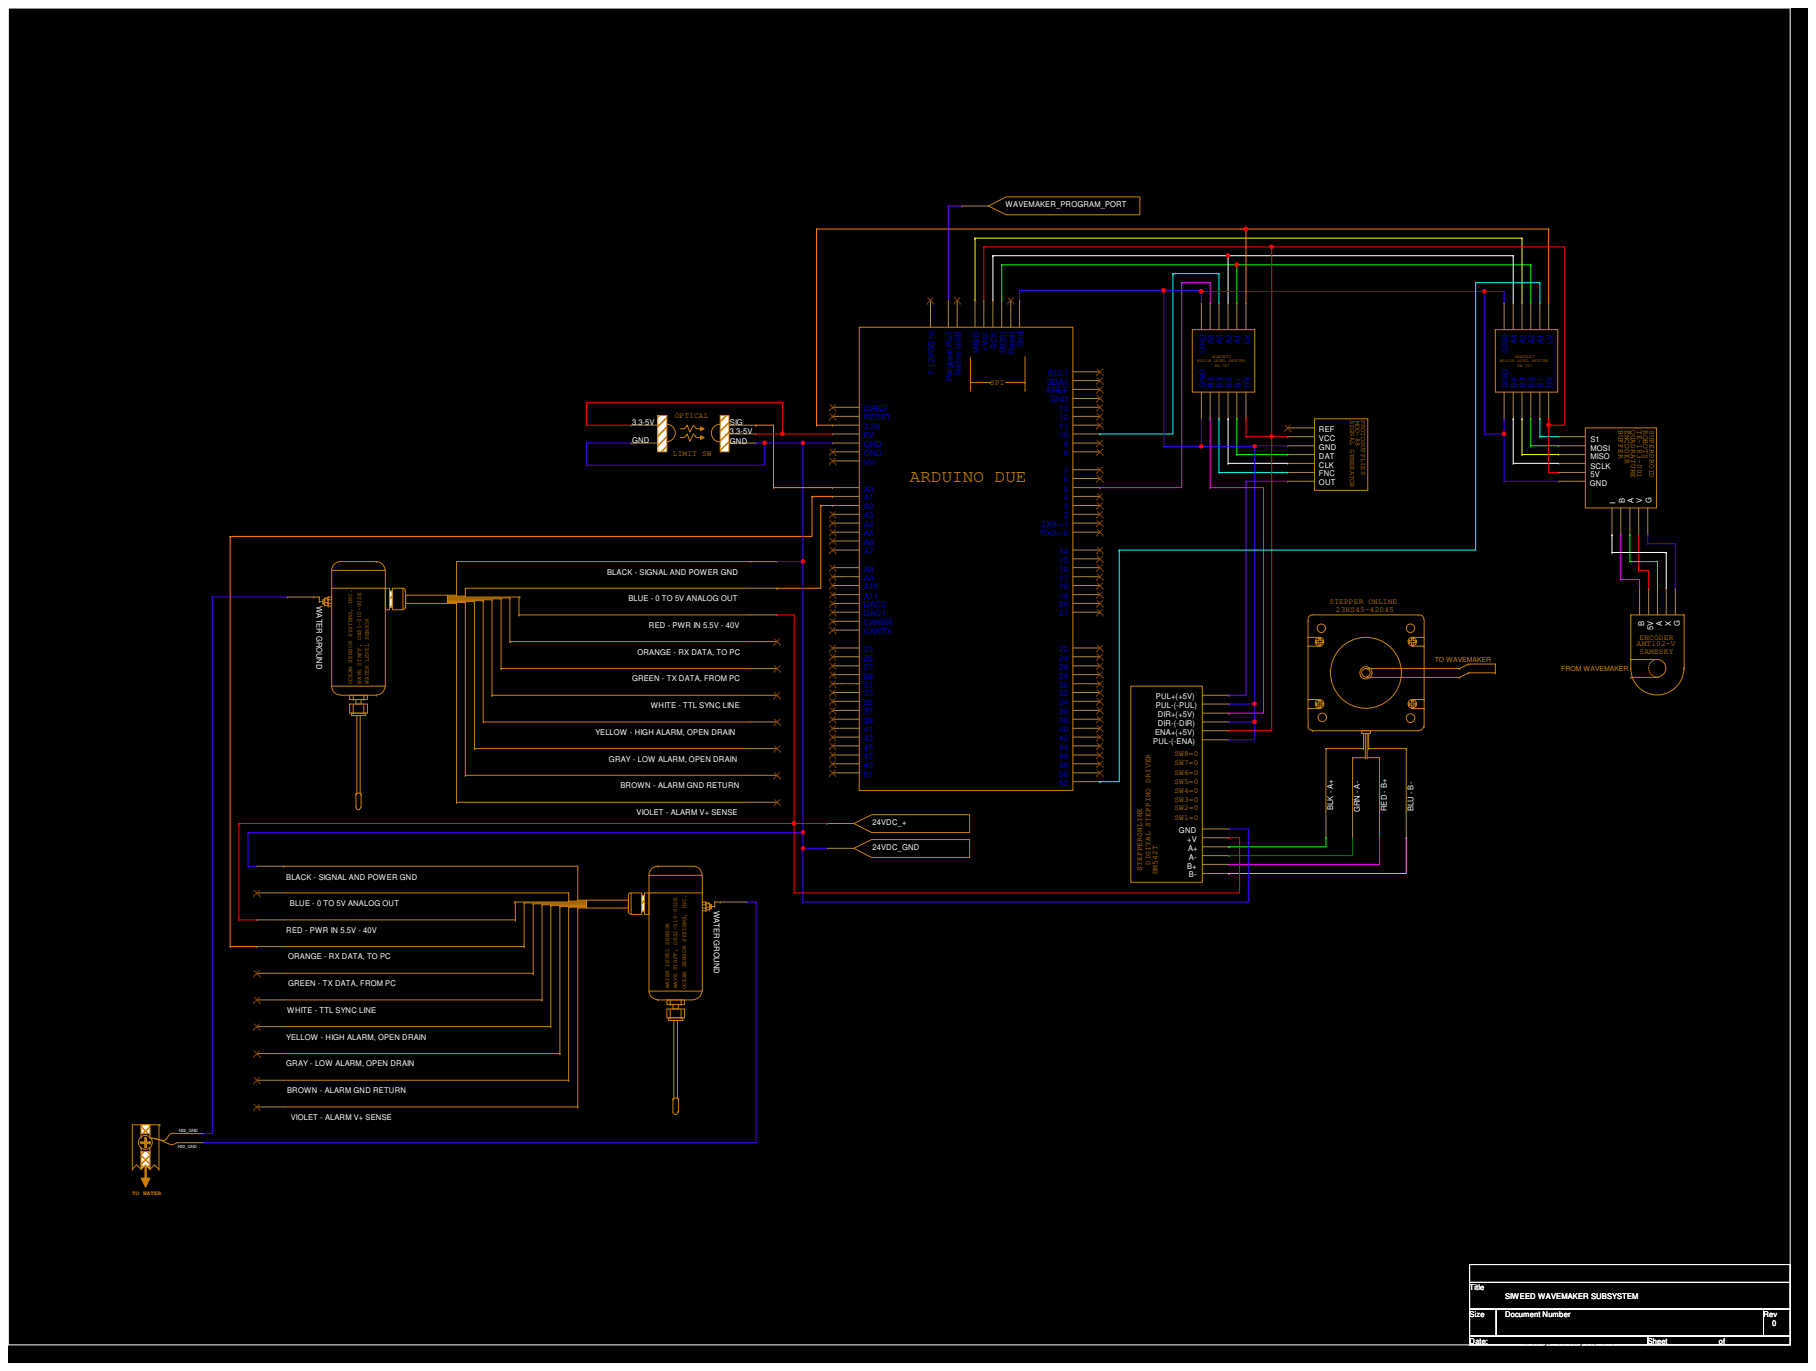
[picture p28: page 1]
Title; Size; Document Number; Rev; Date:; Sheet; <Doc>; 1Thursday, February 06, 2025; OSSI-010-002; WATER GROUND; STEPPER ONLINE 23HS45-42045; TO WAVEMAKER; SO_23HS45-42045_MOTOR; BLK - A+; GRN - A-; RED - B+; BLU - B-; TO WATER; ToWaterThruFrame; H20_GND; BUFFER; ENCODER; QUADRATURE; ROBOTS; SUPERDROID; IC3 SuperDroid_EncoderBuffer; S1 MOSI MISO SCLK 5V GND; ARDUINO DUE; SPI; MCU2; Arduino Due; GND; 14 AREF; 16 SDA1; 17 SCL1; DAC2; DAC1; CANRX; CANTX; Vin; RESET; IOREF; 7-12VDC In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

BLACK - SIGNAL AND POWER GND

OCEAN SENSOR SYSTEMS, INC.

WAVE STAFF, OSSI-010-002E

BLUE - 0 TO 5V ANALOG OUT

WATER LEVEL SENSOR

RED - PWR IN 5.5V - 40V

ORANGE - RX DATA, TO PC

GREEN - TX DATA, FROM PC

WHITE - TTL SYNC LINE

YELLOW - HIGH ALARM, OPEN DRAIN

GRAY - LOW ALARM, OPEN DRAIN

DIGITAL STEPPING DRIVER

BROWN - ALARM GND RETURN

VIOLET - ALARM V+ SENSE

SIWEED WAVEMAKER SUBSYSTEM

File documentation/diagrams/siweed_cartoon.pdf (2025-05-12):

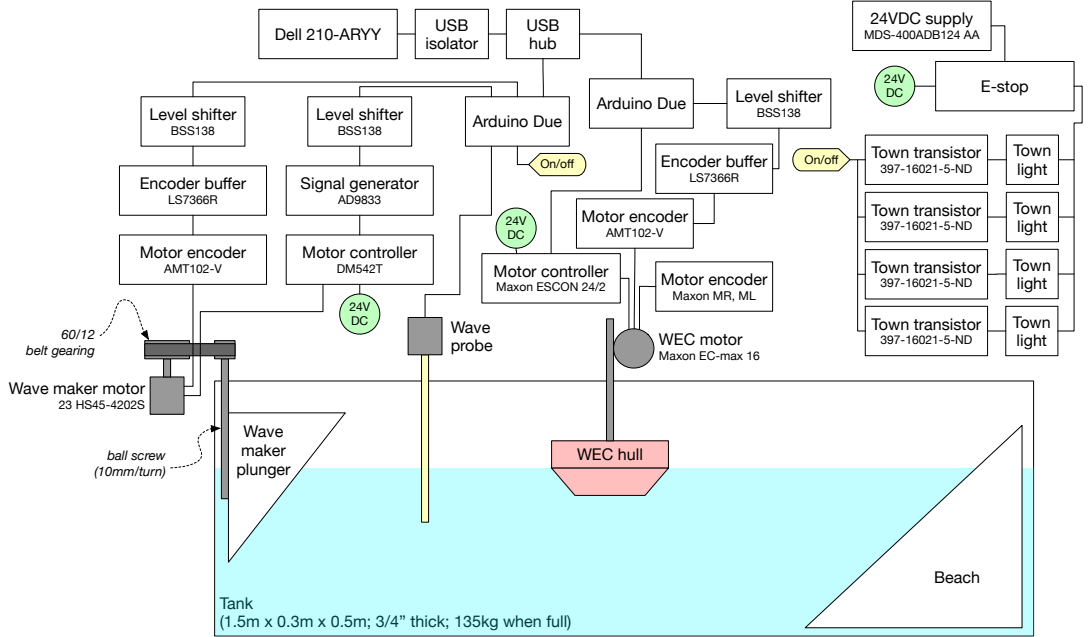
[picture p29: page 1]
Wave maker plunger; Beach; Wave probe; WEC hull; 60/12 belt gearing; ball screw (10mm/turn); Motor encoder AMT102-V; Encoder buffer LS7366R; Level shifter BSS138; Signal generator AD9833; Motor controller DM542T; Arduino Due; Dell 210-ARYY; USB; isolator; USB hub; Level shifter; BSS138; Motor controller Maxon ESCON 24/2; Town transistor 397-16021-5-ND; 24VDC supply MDS-400ADB124 AA; E-stop ²⁴V DC; Town; light On/off; On/off; Town light

Motor encoder
Maxon MR, ML

WEC motor
Maxon EC-max 16

Wave maker motor

Tank
(1.5m x 0.3m x 0.5m; 3/4” thick; 135kg when full)

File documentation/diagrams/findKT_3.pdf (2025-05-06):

2

3

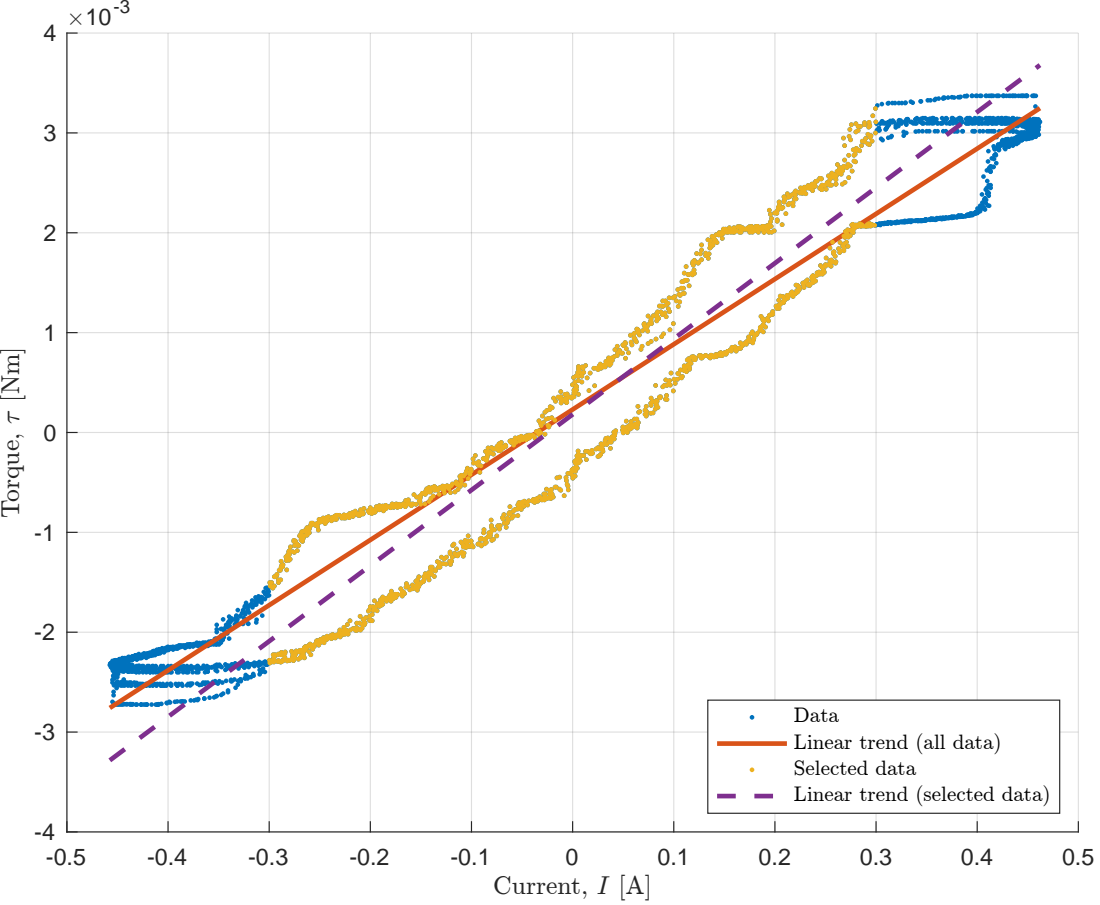
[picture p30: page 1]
Current, I [A]; Torque, = [Nm]

Data
Linear trend (all data) Selected Linear trend (selected data) | data

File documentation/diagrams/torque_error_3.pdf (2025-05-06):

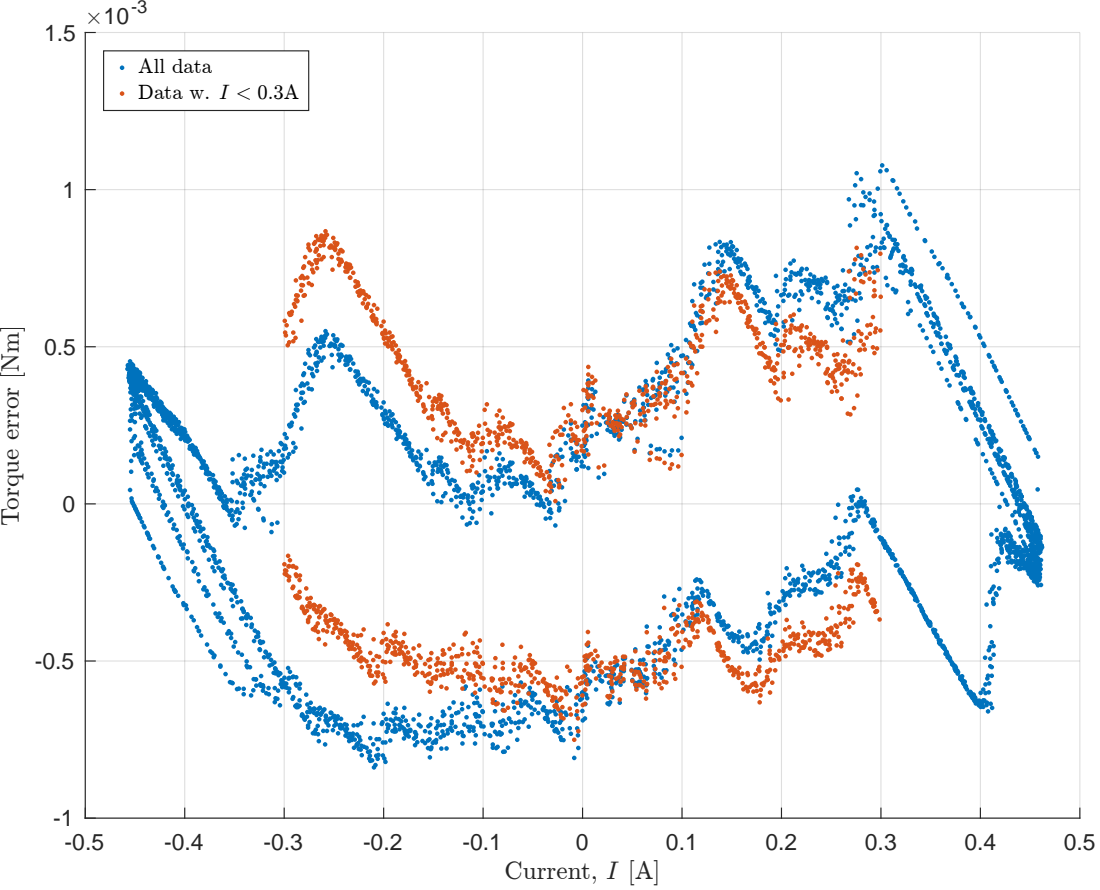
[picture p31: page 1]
Current, I [A]; All data; Data

Torque error [Nm]

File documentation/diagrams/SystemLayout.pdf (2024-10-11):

Mini Wave Tank System Layout | Digital Signal
Dell 210-ARYY (https://www.dell.com/en-us/work/shop/tablets-and-2-in-1-laptops/latitude-7200-2-in-1-business-laptop/spd/latitude-12-7200-2-in-1-laptop) | USB

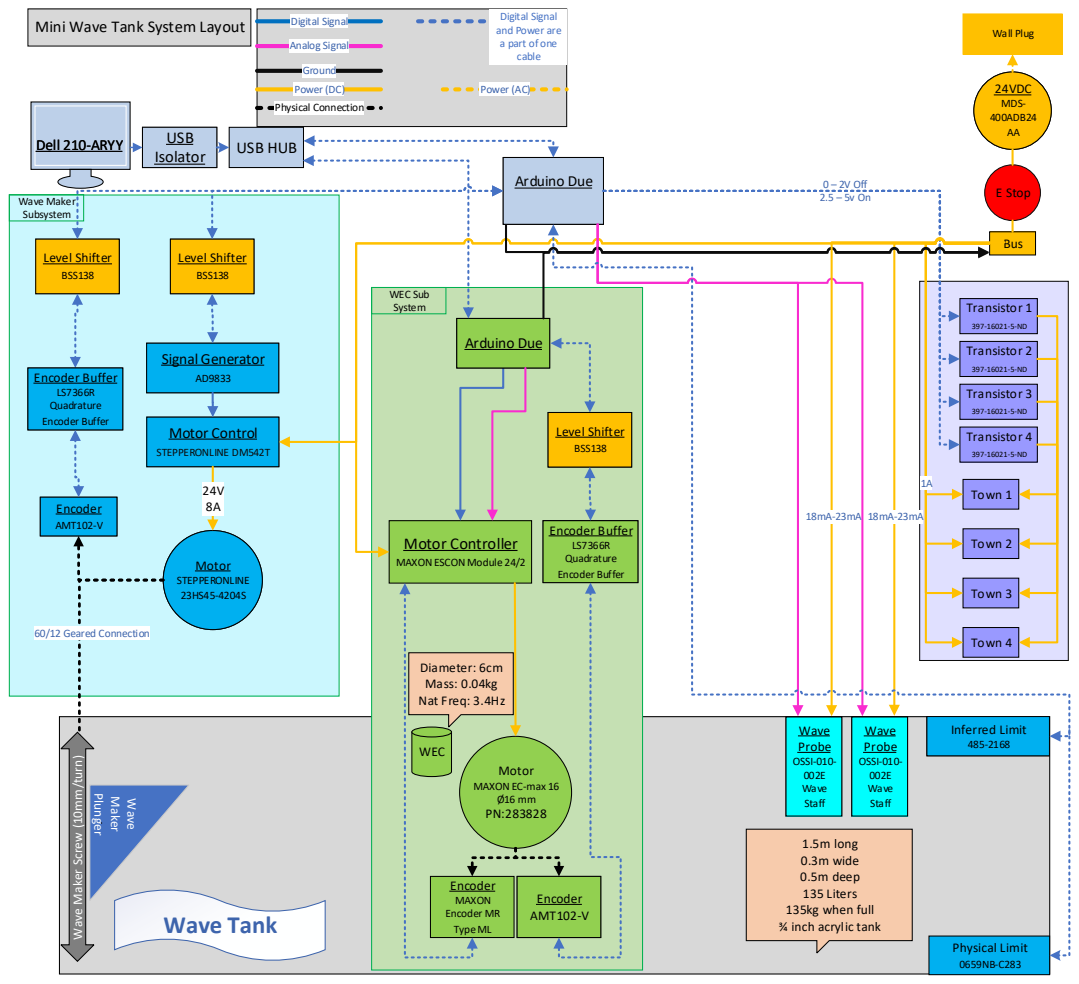
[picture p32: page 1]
Power (DC); Analog Signal; Ground; Power (AC); Isolator; USB HUB; Wall Plug; 24VDC MDS- 400ADB24 AA; E Stop; Arduino Due; Motor STEPPERONLINE 23HS45-4204S; Encoder; AMT102-V; Motor Control; STEPPERONLINE DM542T; Signal Generator; Wave Maker Subsystem; Encoder AMT102-V; WEC Sub System; Encoder Buffer LS7366R Quadrature Encoder Buffer; WEC; Town 1; Transistor 1; Transistor 2; Transistor 3; Transistor 4; Town 2; Town 3; Town 4; Bus; 0 – 2V Off 2.5 – 5v On; Inferred Limit 485-2168; Physical Limit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

Digital Signal
and Power are
a part of one
cable

Motor Controller
MAXON ESCON Module 24/2

Wave Maker Screw (10mm/turn)

Motor
MAXON EC-max 16

1.5m long
0.3m wide
0.5m deep
135 Liters
135kg when full
¾ inch acrylic tank

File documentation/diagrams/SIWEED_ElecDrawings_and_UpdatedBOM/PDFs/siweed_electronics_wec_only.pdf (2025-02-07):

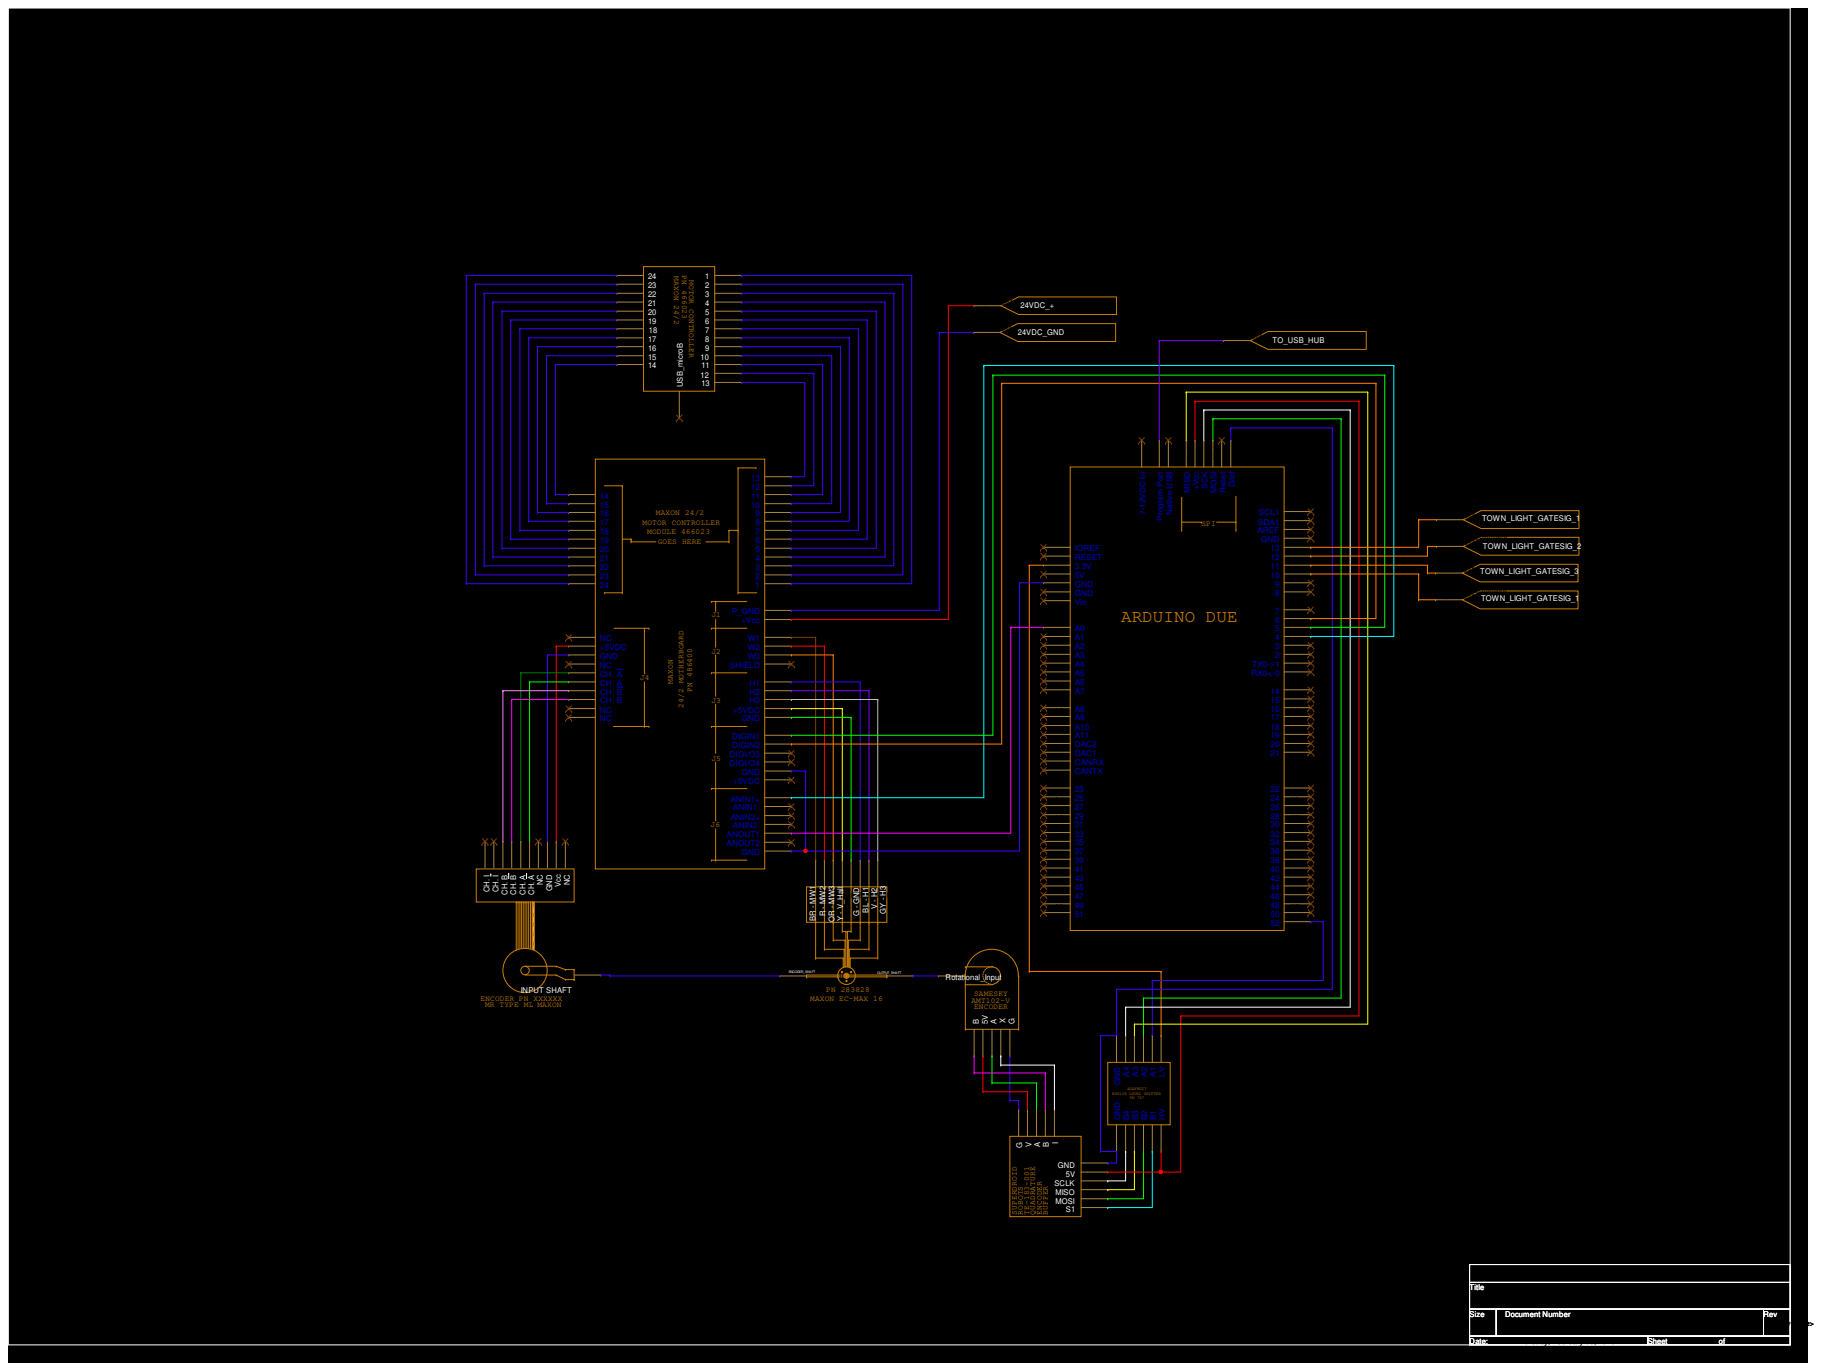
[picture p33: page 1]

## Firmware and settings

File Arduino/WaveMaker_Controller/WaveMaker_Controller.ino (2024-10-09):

#include <miniWaveTankJonswap.h>
#include <SuperDroidEncoderBuffer.h>
#include<DueTimer.h>
#include<math.h>
#include <SPI.h>
#include <MD_AD9833.h>
MD_AD9833  AD(10);  // Hardware SPI
miniWaveTankJonswap jonswap(512.0 / 64.0, 0.5, 2.5); //period, low frequency, high frequency. frequencies will be rounded to multiples of df(=1/period)
//jonswap(512.0 / 32.0, 0.5, 2.5);
//df = 1 / _period; num_fs = (int)((f_high - f_low) / df);
//^ISSUE. Acuracy seems to fall off after ~50 components when using higher frequencies(1,3 at 64 elements seems wrong).
SuperDroidEncoderBuffer encoderBuff(52);
bool encoderBuffInit, didItWork_MDR0, didItWork_MDR1, didItWork_DTR;   //variables for unit testing
unsigned char MDR0_settings = MDRO_x4Quad | MDRO_freeRunningCountMode | MDRO_indexDisable | MDRO_syncIndex | MDRO_filterClkDivFactor_1;
unsigned char MDR1_settings = MDR1_4ByteCounterMode | MDR1_enableCounting | MDR1_FlagOnIDX_NOP | MDR1_FlagOnCMP_NOP | MDR1_FlagOnBW_NOP | MDR1_FlagOnCY_NOP;
const int  dirPin = 5, limitPin = A0, probe1Pin = A1, probe2Pin = A2;
float initialProbe1;    //initial height of probe 1
volatile double t = 0;    //time in seconds
volatile float speedScalar = 0;
volatile int mode = 1;     // 1 = jog, 2 = function, 3 = sea, 4 = off
volatile int n = 1;            //number of functions for the time series(either 1 or jonswap.getNum())
const int maxComponents = 100;   //max needed number of frequency components
volatile float amps[maxComponents];
volatile float phases[maxComponents];
volatile float freqs[maxComponents];
volatile float sigH, peakF, gam, a, f;  //jonswap vars and amplitude and frequncy of sine wave //"gamma" is used in another library
//volatile float encPos;
bool newJonswapData = false, sendUnitTests = false;
volatile float j = 0;   //used for jog mode, starts at 0
const int buffSize = 10;    //number of data points buffered in the moving average filter
volatile float probe1Buffer[buffSize];
volatile float probe2Buffer[buffSize];
volatile float jogBuffer[buffSize];
const float maxRate = 0.25;   //max m/seconds
//Derived funciton here:
const float leadPitch = .01;     //m/turn
const float gearRatio = 12.0 / 60.0; //motor turns per lead screw turns
const float motorStepsPerTurn = 400.0;   //steps per motor revolution
const float encStepsPerTurn = 3200.0;

void setup() {
  initSerial();
  initialProbe1 = analogRead(probe1Pin);
  AD.begin();
  AD.setMode(MD_AD9833::MODE_SQUARE1);
  //encoder buffer setup:
  for (int i = 0; i < 10; i++)      //tries i times or until it works. Messy but functional
  {
    encoderBuffInit = encoderBuff.begin();    //configure encoder buffer and assign bools for unit testing
    didItWork_MDR0 = encoderBuff.setMDR0(MDR0_settings);
    didItWork_MDR1 = encoderBuff.setMDR1(MDR1_settings);
    if (encoderBuffInit && didItWork_MDR0 && didItWork_MDR1)
    {
      break;
    }
  }

  pinMode(dirPin, OUTPUT);
  pinMode(13, OUTPUT);
  digitalWrite(13, LOW);    //initialization of maxRate indicator led
  /////////Zero encoder:
  digitalWrite(dirPin, HIGH);
  AD.setFrequency(MD_AD9833::CHAN_0, 100);
  float initialPos = encPos();
  delay(20);
  while (analogRead(limitPin) > 500) {   //move up until the beam is broken
    if (encPos() - initialPos == 0)    //if motor is not moving(software testing), move on.
      break;
  }
  digitalWrite(dirPin, LOW);    //switch direction
  delay(20);
  while (analogRead(limitPin) < 500) {  //move down until the beam is unbroken
    if (encPos() - initialPos == 0)    //if motor is not moving(software testing), move on.
      break;
  }
  delay(500); //wait a little after beam is broken to be further down int the water
  AD.setFrequency(MD_AD9833::CHAN_0, 0);

  encoderBuff.command2Reg(CNTR, IR_RegisterAction_CLR); //zero encoder

  //fill moving average buffers with 0's:
  for (int i = 0; i < buffSize; i++) {
    probe1Buffer[i] = 0;
    probe2Buffer[i] = 0;
    jogBuffer[i] = 0;
  }
  //fill amps freqs and phases with 0's:
  for (int i = 0; i < maxComponents; i++) {
    amps[i] = 0;
    freqs[i] = 0;
    phases[i] = 0;
  }
  unitTests();
  initInterrupts();
}
volatile float encPos() {
  return encoderBuff.readCNTR() * (1 / encStepsPerTurn) * leadPitch * -1.0; //steps*(turns/step)*(m/turn)
}
void loop() {   //__ microseconds
  t = micros() / 1.0e6;
  readSerial();
  updateSpeedScalar();
  //  newJonswapData = true;    //to see what n is
  //  inputFnc(0);
  //  Serial.println(n);
}
void updateSpeedScalar() {    //used to prevent jumps/smooth start
  //Serial.println(speedScalar);

  if (speedScalar < 1) {
    speedScalar += .00007;   //value determined by testing
  } else {
    speedScalar = 1.0;
  }
}
volatile float mToSteps(volatile float m) {
  return m * (1 / leadPitch) * gearRatio * motorStepsPerTurn; //m*(lead turns/m)*(motor turns/lead turn)*(steps per motor turn)
}
volatile float mapFloat(volatile float x, volatile float in_min, volatile float in_max, volatile float out_min, volatile float out_max) {
  return (float)(x - in_min) * (out_max - out_min) / (float)(in_max - in_min) + out_min;
}
volatile float averageArray(volatile float* arr) {
  volatile float total = 0;
  for (volatile int i = 0; i < buffSize; i++) {
    total += arr[i];
  }
  total /= buffSize;
  return total;
}
volatile void pushBuffer(volatile float* arr, volatile float f) {
  for (volatile int i = buffSize - 1; i > 0; i--) {
    arr[i] = arr[i - 1];
  }
  arr[0] = f;
}
float lerp(float a, float b, float f) {
  return a + f * (b - a);
}
int intScaleFactor = 100000;
volatile int checksum() {     //adds the values of anything that can ba changes by processing.
  return (int)(intScaleFactor * mode) +
         (int)(intScaleFactor * j) +
         (int)(intScaleFactor * a) +
         (int)(intScaleFactor * f) +
         (int)(intScaleFactor * sigH) +
         (int)(intScaleFactor * peakF) +
         (int)(intScaleFactor * gam);
}
bool ampUnitTest = true, TSUnitTest = true, encoderTest = true;
//float exampleAmps[] = {0.00, 0.00, 0.00, 0.00, 0.00, 0.00, 0.00, 0.00, 0.00, 0.00, 0.00, 0.00, 0.00, 0.00, 0.00, 0.00, 0.01, 0.02, 0.05, 0.11, 0.20, 0.33, 0.48, 0.67, 0.87, 1.09, 1.30, 1.51, 1.7, 1.88, 2.03, 2.16};
//float exampleAmps[] = {0.00, 0.00, 0.00, 0.00, 0.00, 0.00, 0.00, 0.00, 0.01, 0.09, 0.32, 0.77, 1.39, 2.08, 2.72, 3.25};
float exampleAmps[] = {0.00, 0.00, 0.00, 0.00, 0.00, 0.00, 0.00, 0.00, 0.00, 0.00, 0.00, 0.00, 0.00, 0.00, 0.00, 0.00};
//float exampleTS[] = {2.13, -1.08, 3.21, 3.02, -0.65, 0.42, 0.96, -3.35, 3.49, -3.32, 1.43, 4.24, 3.59, 2.01, -7.29, 4.79, 2.13, -1.08, 3.21, 3.02, -0.65, 0.42, 0.96, -3.35, 3.49, -3.32, 1.43, 4.24, 3.59, 2.01, -7.29, 4.79};
//float exampleTS[] = {2.24, -0.75, 3.53, -3.00, -3.04, 8.26, 2.77, 0.98, 2.24, -0.75, 3.53, -3.00, -3.04, 8.26, 2.77, 0.98};
float exampleTS[] = {0.00, 0.00, 0.00, 0.00, 0.00, 0.00, 0.00, 0.00, 0.00, 0.00, 0.00, 0.00, 0.00, 0.00, 0.00, 0.00};
void unitTests() {
  newJonswapData = true;
  int oldMode = mode;
  //miniWaveTankJonswap jonswapTest(16.0, 1.0, 2.0)
  mode = 2;
  //jonswap.update(5.0, 3.0, 7.0);
  sigH = 5.0;
  peakF = 3.0;
  gam = 7.0;
  posFnc(0);   //assign amps and update jonswap
  for (int i = 0; i < jonswap.getNum(); i++) {
    //test amplitude array:
    if (abs(amps[i] - exampleAmps[i]) > 0.01) {
      ampUnitTest = false;
    }

    //test time series:
    if (abs(posFnc(i) - exampleTS[i]) > 0.01) {      //i acts as an arbitrary time
      TSUnitTest = false;
    }
    //////////////////////////////
    //Serial.print(amps[i]);    //To get the data that fills the example arrays
    //Serial.print(posFnc(i));
    //Serial.print(", ");
    ////////////////////////////
  }
  //Serial.println("done");
  //while(1);
  sigH = 0;   //return values to 0, so checksum is correct
  peakF = 0;
  gam = 0;
  //////////////////test encoder buffer:
  //If the initialization and setting functions worked, move on, otherwise, throw error and halt execution.
  if (encoderBuffInit && didItWork_MDR0 && didItWork_MDR1) {
    //passed
  } else {
    encoderTest = false;
  }
  mode = oldMode;   //reset mode to what it was before unit tests

}

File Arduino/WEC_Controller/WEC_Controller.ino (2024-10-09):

#include <SuperDroidEncoderBuffer.h>
#include<DueTimer.h>
#include<math.h>
#include <miniWaveTankJonswap.h>
miniWaveTankJonswap jonswap(512.0 / 64.0, 0.5, 2.5); //period, low frequency, high frequency. frequencies will be rounded to multiples of df(=1/period)
//^ISSUE. Acuracy seems to fall off after ~50 components when using higher frequencies(1,3 at 64 elements seems wrong).
SuperDroidEncoderBuffer encoderBuff = SuperDroidEncoderBuffer(52);
bool encoderBuffInit, didItWork_MDR0, didItWork_MDR1, didItWork_DTR;   //variables for unit testing
unsigned char MDR0_settings = MDRO_x4Quad | MDRO_freeRunningCountMode | MDRO_indexDisable | MDRO_syncIndex | MDRO_filterClkDivFactor_1;
unsigned char MDR1_settings = MDR1_4ByteCounterMode | MDR1_enableCounting | MDR1_FlagOnIDX_NOP | MDR1_FlagOnCMP_NOP | MDR1_FlagOnBW_NOP | MDR1_FlagOnCY_NOP;
bool newJonswapData = false, sendUnitTests = false;
volatile float sigH, peakF, gam;
volatile int mode = 0;     //1 = jog, 2= feedback, 3 = "sea", 4 = off
volatile int n;   //number of components
volatile double t = 0;    //time in seconds
volatile float tau = 0, kp = 0, kd = 0, power = 0, vel = 0;
volatile float tauCommand = 0, tauCommanded = 0;   //incoming tau and outgoing tau(in case it saturates)
const int tauPin = 4, enablePin = 5, dirPin = 6, l1Pin = 10, l2Pin = 11, l3Pin = 12, l4Pin = 13, tauInPin = A0;
const float ProcessingScaleFactor = 90000;
const float l1Lim = 1 / ProcessingScaleFactor, l2Lim = 2 / ProcessingScaleFactor, l3Lim = 3 / ProcessingScaleFactor, l4Lim = 4 / ProcessingScaleFactor; //the power thresholds of the led groups. threshold/WEC Power scale in processing
//volatile float encPos;
const float encStepsPerTurn = 8192;   //for 800 ppr/3200 counts per revolution set dip switches(0100) //2048ppr/8192 counts per revolution max(0000)
const float teethPerTurn = 20;
const float mPerTooth = 0.002;
const float minPwm = .1, maxPwm = .9;
const float minAmps = 0, maxAmps = 0.7620;    //amperage at min and max pwm //0.456
const float torqueConstant = 0.00752;   //7.8 mNm/A is spec, testing gave us 7.52 mNm/A

const int maxComponents = 100;   //max needed number of frequency components
volatile float amps[maxComponents];
volatile float phases[maxComponents];
volatile float freqs[maxComponents];

const int buffSize = 100;    //number of data points buffered in the moving average filter
volatile float powBuff[buffSize];
volatile float avPower = 0;

void setup()
{
  initSerial();
  analogWriteResolution(12);    //analog write now runs from 0 to 4095
  analogReadResolution(12);     //analog read now runs from 0 to 4095
  pinMode(enablePin, OUTPUT);
  digitalWrite(enablePin, LOW);
  pinMode(dirPin, OUTPUT);
  digitalWrite(dirPin, LOW);
  pinMode(tauPin, OUTPUT);

  pinMode(l1Pin, OUTPUT);
  digitalWrite(l1Pin, HIGH);
  pinMode(l2Pin, OUTPUT);
  digitalWrite(l2Pin, HIGH);
  pinMode(l3Pin, OUTPUT);
  digitalWrite(l3Pin, HIGH);
  pinMode(l4Pin, OUTPUT);
  digitalWrite(l4Pin, HIGH);
  delay(1000);      //keep the lights on for 1 second
  digitalWrite(l1Pin, LOW);
  digitalWrite(l2Pin, LOW);
  digitalWrite(l3Pin, LOW);
  digitalWrite(l4Pin, LOW);
  delay(100);
  for (int i = 0; i < 10; i++)      //tries i times or until it works. Messy but functional
  {
    encoderBuffInit = encoderBuff.begin();    //configure encoder buffer and assign bools for unit testing
    didItWork_MDR0 = encoderBuff.setMDR0(MDR0_settings);
    didItWork_MDR1 = encoderBuff.setMDR1(MDR1_settings);
    if (encoderBuffInit && didItWork_MDR0 && didItWork_MDR1)
    {
      break;
    }
  }
  encoderBuff.command2Reg(CNTR, IR_RegisterAction_CLR); //zero encoder

  unitTests();
  initInterrupts();

  //fill moving average buffers with 0's:
  for (int i = 0; i < buffSize; i++) {
    powBuff[i] = 0;
  }
}
volatile float encPos() {
  return encoderBuff.readCNTR() * (1 / encStepsPerTurn) * teethPerTurn * mPerTooth; //steps*(turns/step)*(m/turn)
}
void loop()
{
  t = micros() / 1.0e6;
  power = -tauCommanded * vel; //negative power is negative work done by the WEC (absorbed power) This in inverted to make more sense to the user.
  readSerial();

  if (avPower > l4Lim)
  {
    digitalWrite(l1Pin, HIGH);
    digitalWrite(l2Pin, HIGH);
    digitalWrite(l3Pin, HIGH);
    digitalWrite(l4Pin, HIGH);
  }
  else if (avPower > l3Lim)
  {
    digitalWrite(l1Pin, HIGH);
    digitalWrite(l2Pin, HIGH);
    digitalWrite(l3Pin, HIGH);
    digitalWrite(l4Pin, LOW);
  }
  else if (avPower > l2Lim)
  {
    digitalWrite(l1Pin, HIGH);
    digitalWrite(l2Pin, HIGH);
    digitalWrite(l3Pin, LOW);
    digitalWrite(l4Pin, LOW);
  }
  else if (avPower > l1Lim)
  {
    digitalWrite(l1Pin, HIGH);
    digitalWrite(l2Pin, LOW);
    digitalWrite(l3Pin, LOW);
    digitalWrite(l4Pin, LOW);
  }
  else
  {
    digitalWrite(l1Pin, LOW);
    digitalWrite(l2Pin, LOW);
    digitalWrite(l3Pin, LOW);
    digitalWrite(l4Pin, LOW);
  }
}

volatile float mapFloat(volatile float x, volatile float in_min, volatile float in_max, volatile float out_min, volatile float out_max)
{
  return (float)(x - in_min) * (out_max - out_min) / (float)(in_max - in_min) + out_min;
}
volatile float calcTS(volatile float tm) {      //calculate jonswap timeseries values at time tm
  if (newJonswapData) {
    newJonswapData = false;
    jonswap.update(sigH, peakF, gam);
    n = jonswap.getNum();
    for (int i = 0; i < n; i++) {
      amps[i] = jonswap.getAmp(i);
      freqs[i] = jonswap.getF(i);
      phases[i] = jonswap.getPhase(i);
    }
  }
  volatile float val = 0;
  for (volatile int i = 0; i < n; i++)
  {
    val += amps[i] * sin(2 * PI * tm * freqs[i] + phases[i]);
  }
  return val;
}
int intScaleFactor = 100000;
volatile int checksum() {
  //return mode + tau + kp + kd + sigH + peakF + gam;//adds the values of anything that can ba changes by processing.
  return (int)(intScaleFactor * mode) +
         (int)(intScaleFactor * tau) +
         (int)(intScaleFactor * kp) +
         (int)(intScaleFactor * kd) +
         (int)(intScaleFactor * sigH) +
         (int)(intScaleFactor * peakF) +
         (int)(intScaleFactor * gam);
}
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

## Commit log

2020-03-01 example csv file
    [exampleFormat.csv]
2020-03-06 created arduino directory and added files
2020-03-09 created framework for serial communication
2020-03-12 remove extra GUI directory
    [exampleFormat.csv]
2020-03-12 don't track java build artifacts
2020-03-13 added 5 second delay after port initialization to fix serial
    [siweedGUI.pde]
2020-03-13 added notes to the processing sketch and renamed the main arduino sketch
2020-03-19 added mode funcitonality on processing and limit switch in arudino setup. Started smooth start ramp
2020-03-19 added framework for sending serial from arduino to processing
2020-03-20 started getting serial from arduino to processing. Needs work
2020-03-21 Finished 2-way serial and added framerate counting
2020-03-25 multi-threaded serial and cleaned up
2020-03-25 experimental error corretion for the wavemaker
    [WaveMaker_Controller.ino, siweedGUI.pde]
2020-03-25 reads and sends probe values. Needs calibration
2020-03-25 added float mapping for wave probes
2020-03-25 arduino can now send multiple variables to processing
2020-03-25 forgot to pass tau for torque control mode
2020-03-27 2 way serial with both boards from processing added. Needs fixing to send enough data from the arduino
    [WEC_Controller.ino, WaveMaker_Controller.ino, siweedGUI.pde]
2020-04-05 fixed serial by increasing baud rate and added a moving average to the probe signals
    [WEC_Controller.ino, WaveMaker_Controller.ino, siweedGUI.pde]
2020-04-07 made all interupt related variables volatile for stability
    [WEC_Controller.ino, WaveMaker_Controller.ino]
2020-04-13 fixed old mode variable inconsistency
    [siweedGUI.pde]
2020-04-13 tried to implement jonswap. having memory issues
    [siweedGUI.pde]
2020-04-13 fixed issue with re-loading images
    [siweedGUI.pde]
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2020-05-22 tried to fix serial, started FFS, organized code into tabs
    [WEC_Controller.ino, WaveMaker_Controller.ino, siweedGUI.pde]
2020-05-22 added other tabs
    [4-13-2020_13-24-5.csv, 4-13-2020_13-25-8.csv, 4-13-2020_13-26-59.csv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]
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2020-06-01 replaced fft with official classes
    [Serial.pde, WaveMaker_Controller.ino, siweedGUI.pde]
2020-06-01 added missing files
    [5-21-2020_18-57-1.csv, 5-21-2020_18-59-45.csv, 5-21-2020_19-1-12.csv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]
2020-06-24 added new libraries and moved jonswap to arduino. needs work
    [6-1-2020_18-34-24.csv, 6-1-2020_18-35-18.csv, 6-1-2020_18-36-40.csv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]
2020-06-25 reorganized into tabs
    [6-25-2020_13-57-28.csv, 6-25-2020_13-58-6.csv, 6-25-2020_13-59-56.csv]
2020-06-25 fixed interupt init bug
    [WaveMaker_Controller.ino]
2020-06-26 this shows the sizing issue in SM
    [Serial.ino, WaveMaker_Controller.ino]
2020-06-26 removed jonswap constructor-did not work
    [Serial.ino, WaveMaker_Controller.ino]
2020-06-29 added missed files
    [6-25-2020_22-11-52.csv, 6-25-2020_22-20-40.csv, 6-25-2020_22-23-22.csv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]
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2020-07-03 fixed mac serial com bug
    [Serial.pde, siweedGUI.pde]
2020-07-04 fixing fullscreen
    Lines starting
    [siweedGUI.pde]
2020-07-04 added gitignore and torque buttons
2020-07-06 Added wave button and pop up
2020-07-13 fixed gamma redeclaration issue
    [WEC_Controller.ino]
2020-07-13 don't track LaTex compilation artifacts and change name
2020-07-14 deleted some redundancies, fixed potential serial issue, and
    [Interrupts.ino, Serial.ino, Serial.pde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]
2020-07-16 changed button and slider sizes
2020-07-16 fixed color and size
    [UI.pde]
2020-07-17 fixed pop up buttons
    [UI.pde]
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2020-07-21 added data input to power meter
2020-07-29 title changes / bottom banner / power bar
2020-07-29 made buttons function of buttonX and buttonY
2020-07-30 deleted superfluous photo, changed button sizes, fixed text alignment
    [UI.pde, siweedGUI.pde]
2020-07-30 fixed ? button placement
    [UI.pde]
2020-07-31 tried ArduinoSTL as opposed to StandardCplusplus
2020-08-07 buttons change color when clicked
2020-08-07 wec buttons change color when clicked
2020-08-07 power status background color
2020-08-10 add some background material in paper
2020-08-11 switched graphs, changed line color, changed graph names
2020-08-12 radio buttons added. wave buttons work
2020-08-13 wec buttons work now and some color changes
2020-08-13 added wecVel var to log, and attached data to plots
2020-08-13 processing now runs without arduinos, but one arduino will not work without the other
    [Serial.pde, UI.pde, UnitTests.pde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]
2020-08-13 now one board can be connected at a time and still work
2020-08-18 lab day changes
    [5-26-2020_12-44-52.csv, 6-1-2020_2-25-27.csv, 6-15-2020_11-52-6.csv]
2020-08-19 Added encoder buffer library
    Added the base library files (two header files, and one source file) complete with very basic doxygen documentation and the corresponding html/LaTeX output files (see html/index.html, majority of doc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
2020-08-24 added accel Stepper for low speeds
2020-08-24 fixed potential tone bug
    [Interrupts.ino]
2020-09-14 fixed serial and unit test issue
    [Serial.ino, Serial.pde, UnitTests.pde]
2020-09-29 started integrating new encoder library, still needs work
2020-10-14 Updated Example to control Servo
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2020-10-27 Added the amt encoder to wec
2020-11-04 added new signal generator library for multi SPI compatability
2020-11-05 Rough Draft for Wavemaker flow chart
2020-11-06 fixed a gear ratio
    [WaveMaker_Controller.ino]
2020-11-11 added PID, needs tuning
2020-11-15 changed power sign convention and developed motor control
2020-11-15 fixed resolution from 8 bit to 12 bit
    [Interrupts.ino]
2020-11-17 hide show console button
2020-11-24 frequency is now directly commanded by PID
2020-12-24 float to bin conversion functions were fixed. Serial still needs testing
    [Interrupts.ino, Serial.ino]
2021-01-05 new linear and PID controller
2021-01-05 Control algorithm for PID Controller
2021-01-05 Create PID Controller Documentation
2021-01-11 Changed Buttons Text to be more readable
2021-01-20 fixed arduino serial aquisition bug. readSerial() functions were not able to empty buffer, so ran endlessly. It is possible that the buffer will now overflow, needs testing
    [Interrupts.ino, Serial.pde, siweedGUI.pde]
2021-01-28 fixed issues caused by the merge
    [Interrupts.ino, Serial.ino, WaveMaker_Controller.ino]
2021-02-01 changed off functions so they don't reset slider values
    [UI.pde]
2021-02-05 Added console button, and print hello world when pushed
2021-02-05 Added console, able to be toggled by button
2021-02-11 Resolved multiple issues, no longer calling for cp5 every text box.
    I commented meter out, and there is much less usage in everything. I have also changed everything to draw once in the setup.
    [siweedGUI.pde]
2021-02-11 Small fix for new meter
    [UI.pde, siweedGUI.pde]
2021-02-12 fixed gear ratios
2021-02-12 fixed last conflict from merge
    [WaveMaker_Controller.ino]
2021-02-25 lab changes and serial fix
    [Interrupts.ino, Serial.ino, Serial.pde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]
2021-03-06 most unit tests fixed
    [Interrupts.ino, Serial.ino, Serial.pde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]
2021-03-08 fixed encoder reading bug
    [WEC_Controller.ino]
2021-03-11 renamed/reworked on-board unit tests
    [UnitTests.pde]
2021-03-11 finished torque to amp conversion. Needs the correct constants before testing
    [Interrupts.ino, WEC_Controller.ino]
2021-03-17 Added Screw Pitch, wave maker ratio, connected encoder to motor in wec
2021-03-25 arduino changed to SI units
2021-03-31 removed .csv s
    [4-13-2020_13-24-5.csv, 4-13-2020_13-25-8.csv, 4-13-2020_13-26-59.csv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]
2021-04-01 fixed and optimized jonswap. Needs stability improvement
    [WEC_Controller.ino, WaveMaker_Controller.ino, siweedGUI.pde]
2021-04-22 fixed map error and improved FFT
    [Serial.pde, UI.pde]
2021-04-22 'fixed' a seastate and unit test bug
    [Serial.pde, WaveMaker_Controller.ino]
2021-04-29 console button, charts, and meter in proper spot
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2021-04-30 added notes to fix data logging
    [dataLogging.pde]
2021-05-06 fixed FFT, a mode setting issue, and small aesthetic changes
    [Meter.pde, Serial.pde, UI.pde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]
2021-05-07 water day changes and test .csv s
    [Beach position test.csv, Torque Steps.csv, hand drive wavemaker.csv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]
2021-05-17 FFT improvements and bug fixes
    [Serial.pde, UI.pde, WaveMaker_Controller.ino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]
2021-05-20 fixed fullscreen renderer issue
    [UI.pde, siweedGUI.pde]
2021-05-28 tau from the arduino now reads from the controller, and is more accurate
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2021-06-16 testing changes
    [Beach position test.csv, Torque Steps.csv, hand drive wavemaker.csv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]
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2021-06-17 bug fixes and setup optimization
    [UI.pde, siweedGUI.pde]
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2021-06-22 paper additions
    [BOM.xlsx]
2021-06-23 flipped FFT and power meter
    [Meter.pde, UI.pde]
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2021-06-30 fixed bugs, still needs work
    [Serial.pde, siweedGUI.pde]
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2021-08-05 various changes, BOM additions
    [BOM.xlsx]
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2021-10-11 Upload SIWEED town CAD model (SOLIDWORKS)
    Uploaded the zip file and the SOLIDWORKS assembly of the same model. The model includes the layout of the city on the platform, the beach, and the whole tank including the mechanical parts and aesthe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
2021-10-12 a couple formatting fixes
2021-11-19 Updated documentation for wave probes and fixed wave probe code
    [Serial.pde, siweedGUI.pde]
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2021-12-03 added seccond, larger moving average to the wave probe graphing to account for drift, and changed plotted probe to probe 2. Also removed debug data plot
    [Serial.pde, UI.pde, siweedGUI.pde]
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2022-04-06 Fixed bug from merge
    [siweedGUI.pde]
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2022-05-17 Fixed checksum to be int based
    [Serial.pde, WEC_Controller.ino, WaveMaker_Controller.ino]
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2022-11-04 move bill of materials (BOM) to CSV
    [BOM.csv, BOM.xlsx]
2022-12-22 added all CAD files
    [Beginner House.SLDPRT, Buoy Part.SLDASM, Countryside house - Copy.SLDPRT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]
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2025-02-07 add OrCAD files
    [DESIGN1.DSN, SIWEED_ELECTRONICS.DSN, SIWEED_ELECTRONICS_AUX_SUBSYSTEMS.DSN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]
2025-02-07 reorganize; add BOM.CSV and OrCAD PDFs to paper
    [BOM.csv, DESIGN1.DSN, SIWEED_ELECTRONICS.DSN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]
2025-05-06 revisions based on 2nd round of reviewer comments
    [6-15-2021_16-47-1.csv, 6-15-2021_16-55-16.csv, 6-15-2021_17-0-32.csv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]
2025-05-16 working on revisions
    [BOM_no_decorations.csv]
2025-05-16 submitted revision to journal
    [BOM_no_decorations.csv]
